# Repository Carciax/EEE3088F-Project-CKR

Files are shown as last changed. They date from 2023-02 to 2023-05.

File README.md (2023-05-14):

# EEE3088F-Project-CKR
#Group number 12
# Students: 
Cameron Clark, CLRCAM007; 
Kian Frassek, FRSKIA001; 
Robert Dugmore, DGMROB001; 

## Table of contents
* Description of HAT
* Getting started
  * Introduction
  * Ordering and assembling a HAT
  * Other hardware requirements
  * Hardware connection
  * Software requirements
  * Basic operation of HAT
  * Licensing

# Description of HAT

This sensor PCB HAT connects to an STM32F0 microcontroller and adds additional sensing functionality in the form of an ambient light sensor, a temperature and humidity sensor, an thermistor, and a potentiometer (which could be connected to some form of mechanical sensing system, e.g., a wind vane). The board can be powered directly from USB, or can be powered by an 18650 battery.

# Getting started

## Introduction

This sensor HAT aims to expand the functionality of an STM32F0 microcontroller by adding various sensors. This getting started guide will go over the minimum hardware and software requirements to connect the HAT and start taking measurements.

## Ordering and assembling a HAT

### Ordering from JLC PCB

The HAT has been designed to meet the specifications from JLC PCB (jlcpcb.com). To order a HAT:
* Go to JLC's website (jlcpcb.com)
* Request a quote
* Upload "Final Submission/GROUP12_gerber.zip" as your gerber files
* Select the board specifications (e.g., colour, finish, etc.) as you like. The default options are a reasonable choice.
* Select the option for single sided assembly
* Follow the website instructions until you are prompted to upload a position file and BOM.
* The position file is "Final Submission/GROUP12_position.cpl", and the BOM file is "FINAL_SUBMISSION/GROUP12_bom.csv".
* When asked about footprints that do not have a part number assigned, select "do not place"
* Follow any further instructions from the website for payment and delivery

### Ordering from another board house

If ordering from JLC PCB is not an option for you, you can use the same gerber, position and BOM files to order your HAT from another board house. However, please note the following:
* The HAT may not meet the specifications of another board house.
* The BOM file is unlikely to be in the correct format for another board house.
* The BOM file is unlikely to contain references to the correct components from another board houses's stock; manual selection of components will probably be necessary.

### Additional steps

All male and female headers will have to be obtained and soldered on separately.

It is also recommended to keep track of the issues page of the github to see if there are any outstanding hardware issues with the current iteration of the HAT, which may require manual intervention to solve. 

## Other hardware requirements

### List of required hardware

In addition to the HAT, the following hardware is required:
* an STM32FO microcontoller, with pins connected to 2 1x24-pin male headers spaced -1.524 mm (0.6 in) apart
* A microUSB-B cable
* A 5V USB power supply
* Optional: An 18650 battery
* A computer with an available USB port running Linux or Windows

## Hardware connection

### Microcontroller

The microcontroller should be directly connected to the double-row of females headers labelled "J3". 

### Battery

The 18650 battery (if being used) can be placed directly into the battery holder, taking care to connect it with the correct polarity. The HAT will automatically cut battery power if the voltage drops too low, to protect the battery.

### USB (power supply and data transfer)

The HAT is powered (and the battery is charged) immediately when 5V power is received from the singular USB port. Connecting the USB to a computer enables the start of data transfer to the computer.

### Battery charging

The 18650 battery is charged by the 5V USB power supply. 
The HAT includes red and green charging LEDs. The red LED is powered when the battery is charging, and the green LED is powered when the battery is fully charged.

## Software requirements

### STM32F0 Firmware

The firmware from this repository takes measurements from all sensors at a soft-configurable regular interval. This will need to be uploaded to STM32F0 board.

### Required PC software

The default firmware outputs value over USB serial and requires no additional software.

## Basic operation of HAT

### Reading data on the pc

Data is saved to the EEPROM by default. To send all EEPROM data over the USB connection:
* Connect the USB
* Press switch 1
* LED 1 will flash until all data has been sent
* To abort, press switch 1 again.

### Configuring data read rate

Under normal operation, the HAT takes 1 reading every 60 seconds. This can be soft-configured as follows:
* Press switch 2
* LED 2 will start to flash
* Turn the potentiometer to a desired reading level
* Press 2 again to confirm

## Licensing
MIT License

Copyright (c) 2023 Kian Frassek, Cameron Clark, Robert Dugmore

Permission is hereby granted, free of charge, to any person obtaining a copy
of this software and associated documentation files (the "Software"), to deal
in the Software without restriction, including without limitation the rights
to use, copy, modify, merge, publish, distribute, sublicense, and/or sell
copies of the Software, and to permit persons to whom the Software is
furnished to do so, subject to the following conditions:

The above copyright notice and this permission notice shall be included in all
copies or substantial portions of the Software.

THE SOFTWARE IS PROVIDED "AS IS", WITHOUT WARRANTY OF ANY KIND, EXPRESS OR
IMPLIED, INCLUDING BUT NOT LIMITED TO THE WARRANTIES OF MERCHANTABILITY,
FITNESS FOR A PARTICULAR PURPOSE AND NONINFRINGEMENT. IN NO EVENT SHALL THE
AUTHORS OR COPYRIGHT HOLDERS BE LIABLE FOR ANY CLAIM, DAMAGES OR OTHER
LIABILITY, WHETHER IN AN ACTION OF CONTRACT, TORT OR OTHERWISE, ARISING FROM,
OUT OF OR IN CONNECTION WITH THE SOFTWARE OR THE USE OR OTHER DEALINGS IN THE
SOFTWARE.

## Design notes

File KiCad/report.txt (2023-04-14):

Info: Reading netlist file 'C:\Users\Kian\OneDrive - University of Cape Town\Desktop\uct\3 year\frirst semester\EEE3088\EEE3088F-Project-CKR\KiCad\report.net'.

Info: Using reference designators to match symbols and footprints.

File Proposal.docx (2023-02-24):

1) The HAT will be used as a low power temperature sensor which can be used to log temperatures and give alerts when the temperature exceeds or goes below configurable threshold temperatures.

The attachments will be a digital temperature sensor, a potentiometer and basic I/O (LEDs and pushbuttons). The HAT will also include additional breakout pins which users can connect additional output devices to (for temperature alerts), and which will allow connection to a device that logs temperatures.

The device could be used in a variety of situations, including personal weather logging, home agriculture, machinery/manufacturing temperature monitoring, student research, and office monitoring.

The potentiometer will be used for configuration of the device, such as to set threshold temperatures and change sensor frequency.

User/Use case | User Description
Personal weather monitoring | Someone who wants to keep track of the temperature in their own home over time, or who want to be alerted when certain temperatures are reached
Requirements | More detail
Configurable "alert" temperature | Ability to change the temperature level/s at which the board will send an "alert" signal
Basic output for configuration | LEDs on the board that allow visual feedback for the u
Breakout pins for additional "alert" output | User might want to connect an aditional/different output for temperature alerts, e.g. a buzzer or a switch for an alarm

User/Use case | User Description
Agriculture | Monitoring of a home greenhouse or houseplants
Requirements | More detail
Ability to mount a case | Requires mounting holes so that user can add a protective case, e.g. to protect from moisture in a greenhouse
Temperature logging | Requires an output that users can connect to a storage device to log temperature over time

User/Use case | User Description
Machinery/Manufacturing | Monitoring of a workspace containing temperature sensitive machinery
Requirements | More detail
Breakout pins for additional "alert" output | Users may want to configure the board to automatically take some action upon temperature "alert", e.g., turn on additional room cooling
Temperature logging | Same as above
Highly configurable "alert" levels | Machinery may need to take actions at many different temperature levels, e.g., turn fans up or down

User/Use case | User Description
Research | E.g., a student doing a project tracking temperatures in a remote location
Requirements | More detail
Temperature logging | Same as above
Power efficient | Researchers may need to leave the device running for a long time without charging/manual intervention
Breakout pins for additional "alert" output | Same as above

User/Use case | User Description
Office monitoring | E.g., to track temperature alongside separate tracking of energy usage from fans/airconditioning
Requirements | More detail
Temperature logging | Same as above

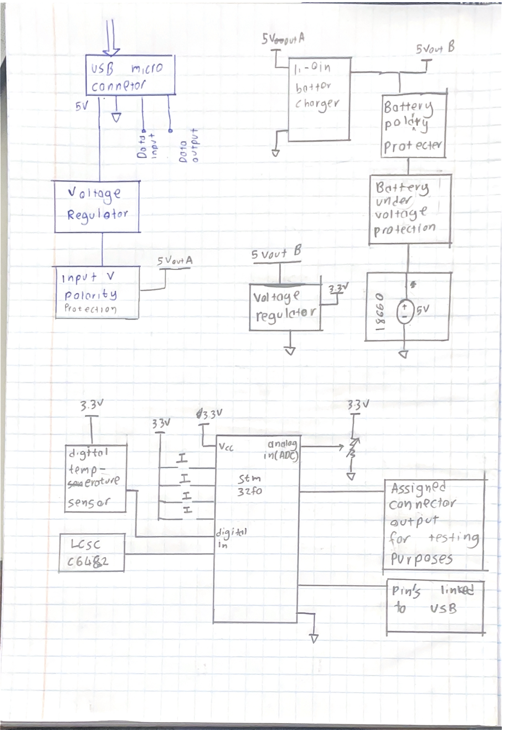
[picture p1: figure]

4) https://github.com/Carciax/EEE3088F-Project-CKR

EEE3088F Project Proposal 24 Feb 2023 CLRCAM007 FRSKIA001 DGMROB001

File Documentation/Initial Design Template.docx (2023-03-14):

Q1: GitHub

https://github.com/Carciax/EEE3088F-Project-CKR

Q2: Power Subsystem Failure Management

i) I am going to put 0 ohm resistors over each component so that we can use the available connections points to bypass any broken components. I have put pins to connect an external 3V3 power source.

ii) I will ensure to use the correct size to the appropriate current rating for each track to protect against track damage.

I will also make the ground track thick.

iii) I will provide other options to replace components or go and buy the components from other shops and solder them on. I will also ensure to use components with large quantities of stock decreasing the chance of the component running out.

iv) I will make the circuit as modular as possible allowing for changes to the circuit as well as providing lots of available connection points to make modifications post PCB development.

Q3: Sensing Subsystem Failure Management

Each I/O trace will be connected to two separate pins on the microcontroller. Each trace will have a 0Ω resistor between the sensor pin and the microcontroller pin, but one of these 0Ω resistors will be DNP. This will allow a different microcontroller pin to be used in the event that one fails. These connections are shown on the microcontroller schematic.

The l main power line will also be populated with a 0Ω, to allow the entire module to be disconnected from power in the instance that a design error and/or circuit damage within the sensor module leads to a short.

If the 0Ω resistors have to be de-soldered, their pads can be used to solder a wire directly to another pin on the microcontroller.

Finally, the design includes 2 analogue sensors (a potentiometer which can be connected to some small mechanical device, and a thermistor), and 2 digital sensors (an ambient light sensor and a temperature/humidity sensor). Best case scenario, this means that the HAT is multi-faceted and can serve a variety of different research purposes. However, in the event of of component/design failure or inadequate component stock, the HAT will hopefully still have other functioning sensors and thus will still be useful. It is specifically useful that there are 2 different temperature sensors, given that our original examination of use cases for the HAT placed on a strong emphasis on the HAT’s ability to sense temperature.

Q4: Microcontroller Subsystem Failure Management

For individual component failure, components will be connected into the circuit by some means that it can be disconnected. Components that are likely to fail will get jumpers which can be easily remove and another component can be connected from an external board.

Components that are less likely to fail will get two pads soldered together in line with the component. These can easily be soldered and de-soldered, and the signal can be measured in that line. Lastly, components that are likely never going to fail will get 0Ω resistors which can be taken out and/or rerouted to other lines.

Power and controls:

The power and ground of the microcontroller has solder pads in place to ensure that the microcontroller can function without the power and sensors. The debugger input is already a pin header and thus can be plugged – which also means that the NSRT reset pin has a pin header that can be easily accessed to reset the microcontroller. There are enough redundant push buttons that failure management is unnecessary. The BOOT0 or boot mode pin has a solder pad in case the board needs to be booted in a different mode.

Sensors and EEPROM:

The digital sensors inputs and the EEPROM communication lines have 0Ω resistor pairs in place such that they can change between I2C1 and I2C2 communication protocol, and so that there are a pair of lines available for isolated testing of components. The analogue sensors have 0Ω resistor pairs such that they can change between GPIOA and GPIOB reading the value.

Output:

The output USB has a 3 pin header on both Tx and Rx lines such that the USB can be changed between UART1 and UART2 as well as the board can communicate with an external USB setup in case the onboard USB port or differential pair lines to UART chip are damaged. The LED has also been wired with a jumper such that an output signal can be jumped to an external board.

This system of failure management allows for most components to be isolated for testing, redirected in case of line damage, or have signals inputted or outputted to an external board for testing.

Q5: Power Subsystem Schematic

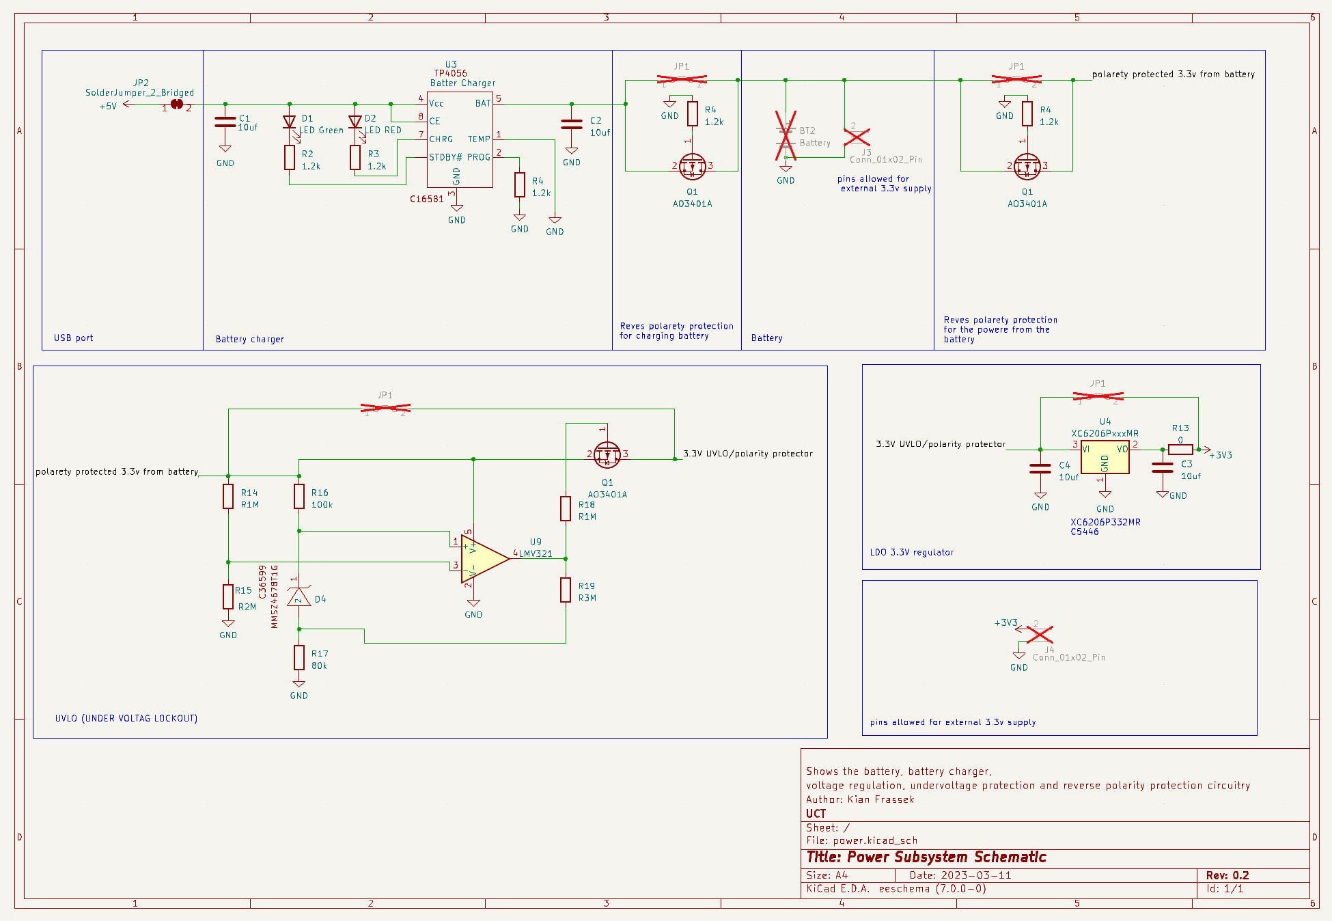
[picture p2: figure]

Q6: Sensing Subsystem Schematic

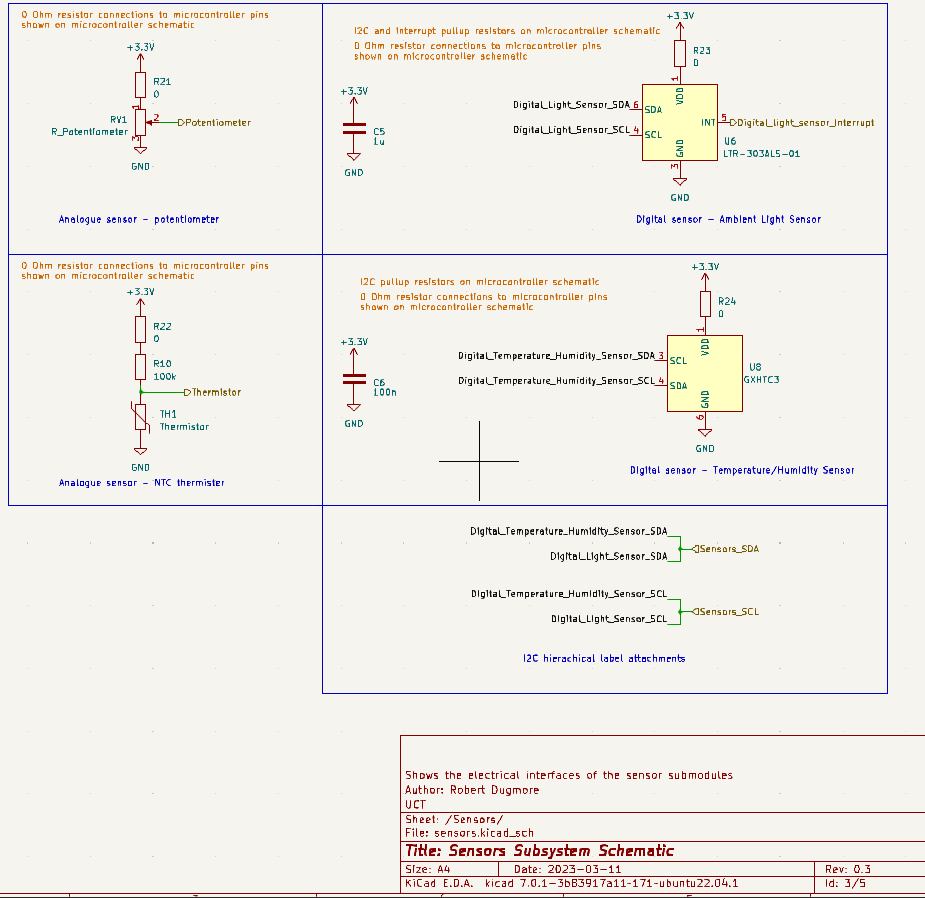
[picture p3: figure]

Q7: Microcontroller Subsystem Schematic

The microcontroller schematic

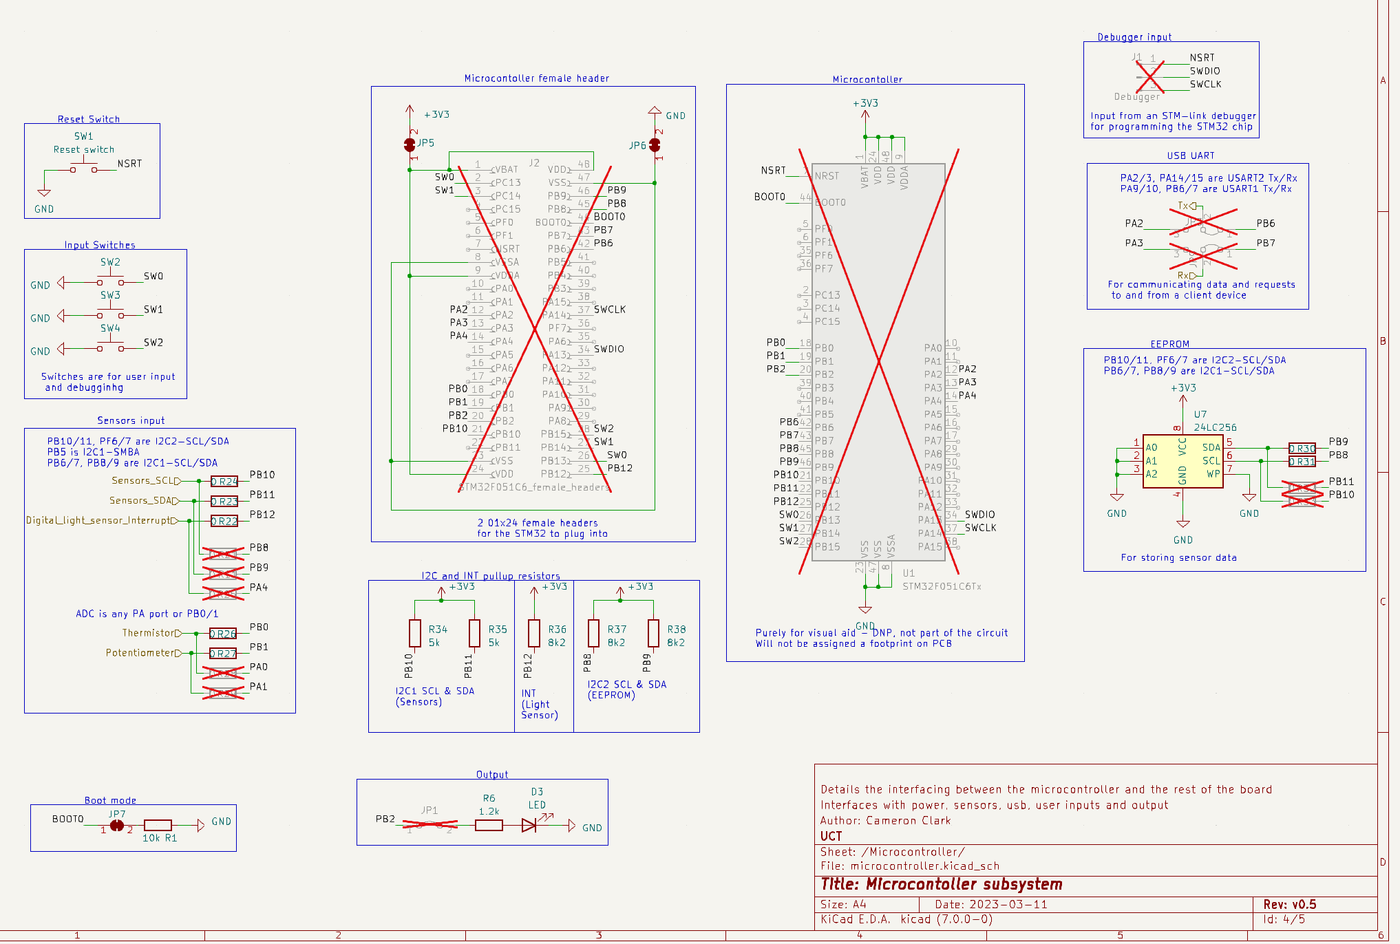
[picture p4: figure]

The USB input schematic

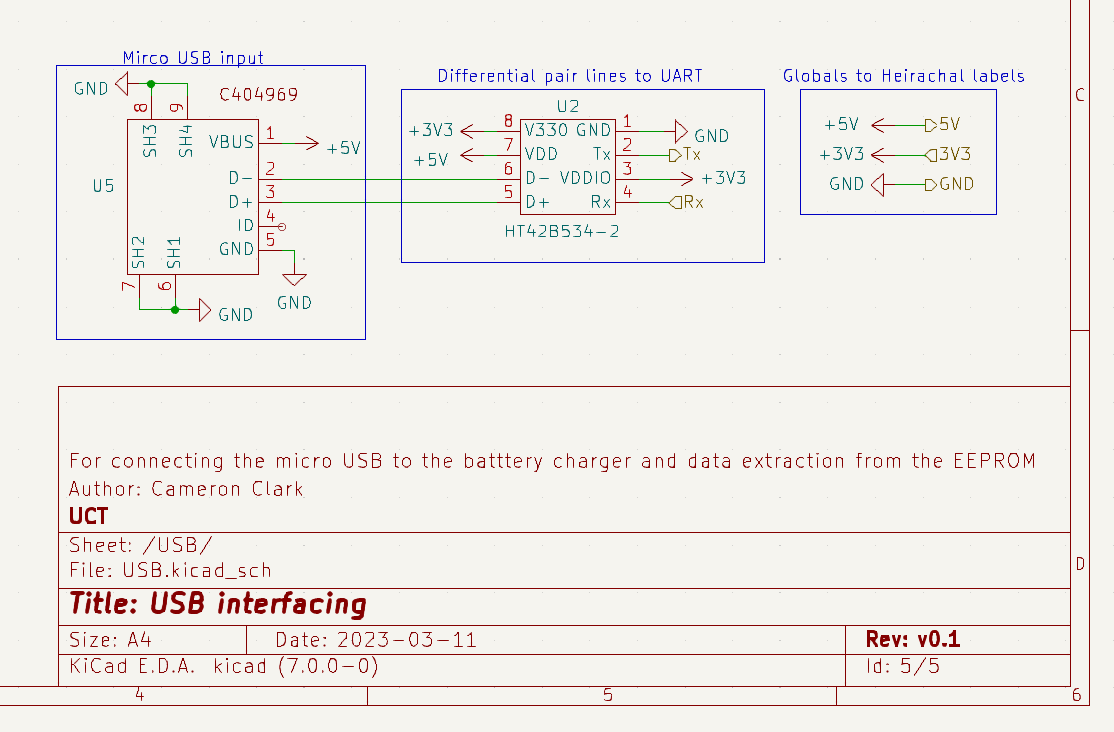
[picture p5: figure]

Q8: Planned ERCs

- Make sure the 5V and 3V3 and GND labels aren’t short circuit to each other.
- Make sure there are no floating pins.
- Make sure the power running through resistor doesn’t exceed their maximums.
- Make sure power lines do not go through traces that are too thin.
- Perform the ERC on KiCad.
- Follow all the rules on JCL components specification for board design.

Q9: Updated BOM

https://github.com/Carciax/EEE3088F-Project-CKR/blob/main/Budgeting/Budgeting.xlsx

CLRCAM007 FRSKIA001 DGMROB001

EEE3088F-Project 11 Mar. 23

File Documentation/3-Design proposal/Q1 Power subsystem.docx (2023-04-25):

I Kain frassek declare I did not plagiarize to get any of this information in section 1.

Week 3

Q 1.1

Specification

USB input | This must be a micro-USB input. It must be able to output between 4.5 and 5.5 volts which can then be used to charge the battery. It will need to be able to withstand high temperatures such as up to 80 degrees Celsius.
battery charger | The battery charger must be able to take the 5 Volt voltage source from the micro USB and charge the battery. It will indicate when the battery is fully charged using a green LED and when the battery is still charging using a red LED. It must also be able to withstand temperatures up to 80 degrees.
Undervoltage lockout | This must be connected to the lithium-ion battery. It must ensure that if the voltage provided by the battery goes below 3.3 volts no voltage is provided to the main circuit.
Battery | This must be a lithium ion battery that fits into the BH-18650-B1BA002 (https://jlcpcb.com/partdetail/Myoung-BH_18650B1BA002/C2988620) holder. It must be a 3.3 Volt battery. It must be able to withstand temperatures around 80 degrees Celsius.
Battery terminal pins | These need to be 2 pins that can be used to provide 3.3 volts to the main circuit in case the battery is not available or for testing purposes.
Reverse polarity protection circuits | This must be connected to the battery. It must be able to detect whether the batteries polarity has been swapped or if the polarity at which the battery is being charged is in the wrong direction. If the polarity in either case has been swapped it must prevent the main circuit and battery, from being powered or charged by this voltage.
3.3 Volt regulator | This circuit must be able to take the voltage from the battery which will be 3.3 volts or higher and regulate it so that a constant 3.3 volts is supplied. This can then be used to power our circuit reliably.

Q1.2

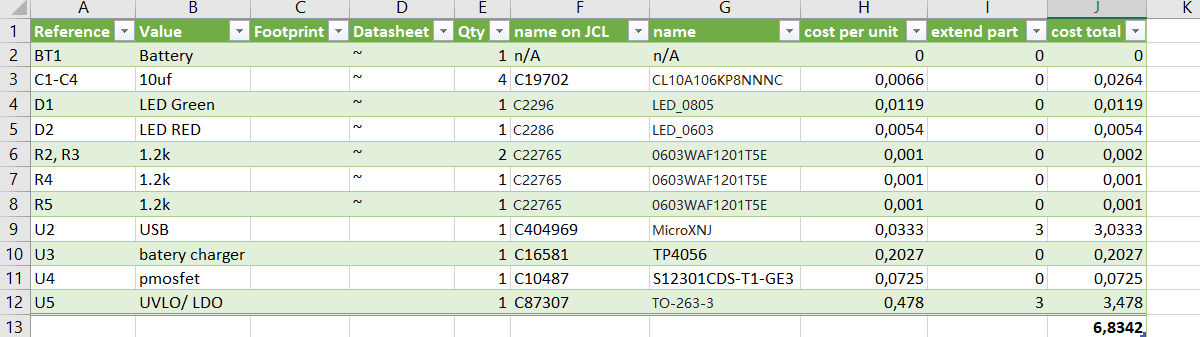
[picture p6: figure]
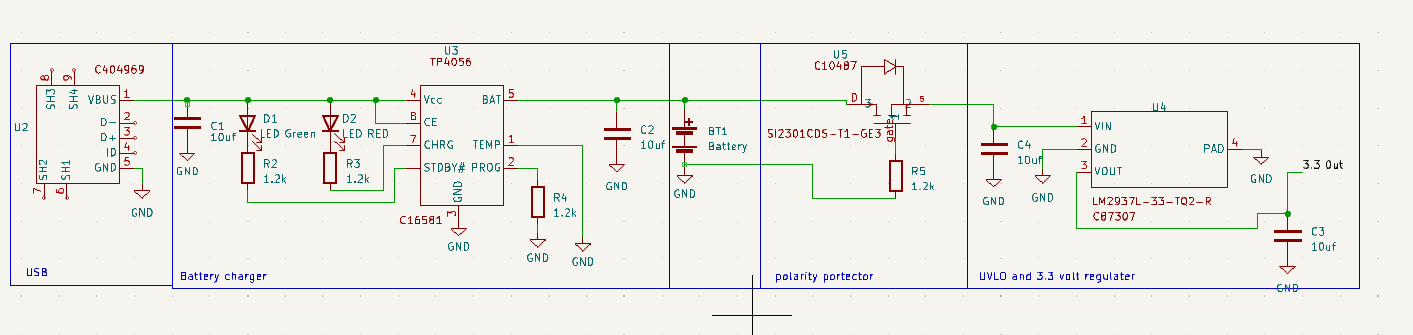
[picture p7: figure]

Q.1.3

Submodule interface

LED is used to indicate the charging of the battery. | one green LED and one red LED. Both in series with 1.2 KΩ resistors to reduce current.
STM32F051C6Tx | This is the main microprocessor board which will need to be supplied with 3.3 volts. current used to power itself is between 3 and 4.5 milliamps.
Potentiometer analog sensor | This will be supplied with 3.3 volts and will act as a voltage divider. It will draw 33 milli amps of power.
digital light sensor | This will be supplied 3.3 volts. And will draw a very low current.
Outputs via LED | There will be an LED powered by the 3.3 volts which can be used to flash at different rates and help give outputs about what has been sensed. These LED's will be put in series with large resistors to help reduce current.
Debug (SIL 1x10 Male) | This will need a 5 Volt power supply and therefore it will need to be supplied straight from the USB port.
Analogue sensor 2 thermister | This will need 3.3 V power supply and should draw les that 1 mw of power.
USB connector | Will supply 5V to the main power circuit. An external USB cable will be connected to provide this power and for data transmission

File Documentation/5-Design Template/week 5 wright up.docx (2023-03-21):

# Week 5: PCB design template

Q1: Github

https://github.com/Carciax/EEE3088F-Project-CKR

Q2: Power subsystem failure management

i) Going to put populate zero ohm resistance in series with each modular component and unpopulated zero ohm resistor over each modular component allowing me to bypass each modular component by desoldering the populated 0 ohm resistor and resoldering the unpopulated resistor. I'm also going to put lots of test points which are going to be through holes which give me the ability to connect wires later on. I will also put jumpers next to the battery and at the 3V3 out and ground allowing us to connect an external 3.3 volts either in place of the battery or just to the main circuit.

ii) I will ensure to use the correct size track to the appropriate current rating for each track to protect against track damage.

I will also make the ground track thick as well as making ground its own level on the board.

iii) I will provide other options to replace components or go and buy the components from other shops and solder them on. I will also ensure to use components with large quantities of stock decreasing the chance of the component running out.

iv) I will make the circuit as modular as possible allowing for changes to the circuit as well as providing lots of available connection points to make modifications post PCB development.

The plans for failure management for this subsystem were unchanged; the update schematic below implements these plans.

Q3: Sensing subsystem failure management

i)

Each I/O trace will be connected to two separate pins on the microcontroller. Each trace will have a 0Ω resistor between the sensor pin and the microcontroller pin, but one of these 0Ω resistors will be DNP. This will allow a different microcontroller pin to be used in the event that one fails. These connections are shown on the microcontroller schematic.

This was implemented as described.

ii)

The l main power line will also be populated with a 0Ω, to allow the entire module to be disconnected from power in the instance that a design error and/or circuit damage within the sensor module leads to a short.

Since the previous schematic revision, PMOSFET switches were added to allow each sensor’s power supply to be individually controlled. Populated 0 ohm resistors were placed at the power supply of each PMOSFET, and DNP 0 ohm resistors that bypass the PMOSFETS and power the sensors directly were added, to account for errors or failure in the switching circuits.

iii)

If the 0Ω resistors have to be de-soldered, their pads can be used to solder a wire directly to another pin on the microcontroller.

Through-hole test points were added to the schematic; these enable easy testing of the circuit and are easier to manually solder wires to than 0 ohm resistor pads.

iv)

Finally, the design includes 2 analogue sensors (a potentiometer which can be connected to some small mechanical device, and a thermistor), and 2 digital sensors (an ambient light sensor and a temperature/humidity sensor). Best case scenario, this means that the HAT is multi-faceted and can serve a variety of different research purposes. However, in the event of of component/design failure or inadequate component stock, the HAT will hopefully still have other functioning sensors and thus will still be useful. It is specifically useful that there are 2 different temperature sensors, given that our original examination of use cases for the HAT placed on a strong emphasis on the HAT’s ability to sense temperature.

This was able to be implemented within budget and thus was kept. The PMOSFET power switches described previously minimise the additional power draw brought about by having additional sensors.

Q3: Microcontroller interfacing failure management

For individual component failure, components will be connected into the circuit by some means that it can be disconnected. Components that are likely to fail will get jumpers which can be easily remove and another component can be connected from an external board.

Components that are less likely to fail will get two pads soldered together in line with the component. These can easily be soldered and de-soldered, and the signal can be measured in that line. Lastly, components that are likely never going to fail will get 0Ω resistors which can be taken out and/or rerouted to other lines.

It was decided to consistently use 0 ohm resistors instead of jumpers or solder pads. The 0 ohm resistors were chosen with a large physical size such to make manual soldering and de-soldering easier.

Power and controls:

The power and ground of the microcontroller has solder pads in place to ensure that the microcontroller can function without the power and sensors. The debugger input is already a pin header and thus can be plugged – which also means that the NSRT reset pin has a pin header that can be easily accessed to reset the microcontroller. There are enough redundant push buttons that failure management is unnecessary. The BOOT0 or boot mode pin has a solder pad in case the board needs to be booted in a different mode.

Besides the decision described above to use 0 ohm resistors instead of jumpers or solder pads, this was implemented as described.

Sensors and EEPROM:

The digital sensors inputs and the EEPROM communication lines have 0Ω resistor pairs in place such that they can change between I2C1 and I2C2 communication protocol, and so that there are a pair of lines available for isolated testing of components. The analogue sensors have 0Ω resistor pairs such that they can change between GPIOA and GPIOB reading the value.

This was implemented as described.

Output:

The output USB has a 3 pin header on both Tx and Rx lines such that the USB can be changed between UART1 and UART2 as well as the board can communicate with an external USB setup in case the onboard USB port or differential pair lines to UART chip are damaged. The LED has also been wired with a jumper such that an output signal can be jumped to an external board.

USB/UART connections were implemented as described. The LED connection was changed from a jumper to a 0 ohm resistor. A through-hole test point was added which will allow a wire to be manually soldered if the connection needs to be jumped to another board. A second LED was also added in case of LED failure.

This system of failure management allows for most components to be isolated for testing, redirected in case of line damage, or have signals inputted or outputted to an external board for testing.

Q5: Power subsystem schematic

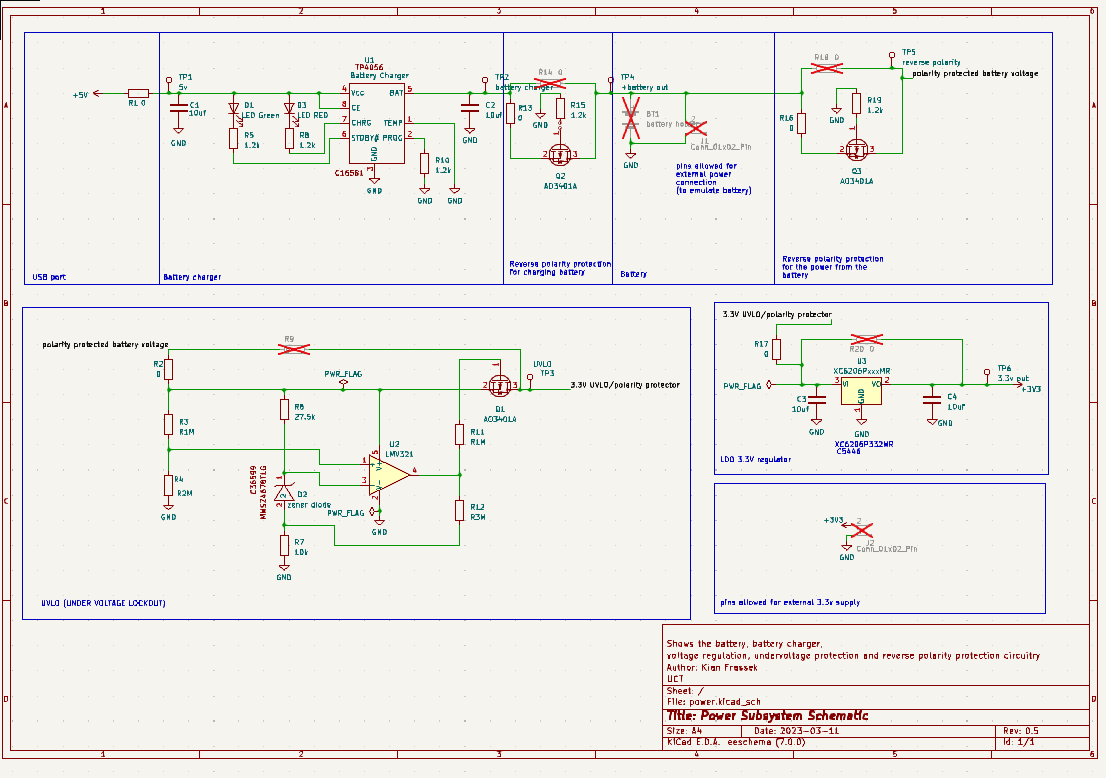
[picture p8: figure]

Some changes were made to resistance values as they were wrong. Test points were added throughout the circuit which will provide opportunities to test as well as solder on wires if needed. I have also added unpopulated and populated 0 ohm resistors over each modular component so that we can remove and add modular components as we want.

Q6: Sensing subsystem schematic

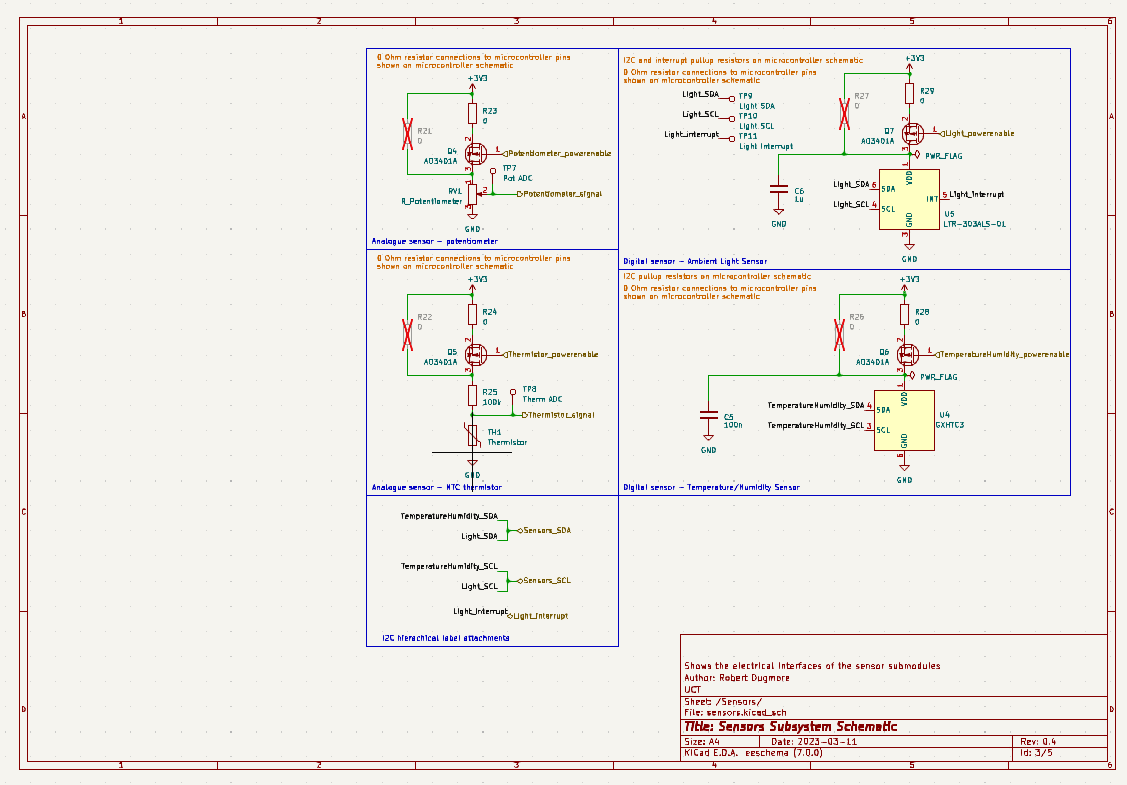
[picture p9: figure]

PMOSFET switching circuits were added to each sensor to allow the power to be enabled or disabled individually.

Test points were added to allow testing of the circuit or allow wires to be manually soldered between various components if necessary.

DNP 0 ohm resistors bypassing the PMOSFET switches were added to allow direct powering of sensors if necessary.

Net labels were renamed for clarity.

Q7: Microcontroller interfacing schematic

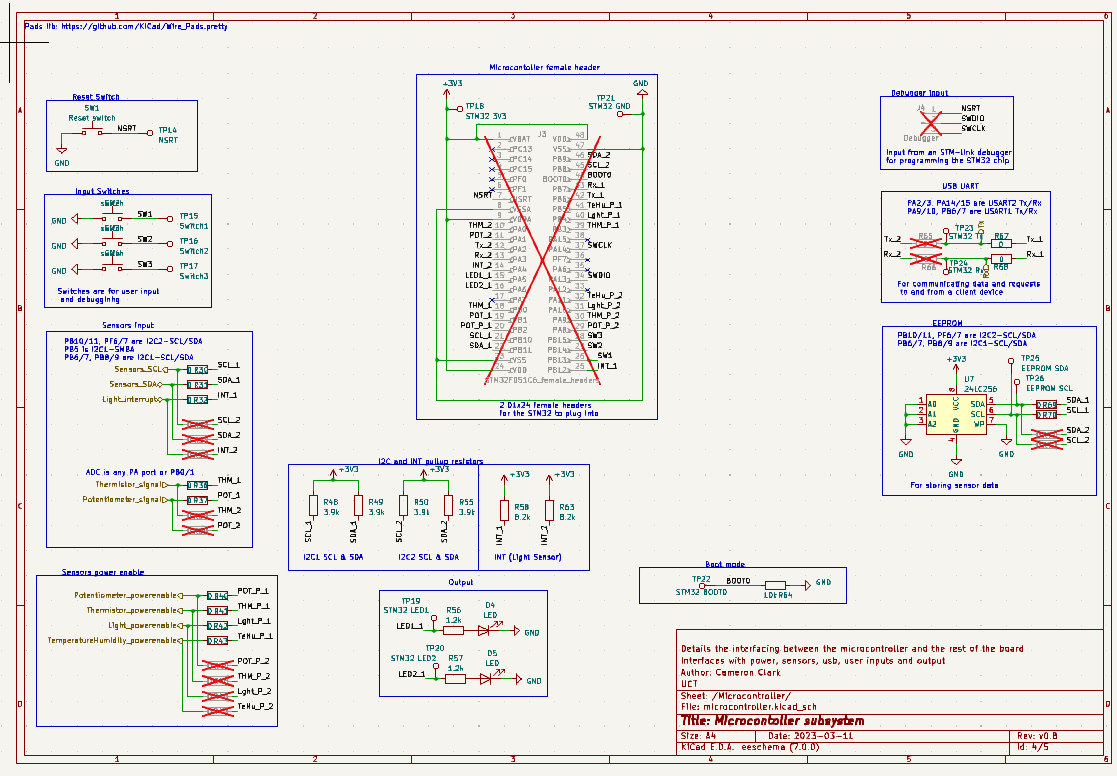
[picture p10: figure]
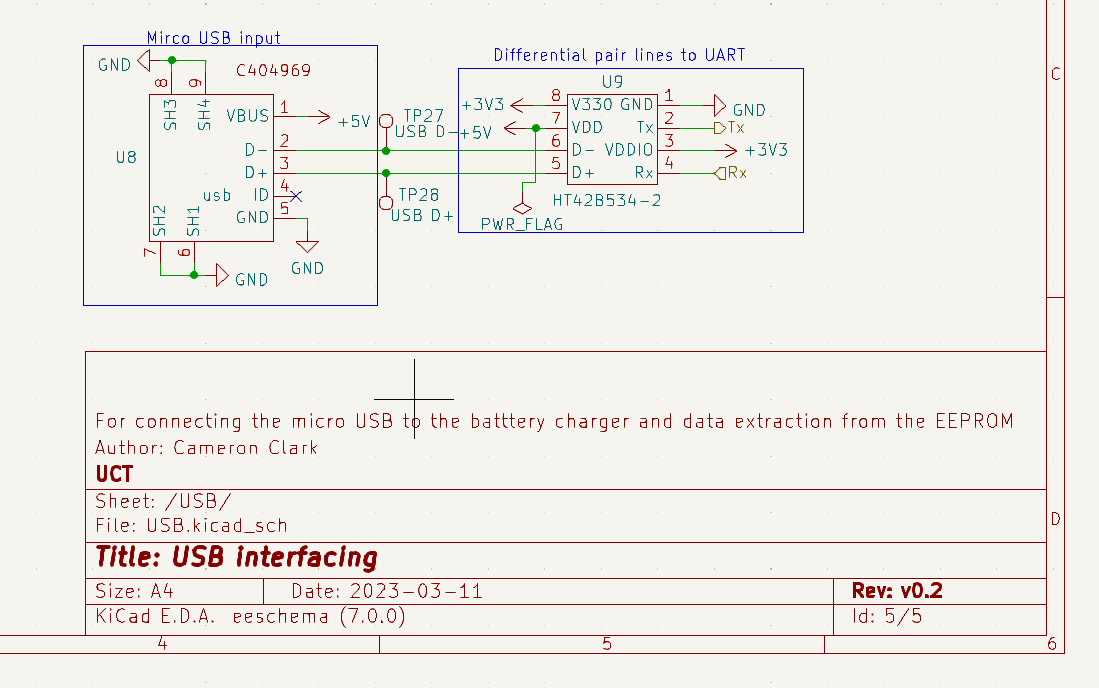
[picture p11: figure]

Connections to the PMOSFET switches on the sensors subsystem were added to allow the sensor power to be enabled/disabled via GPIO.

The failure management system was updated to use exclusively 0 ohm resistors instead of a mixture of these and jumpers/solder pads.

Test points were added to allow testing of the circuit or allow wires to be manually soldered between various components if necessary.

EEPROM was connected to I2C1 by default (instead of I2C2), and I2C pullup resistances were recalculated and changed.

Previously a component diagram of the actual micrcontroller board had been included for visual reference – this was removed entirely.

A second output LED was added.

Net labels were renamed for clarity.

Q8: Updated ERCs

ERCs used were:

- Make sure the 5V and 3V3 and GND labels aren’t short circuit to each other.
- Make sure there are no floating pins.
- Make sure the power running through resistor doesn’t exceed their maximums.
- Make sure power lines do not go through traces that are too thin.

Screenshot of ERC report with no errors:

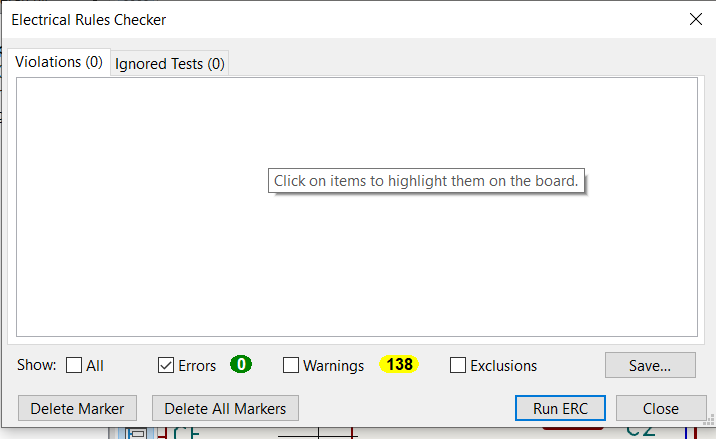
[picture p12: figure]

The 138 warnings are because a large number of wires in the schematic are off-grid.

Q9: DRCs

DRCs used were:

Minimum distance between tracks

Check that all pads are connected to the correct nets

Check for thermal violations (GND pins must be connected to the GND plane with at least 2 spokes)

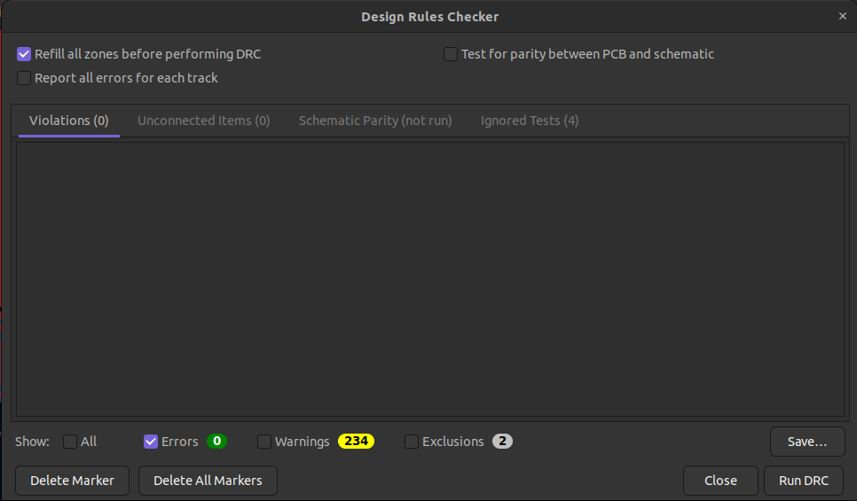
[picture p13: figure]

The 2 exclusions were:

- A GND pin on an IC that was unable to be connected to multiple GND spokes due to the physical layout of the IC pins
- A GND pin on the microcontroller header which was flagged for only connecting to 1 GND spoke on front copper even though it was connected to 2 spokes on the back copper.

The warnings were silkscreen overlaps and were not of concern.

Q10: BOM

https://github.com/Carciax/EEE3088F-Project-CKR/blob/main/Budgeting/EEE3088F_CKR.csv

The estimated budget (exlcluding manufacturing cost) is $56.50. We are account for an ~$12.00 manufacturing cost (board and assembly), and thus are still within our budget.

Q11: PCB design

Front copper layer:

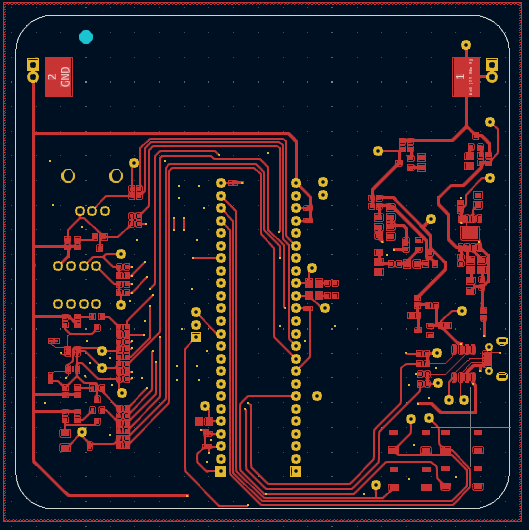
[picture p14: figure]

Front copper layer with GND plane shown:

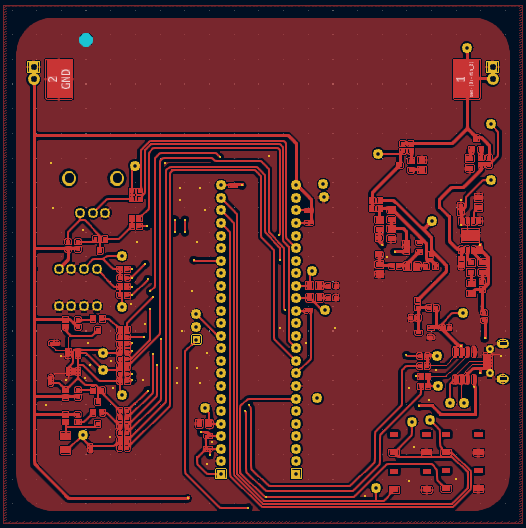
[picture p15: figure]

The lightly-shaded area is the GND plane.

0.6mm tracks were used for power lines, 0.4mm tracks were used elsewhere. For some ICs with small pads, 0.25mm tracks were used in small sections.

Back copper layer:

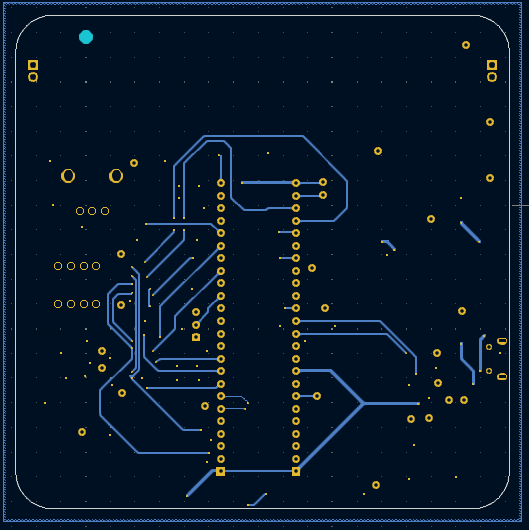
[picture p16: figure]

Back copper layer with GND plane shown:

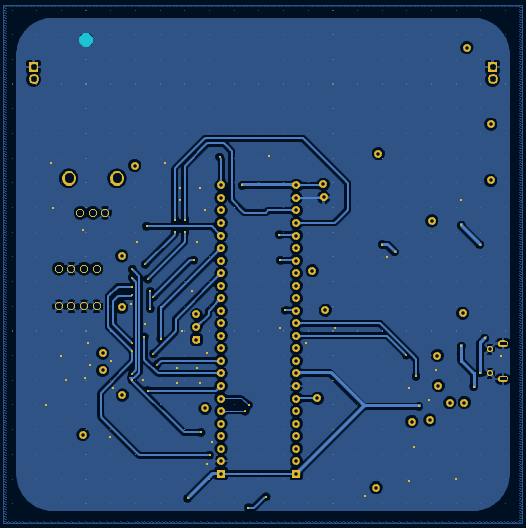
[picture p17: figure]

The lightly-shaded area is the GND plane.

0.6mm tracks were used for power lines, 0.4mm tracks were used elsewhere. For some ICs with small pads, 0.25mm tracks were used in small sections.

Front silkscreen:

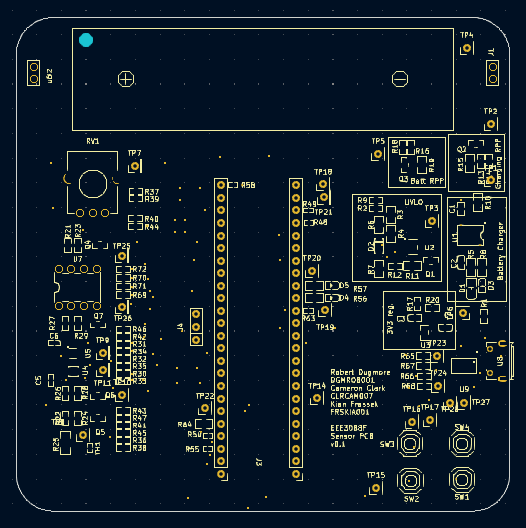
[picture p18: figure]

Note that the USB was intentionally allowed to stick slightly off the edge of the board to make it easy to plug in to.

Back silkscreen has not been shown as it was left empty.

All layers shown:

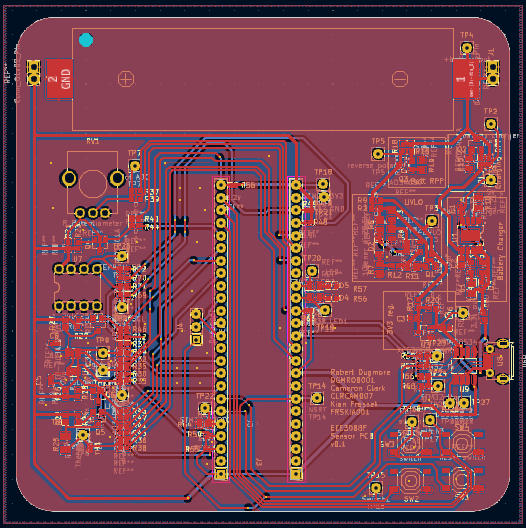
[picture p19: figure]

3D view:

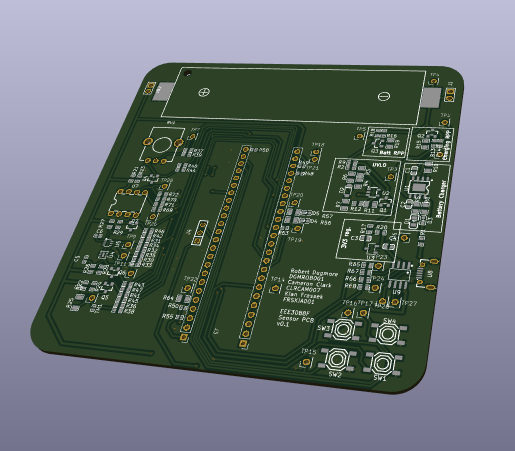
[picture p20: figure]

Link to gerber files:

https://github.com/Carciax/EEE3088F-Project-CKR/blob/main/Gerbers

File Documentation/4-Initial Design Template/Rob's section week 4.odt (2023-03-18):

Each I/O trace will be connected to two separate pins on the microcontroller. Each trace will have a 0Ω resistor between the sensor pin and the microcontroller pin, but one of these 0Ω resistors will be DNP. This will allow a different microcontroller pin to be used in the event that one fails. These connections are shown on the microcontroller schematic.

The l main power line will also be populated with a 0Ω, to allow the entire module to be disconnected from power in the instance that a design error and/or circuit damage within the sensor module leads to a short.

If the 0Ω resistors have to be de-soldered, their pads can be used to solder a wire directly to another pin on the microcontroller.

Finally, the design includes 2 analogue sensors (a potentiometer which can be connected to some small mechanical device, and a thermistor), and 2 digital sensors (an ambient light sensor and a temperature/humidity sensor). Best case scenario, this means that the HAT is multi-faceted and can serve a variety of different research purposes. However, in the event of of component/design failure or inadequate component stock, the HAT will hopefully still have other functioning sensors and thus will still be useful. It is specifically useful that there are 2 different temperature sensors, given that our original examination of use cases for the HAT placed on a strong emphasis on the HAT’s ability to sense temperature.

Temperature & humidity sensor: C2837688

What did you do in the past week?

- Added a temperature/humidity sensor to the sensor schematic

- Revamped net labelling system on schematics

- Error-checked and assisted other team members with the power and microcontroller submodules

What do you plan to do in the coming week?

- A bulk amount of the PCB design, given that I enjoy it and have had less work than the others so far

- A budget review to make sure we can actually afford all the sensors

- Any necessary final edits to the schematics

What might prevent you from doing things?

- Very busy next week (tests). Can mitigate with good time management

- Load shedding makes working difficult. Will plan around the load shedding schedule.

- Budget constraints might require some minor sensor submodule redesign. Will plan this in in case it is necessary.

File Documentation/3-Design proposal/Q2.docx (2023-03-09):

I, Cameron Clark, declare I did not plagiarize to get any of this information in section 2.

Q2.1

Microcontroller specifications. It must be able to:

- Receive 3v3 of voltage into pins 1, 9, 24, 28.
- Connect to ground on pins 8, 23, 47.
- Not exceed an input voltage of 4V
- Not exceed an input or output current of 25mA.
- Receive an input into pin 7 (NSRT) to reset and run the loaded program.
- Receive inputs into pins 7, 34, 37 (NSRT, PA13, PA14) for programming the chip using the debugger.
- Receive a grounded input into pin 44 (BOOT0) to configure the boot mode of the chip.
- Output 3V3 to a GPIO pin
- Receive a read using an ADC a variable voltage.
- Receive data through an IC1/2 enabled pin.

Q2.2

BOM

https://github.com/Carciax/EEE3088F-Project-CKR/tree/main/Budgeting/BOM.xlsx

Components for the microcontroller are indexed 6, 7, 8, 12 and 13 which are an LED, 01x03 male connector, 10k resistor, a button, and the 2 01x24 female headers.

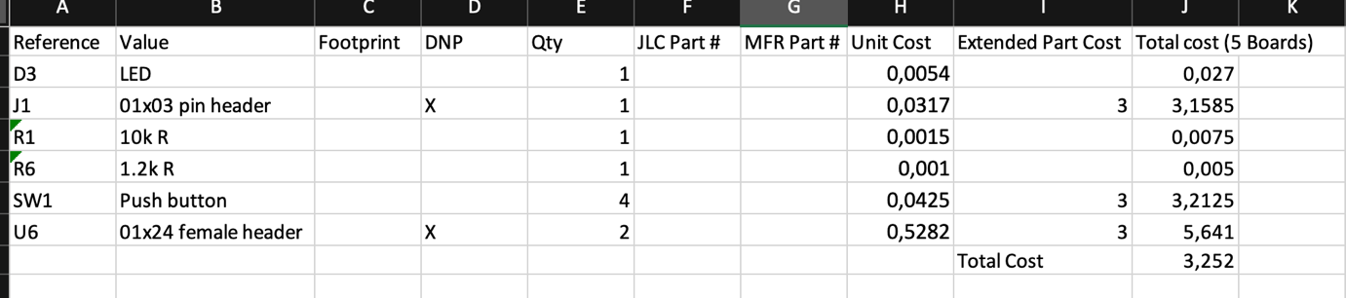
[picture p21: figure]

Total cost estimated as $3.25.

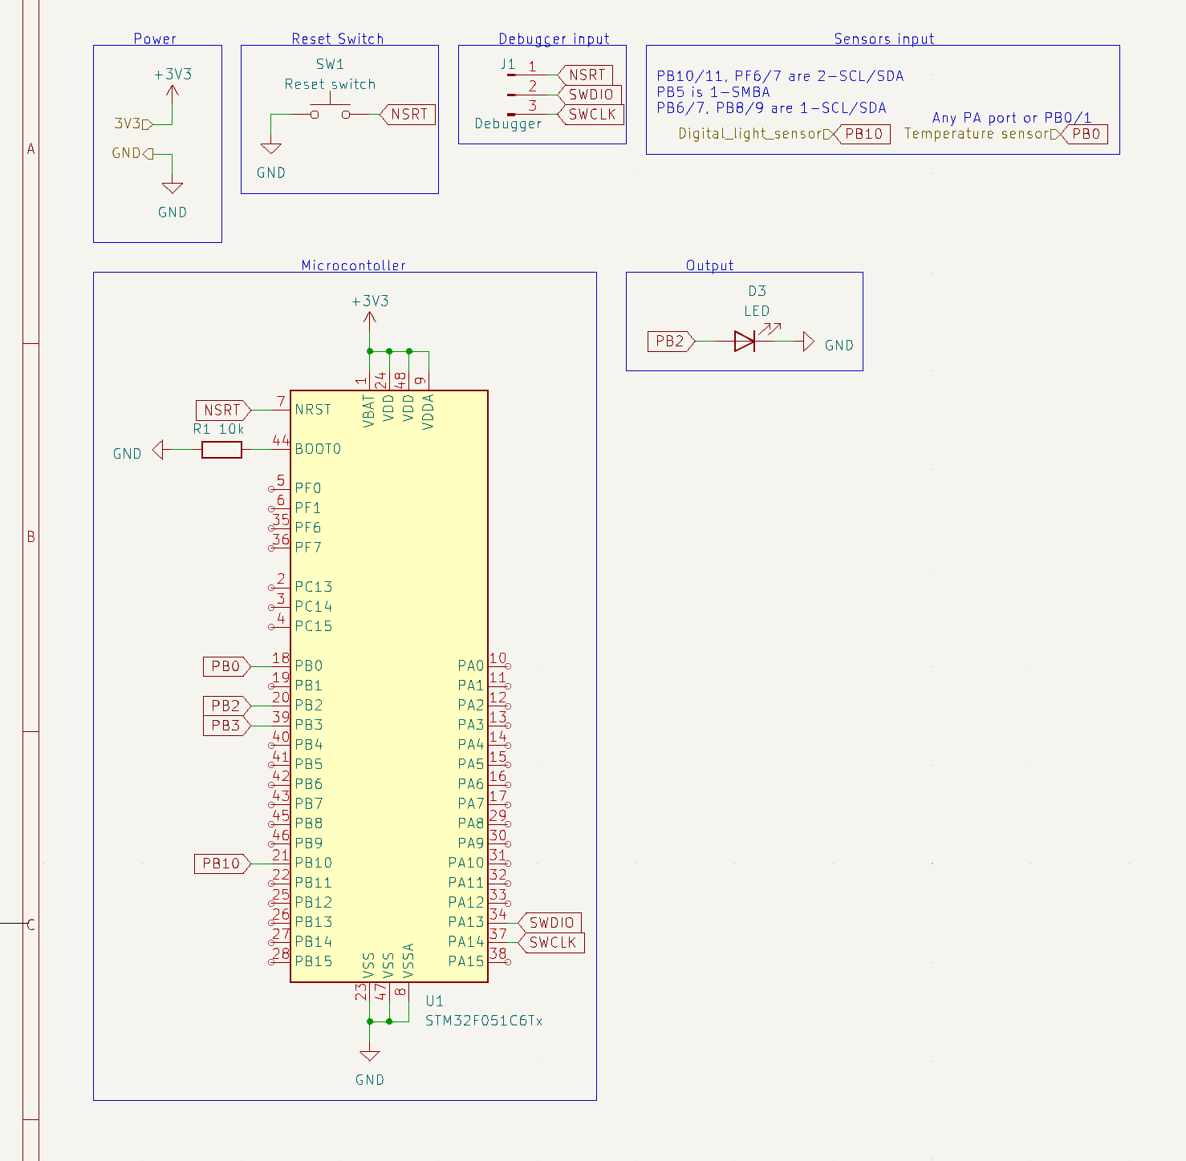
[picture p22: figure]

Q2.3

Inputs

A push button will be used as a reset switch receive by the NRST pin 7. This will have a pulldown resistor internally configured. It will be used to start the program in the machine.

It should receive a 3V3 volts from the power module and a max current of 4.5mA

Sensors

This module will receive a voltage from a thermistor in the range of 0 – 3V3. It will use an GPIOA pin or GPIOB pin 0/1 to input the voltage as these can be ADC enabled.

It will also receive data from a digital light detector sensor which will be receive by GPOIB5-11 or GPIOF6/7.

Outputs

This will output to a singular debug LED outputting 3V3 from any GPIOA/B pin. This will help the user debug the board and set it up.

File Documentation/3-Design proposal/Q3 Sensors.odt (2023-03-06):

I, Robert Dugmore, declare that I did not plagiarise anything in my authored section (Q3)

Digital sensor specifications:

I2C Ambient Light sensor

Specification | Detail
Input Voltage | 3V3
Operating Temperature | -10°C to 70°C
Power Consumption | ≤ 1mW
Output resolution | 16 bit
I2C Slave address bit depth | 7 bit
I2C mode | Fast mode (up to 400 kBits/s)
Light input range | 0.01 lux to 64000 lux
Minimum pull-up resistor value | 1 kΩ
Maximum pull-up resistor value | 10 kΩ
Recommended pull-up resistor value | 8.2 kΩ

The sensor module must take 3V3 power from the main 3V3 rail. It must take a clock input from the microcontroller and output serial data using I2C. It must connect to a level interrupt pin on the microcontroller. It must measure ambient light and output the light level in 16 bit resolution over the I2C connection. The I2C connection must use 7 bit slave addresses and operate in fast mode

Analogue sensor 1 specifications:

Potentiometer

Note: Justin Pead has told us that using a potentiometer as an analogue sensor is acceptable. Nevertheless we have also added a 2nd analogue sensor (see below), which we believe we can still do within the specified budget.

Specification | Detail
Input Voltage | 3V3
Operating Temperature | -10°C to 70°C
Power Consumption | ≤ 1mW
Resistance | ≥ 10 kΩ
Resistance tolerance | ≤ ± 20%
Operating life | ≥ 5000 cycles
Rotation Torque | ≤ 10 mN.m
Maximum rotation angle | ≥ 270°
Mounting type | Vertical

The sensor module must take in 3V3 power from the main 3V3 rail. It must output an analogue voltage based on the degree to which the potentiometer has been turned. It must draw less than 1 mW of power. It must be able to survive up to 5000 cycles.

Analogue sensor 2 specifications:

NTC thermister

Specification | Detail
Input Voltage | 3V3
Power consumption | ≤ 1 mW
Resistance at 25°C | ≥ 10 kΩ
Resistance tolerance | ≤ ± 1%
Measurement temperatures | ≤ -10°C to ≥ 70°C
Nominal B-constant | ≥ 4000
Voltage divider voltage at 25°C | 0.5 x 3V3

The sensor module must take 3V3 power from the main 3V3 rail. The sensor will be placed in series with a 100 kΩ resistor to form a voltage divider. The sensor must be able to read temperatures between -10°C and 70°C.

Draft schematic and BOM:

Schematic:

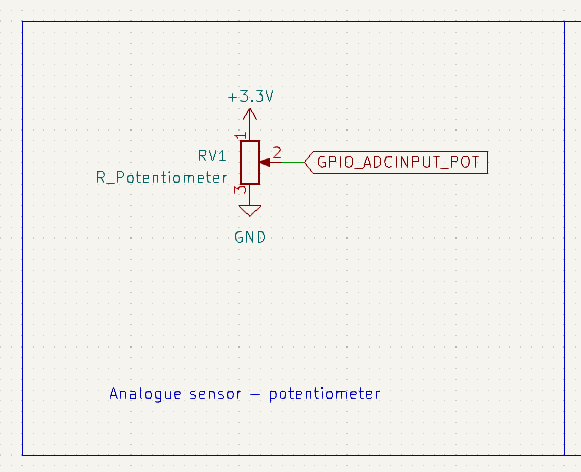
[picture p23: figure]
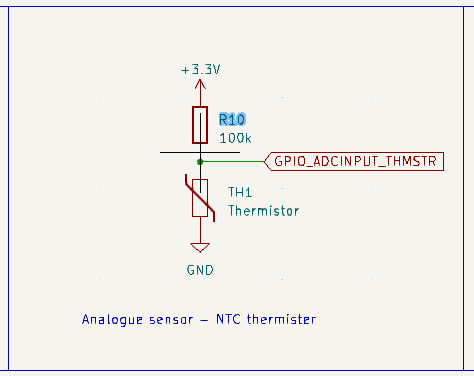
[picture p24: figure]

BOM:

<insert link here>

See sheet 3 (sensors)

The estimated total cost for this module is $14.0170.

Digital sensor interface:

Ambient light sensor

Electrical (pinout):

Pin | Description | Connections
1 | Supply voltage | 3V3 Capacitor +
2 | No connection | NC
3 | Ground | GND Capacitor -
4 | I2C serial clock (SCL) | SCL pin on microcontroller I2C bus Pull-up resistor to 3V3
5 | Level interrupt | INT pin on microcontroller Pull-up resistor to 3V3
6 | I2C serial data (SDA) | SDA pin on microcontroller I2C bus Pull-up resistor to 3V3

The module will send digital data to the microcontroller via an I2C bus on the microcontroller. All pins will have 0Ω resistors in series with the “main” pin connections so that the sensor can be disconnected in the event that it doesn’t work properly.

All pins will have 0Ω resistors in series with the “main” pin connections so that the sensor can be disconnected in the event that it doesn’t work properly.

Electromagnetic (light):

The module will receive ambient light, which the sensor will internally convert to a digital signal (to be sent out of the module as an electrical signal over I2C)

Sensor dimensions:

Width: 2 mm

Length: 2 mm

Height: 0.7 mm

Analogue sensor 1 interface:

Potentiometer

Electrical (pinout):

Pin | Description | Connection
1 | Supply voltage | 3V3
2 | Output | GPIO pin, configured for ADC input
3 | Ground | GND

The module will send an analogue voltage to a GPIO pin configured for ADC input on the microcontroller.

All pins will have 0Ω resistors in series with the “main” pin connections so that the sensor can be disconnected in the event that it doesn’t work properly.

Tactile input:

The twist-knob of the potentiometer can be turned by hand to change the output voltage. This can be used during the configuration stage to fine tune the settings of the device. Additionally it could be used to sense “human data”, where the readings in the device

Mechanical input:

The twist knob of the potentiometer could also be connected to a small mechanical system that turns the knob. For example, the mechanical input could come from a small wind vane, or from a window where the researcher wants to measure when the window is opened and how wide it is opened.

Sensor dimensions:

Width: 9.8 mm

Length: 12 mm

Height: 15 mm

Knob diameter: 6 mm

Analogue sensor 2 interface:

NTC thermister

Electrical (pinout):

Pin | Description | Connection
1 | Connection to 100 kΩ resistor of voltage divider and ADC input | GPIO pin, configured for ADC input 100 kΩ resister pulled up to 3V3
2 | Ground | GND

The sensor module will send an analogue voltage to a GPIO pin configured for ADC input on the microcontroller.

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

Temperature input:

The thermister reacts to changes in temperature. It is a negative temperature coefficient thermister, which means that its resistance decreases as the temperature increases. This resistance change will be read by placing the thermister in series with a static 100 kΩ resistor to form a voltage divider.

The thermister’s change in resistance with temperature is non-linear. This will be compensated for in software of the microcontroller so that accurate temperature readings can be obtained.

Sensor dimensions:

Width: 0,5 mm

Length: 1 mm

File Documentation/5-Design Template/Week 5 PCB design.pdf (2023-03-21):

# Week 5: PCB design template

## Q1: Github

https://github.com/Carciax/EEE3088F-Project-CKR

## Q2: Power subsystem failure management

i) Going to put populate zero ohm resistance in series with each modular component and unpopulated zero ohm resistor over each modular component allowing me to bypass each modular component by desoldering the populated 0 ohm resistor and resoldering the unpopulated resistor. I'm also going to put lots of test points which are going to be through holes which give me the ability to connect wires later on. I will also put jumpers next to the battery and at the 3V3 out and ground allowing us to connect an external 3.3 volts either in place of the battery or just to the main circuit.

ii) I will ensure to use the correct size track to the appropriate current rating for each track to protect against track damage.

I will also make the ground track thick as well as making ground its own level on the board.

iii) I will provide other options to replace components or go and buy the components from other shops and solder them on. I will also ensure to use components with large quantities of stock decreasing the chance of the component running out.

iv) I will make the circuit as modular as possible allowing for changes to the circuit as well as providing lots of available connection points to make modifications post PCB development.

The plans for failure management for this subsystem were unchanged; the update schematic below implements these plans.

## Q3: Sensing subsystem failure management

i)

Each I/O trace will be connected to two separate pins on the microcontroller. Each trace will have a 0Ω resistor between the sensor pin and the microcontroller pin, but one of these 0Ω resistors will be DNP. This will allow a different microcontroller pin to be used in the event that one fails. These connections are shown on the microcontroller schematic.

This was implemented as described.

ii)

The l main power line will also be populated with a 0Ω, to allow the entire module to be disconnected from power in the instance that a design error and/or circuit damage within the sensor module leads to a short.

Since the previous schematic revision, PMOSFET switches were added to allow each sensor’s power supply to be individually controlled. Populated 0 ohm resistors were placed at the power supply of each PMOSFET, and DNP 0 ohm resistors that bypass the PMOSFETS and power the sensors directly were added, to account for errors or failure in the switching circuits.

iii)

If the 0Ω resistors have to be de-soldered, their pads can be used to solder a wire directly to another pin on the microcontroller.

Through-hole test points were added to the schematic; these enable easy testing of the circuit and are easier to manually solder wires to than 0 ohm resistor pads.

iv)

Finally, the design includes 2 analogue sensors (a potentiometer which can be connected to some small mechanical device, and a thermistor), and 2 digital sensors (an ambient light sensor and a temperature/humidity sensor). Best case scenario, this means that the HAT is multi-faceted and can serve a variety of different research purposes. However, in the event of of component/design failure or inadequate component stock, the HAT will hopefully still have other functioning sensors and thus will still be useful. It is specifically useful that there are 2 different temperature sensors, given that our original examination of use cases for the HAT placed on a strong emphasis on the HAT’s ability to sense temperature.

This was able to be implemented within budget and thus was kept. The PMOSFET power switches described previously minimise the additional power draw brought about by having additional sensors.

## Q3: Microcontroller interfacing failure management

For individual component failure, components will be connected into the circuit by some means that it can be disconnected. Components that are likely to fail will get jumpers which can be easily remove and another component can be connected from an external board.

Components that are less likely to fail will get two pads soldered together in line with the component. These can easily be soldered and de-soldered, and the signal can be measured in that line. Lastly, components that are likely never going to fail will get 0Ω resistors which can be taken out and/or rerouted to other lines.

It was decided to consistently use 0 ohm resistors instead of jumpers or solder pads. The 0 ohm resistors were chosen with a large physical size such to make manual soldering and desoldering easier.

Power and controls:

The power and ground of the microcontroller has solder pads in place to ensure that the microcontroller can function without the power and sensors. The debugger input is already a pin header and thus can be plugged – which also means that the NSRT reset pin has a pin header that can be easily accessed to reset the microcontroller. There are enough redundant push buttons that failure management is unnecessary. The BOOT0 or boot mode pin has a solder pad in case the board needs to be booted in a different mode.

Besides the decision described above to use 0 ohm resistors instead of jumpers or solder pads, this was implemented as described.

Sensors and EEPROM:

The digital sensors inputs and the EEPROM communication lines have 0Ω resistor pairs in place such that they can change between I2C1 and I2C2 communication protocol, and so that there are a pair of lines available for isolated testing of components. The analogue sensors have 0Ω resistor pairs such that they can change between GPIOA and GPIOB reading the value.

This was implemented as described.

Output:

The output USB has a 3 pin header on both Tx and Rx lines such that the USB can be changed between UART1 and UART2 as well as the board can communicate with an external USB setup in case the onboard USB port or differential pair lines to UART chip are damaged. The LED has also been wired with a jumper such that an output signal can be jumped to an external board.

USB/UART connections were implemented as described. The LED connection was changed from a jumper to a 0 ohm resistor. A through-hole test point was added which will allow a wire to be manually soldered if the connection needs to be jumped to another board. A second LED was also added in case of LED failure.

This system of failure management allows for most components to be isolated for testing, redirected in case of line damage, or have signals inputted or outputted to an external board for testing.

## Q5: Power subsystem schematic


Some changes were made to resistance values as they were wrong. Test points were added throughout the circuit which will provide opportunities to test as well as solder on wires if needed. I have also added unpopulated and populated 0 ohm resistors over each modular component so that we can remove and add modular components as we want.

## Q6: Sensing subsystem schematic


PMOSFET switching circuits were added to each sensor to allow the power to be enabled or disabled individually.

Test points were added to allow testing of the circuit or allow wires to be manually soldered between various components if necessary.

DNP 0 ohm resistors bypassing the PMOSFET switches were added to allow direct powering of sensors if necessary.

Net labels were renamed for clarity.

## Q7: Microcontroller interfacing schematic


Connections to the PMOSFET switches on the sensors subsystem were added to allow the sensor power to be enabled/disabled via GPIO.

The failure management system was updated to use exclusively 0 ohm resistors instead of a mixture of these and jumpers/solder pads.

Test points were added to allow testing of the circuit or allow wires to be manually soldered between various components if necessary.

EEPROM was connected to I2C1 by default (instead of I2C2), and I2C pullup resistances were recalculated and changed.

Previously a component diagram of the actual micrcontroller board had been included for visual reference – this was removed entirely.

A second output LED was added.

Net labels were renamed for clarity.

## Q8: Updated ERCs

ERCs used were:

- Make sure the 5V and 3V3 and GND labels aren’t short circuit to each other.
- Make sure there are no floating pins.
- Make sure the power running through resistor doesn’t exceed their maximums.
- Make sure power lines do not go through traces that are too thin.

Screenshot of ERC report with no errors:


The 138 warnings are because a large number of wires in the schematic are off-grid.

## Q9: DRCs

DRCs used were:

Minimum distance between tracks

Check that all pads are connected to the correct nets

Check for thermal violations (GND pins must be connected to the GND plane with at least 2 spokes)


The 2 exclusions were:

- A GND pin on an IC that was unable to be connected to multiple GND spokes due to the physical layout of the IC pins
- A GND pin on the microcontroller header which was flagged for only connecting to 1 GND spoke on front copper even though it was connected to 2 spokes on the back copper.

The warnings were silkscreen overlaps and were not of concern.

## Q10: BOM

https://github.com/Carciax/EEE3088F-Project-CKR/blob/main/Budgeting/EEE3088F_CKR.csv

The estimated budget (exlcluding manufacturing cost) is $56.50. We are account for an ~$12.00 manufacturing cost (board and assembly), and thus are still within our budget.

## Q11: PCB design

Front copper layer:


Front copper layer with GND plane shown:


The lightly-shaded area is the GND plane.

0.6mm tracks were used for power lines, 0.4mm tracks were used elsewhere. For some ICs with small pads, 0.25mm tracks were used in small sections.

Back copper layer:


Back copper layer with GND plane shown:


The lightly-shaded area is the GND plane.

0.6mm tracks were used for power lines, 0.4mm tracks were used elsewhere. For some ICs with small pads, 0.25mm tracks were used in small sections.

Front silkscreen:


Note that the USB was intentionally allowed to stick slightly off the edge of the board to make it easy to plug in to.

Back silkscreen has not been shown as it was left empty.

All layers shown:


3D view:


Link to gerber files:

https://github.com/Carciax/EEE3088F-Project-CKR/blob/main/Gerbers

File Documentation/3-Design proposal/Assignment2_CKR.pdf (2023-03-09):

I Kain frassek declare I did not plagiarize to get any of this information in section 1.

Week 3

Q 1.1

Specification

USB input | This must be a micro-USB input. It must be able to output between 4.5 and 5.5 volts which can then be used to charge the battery. It will need to be able to withstand high temperatures such as up to 80 degrees Celsius.
battery charger | The battery charger must be able to take the 5 Volt voltage source from the micro USB and charge the battery. It will indicate when the battery is fully charged using a green LED and when the battery is still charging using a red LED. It must also be able to withstand temperatures up to 80 degrees.
Undervoltage lockout | This must be connected to the lithium-ion battery. It must ensure that if the voltage provided by the battery goes below 3.3 volts no voltage is provided to the main circuit.
Battery | This must be a lithium ion battery that fits into the BH-18650-B1BA002 (https://jlcpcb.com/partdetail/Myoung-BH_18650B1BA002/C2988620) holder. It must be a 3.3 Volt battery. It must be able to withstand temperatures around 80 degrees Celsius.
Battery terminal pins | These need to be 2 pins that can be used to provide 3.3 volts to the main circuit in case the battery is not available or for testing purposes.
Reverse polarity protection circuits | This must be connected to the battery. It must be able to detect whether the batteries polarity has been swapped or if the polarity at which the battery is being charged is in the wrong direction. If the polarity in either case has been swapped it must prevent the main circuit and battery, from being powered or charged by this voltage.
3.3 Volt regulator | This circuit must be able to take the voltage from the battery which will be 3.3 volts or higher and regulate it so that a constant 3.3 volts is supplied. This can then be used to power our circuit reliably.

Q1.2


https://github.com/Carciax/EEE3088F-Project-CKR/tree/main/Budgeting/BOM.xlsx


Q.1.3

Submodule interface

LED is used to indicate the charging of the battery. | one green LED and one red LED. Both in series with 1.2 KΩ resistors to reduce current.
STM32F051C6Tx | This is the main microprocessor board which will need to be supplied with 3.3 volts. current used to power itself is between 3 and 4.5 milliamps.
Potentiometer analog sensor | This will be supplied with 3.3 volts and will act as a voltage divider. It will draw 33 milli amps of power.
digital light sensor | this will be supplied 3.3 volts. And will draw a very low current.
Outputs via LED | There will be an LED powered by the 3.3 volts which can be used to flash at different rates and help give outputs about what has been sensed. These LED's will be put in series with large resistors to help reduce current.
Debug (SIL 1x10 Male) | This will need a 5 Volt power supply and therefore it will need to be supplied straight from the USB port.
Analogue sensor 2 thermistor | This will need 3.3 V power supply and should draw les that 1 mw of power.
USB connector | Will supply 5V to the main power circuit. An external USB cable will be connected to provide this power and for data transmission

I, Cameron Clark, declare I did not plagiarize to get any of this information in section 2.

Q2.1
Microcontroller specifications. It must be able to:
- Receive 3v3 of voltage into pins 1, 9, 24, 28.
- Connect to ground on pins 8, 23, 47.
- Not exceed an input voltage of 4V
- Not exceed an input or output current of 25mA.
- Receive an input into pin 7 (NSRT) to reset and run the loaded program.
- Receive inputs into pins 7, 34, 37 (NSRT, PA13, PA14) for programming the chip using the debugger.
- Receive a grounded input into pin 44 (BOOT0) to configure the boot mode of the chip.
- Output 3V3 to a GPIO pin
- Receive a read using an ADC a variable voltage.
- Receive data through an IC1/2 enabled pin.


Q2.2
BOM
https://github.com/Carciax/EEE3088F-Project-CKR/tree/main/Budgeting/BOM.xlsx Components for the microcontroller are indexed 6, 7, 8, 12 and 13 which are an LED, 01x03 male connector, 10k resistor, a button, and the 2 01x24 female headers.

Total cost estimated as $3.25.

Q2.3
Inputs
A push button will be used as a reset switch receive by the NRST pin 7. This will have a pulldown resistor internally configured. It will be used to start the program in the machine. It should receive a 3V3 volts from the power module and a max current of 4.5mA

Sensors
This module will receive a voltage from a thermistor in the range of 0 – 3V3. It will use an GPIOA pin or GPIOB pin 0/1 to input the voltage as these can be ADC enabled.
It will also receive data from a digital light detector sensor which will be receive by GPOIB5-11 or GPIOF6/7.

Outputs
This will output to a singular debug LED outputting 3V3 from any GPIOA/B pin. This will help the user debug the board and set it up.

I, Robert Dugmore, declare that I did not plagiarise anything in my authored section (Q3)

Digital sensor specifications:

I2C Ambient Light sensor

Specification | Detail
Input Voltage | 3V3
Operating Temperature | -10°C to 70°C
Power Consumption | ≤ 1mW
Output resolution | 16 bit
I2C Slave address bit depth | 7 bit
I2C mode | Fast mode (up to 400 kBits/s)
Light input range | 0.01 lux to 64000 lux
Minimum pull-up resistor value | 1 kΩ
Maximum pull-up resistor value | 10 kΩ
Recommended pull-up resistor value | 8.2 kΩ

The sensor module must take 3V3 power from the main 3V3 rail. It must take a clock input from the microcontroller and output serial data using I2C. It must connect to a level interrupt pin on the microcontroller. It must measure ambient light and output the light level in 16 bit resolution over the I2C connection. The I2C connection must use 7 bit slave addresses and operate in fast mode

Analogue sensor 1 specifications:

Potentiometer
Note: Justin Pead has told us that using a potentiometer as an analogue sensor is acceptable. Nevertheless we have also added a 2nd analogue sensor (see below), which we believe we can still do within the specified budget.
Specification | Detail
Input Voltage | 3V3
Operating Temperature | -10°C to 70°C
Power Consumption | ≤ 1mW
Resistance | ≥ 10 kΩ
Resistance tolerance | ≤ ± 20%
Operating life | ≥ 5000 cycles
Rotation Torque | ≤ 10 mN.m
Maximum rotation angle | ≥ 270°
Mounting type | Vertical

The sensor module must take in 3V3 power from the main 3V3 rail. It must output an analogue voltage based on the degree to which the potentiometer has been turned. It must draw less than 1 mW of power. It must be able to survive up to 5000 cycles.

Analogue sensor 2 specifications:

NTC thermister

Specification | Detail
Input Voltage | 3V3
Power consumption | ≤ 1 mW
Resistance at 25°C | ≥ 10 kΩ
Resistance tolerance | ≤ ± 1%
Measurement temperatures | ≤ -10°C to ≥ 70°C
Nominal B-constant | ≥ 4000
Voltage divider voltage at 25°C | 0.5 x 3V3

The sensor module must take 3V3 power from the main 3V3 rail. The sensor will be placed in series with a 100 kΩ resistor to form a voltage divider. The sensor must be able to read temperatures between -10°C and 70°C.

Draft schematic and BOM:

Schematic:


BOM:

https://github.com/Carciax/EEE3088F-Project-CKR/tree/main/Budgeting/BOM.xlsx See sheet 3 (sensors)

The estimated total cost for this module is $14.0170.

Digital sensor interface:

Ambient light sensor

Electrical (pinout):

Pin | Description | Connections
1 | Supply voltage | 3V3 Capacitor +
2 | No connection | NC

3 | Ground | GND Capacitor -
4 | I2C serial clock (SCL) | SCL pin on microcontroller I2C bus Pull-up resistor to 3V3
5 | Level interrupt | INT pin on microcontroller Pull-up resistor to 3V3
6 | I2C serial data (SDA) | SDA pin on microcontroller I2C bus Pull-up resistor to 3V3

The module will send digital data to the microcontroller via an I2C bus on the microcontroller. All pins will have 0Ω resistors in series with the “main” pin connections so that the sensor can be disconnected in the event that it doesn’t work properly.
All pins will have 0Ω resistors in series with the “main” pin connections so that the sensor can be disconnected in the event that it doesn’t work properly.

Electromagnetic (light):

The module will receive ambient light, which the sensor will internally convert to a digital signal (to be sent out of the module as an electrical signal over I2C)

Sensor dimensions:

Width: 2 mm
Length: 2 mm
Height: 0.7 mm

Analogue sensor 1 interface:

Potentiometer

Electrical (pinout):

Pin | Description | Connection
1 | Supply voltage | 3V3
2 | Output | GPIO pin, configured for ADC input
3 | Ground | GND

The module will send an analogue voltage to a GPIO pin configured for ADC input on the microcontroller.
All pins will have 0Ω resistors in series with the “main” pin connections so that the sensor can be disconnected in the event that it doesn’t work properly.

Tactile input:

The twist-knob of the potentiometer can be turned by hand to change the output voltage. This can be used during the configuration stage to fine tune the settings of the device. Additionally it could be used to sense “human data”, where the readings in the device

Mechanical input:

The twist knob of the potentiometer could also be connected to a small mechanical system that turns the knob. For example, the mechanical input could come from a small wind vane, or from a window where the researcher wants to measure when the window is opened and how wide it is opened.

Sensor dimensions:

Width: 9.8 mm
Length: 12 mm
Height: 15 mm
Knob diameter: 6 mm

Analogue sensor 2 interface:

NTC thermister

Electrical (pinout):

Pin | Description | Connection
1 | Connection to 100 kΩ resistor of voltage divider and ADC input | GPIO pin, configured for ADC input 100 kΩ resister pulled up to 3V3
2 | Ground | GND

The sensor module will send an analogue voltage to a GPIO pin configured for ADC input on the microcontroller.
All pins will have 0Ω resistors in series with the “main” pin connections so that the sensor can be disconnected in the event that it doesn’t work properly.

Temperature input:

The thermister reacts to changes in temperature. It is a negative temperature coefficient thermister, which means that its resistance decreases as the temperature increases. This resistance change will be read by placing the thermister in series with a static 100 kΩ resistor to form a voltage divider.
The thermister’s change in resistance with temperature is non-linear. This will be compensated for in software of the microcontroller so that accurate temperature readings can be obtained.

Sensor dimensions:

Width: 0,5 mm
Length: 1 mm

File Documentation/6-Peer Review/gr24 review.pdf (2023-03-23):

# Wk5 PCB Design - Group 24

## Q1 Github [1]

https://gitlab.com/Lloyd01/eee3088-group-24-hat-project/-/tree/main

## Q2 Power Subsystem Failure Management [5]

Fuses have been added to protect the power system and the other subsystem circuitry against any damage. The chosen power supply comes with surge and short circuit protection which also helps the safety of the board and components.

Test points have been added at important locations and will help with testing, monitoring and debugging for when we have problems or general use.

I have made sure that the parts on JLC I’ve chosen have a huge stock and have backup parts planned if any stock shortages occur.

Multiple boards are being ordered (5 to be specific) this allows us to have backups in case of any damage or malfunction occurs.

A Schottky Diode has been added to prevent voltage entering the 5V rail when operating on battery power. A P-channel MOSFET has been added for reverse polarity protection and as a switch for charging off 5V or using battery power.

## Q3 Sensing Subsystem Failure Management [2]

Within the sensing subcircuit I’ve added test points at various locations and ground. This will allow us to test the voltage at points in the circuit which will greatly increase our failure safety by testing, debugging, and monitoring the sensors and its components.

I’ve connected 0Ω resistors along the connections to the microcontroller. These help us in several ways. Such as, help reduce noise and signal distortion. If there are any errors found post manufacture it is much easier and safer to desolder the resistor to change the circuit configuration if necessary than dealing with the copper traces. As well as, providing some component safety by acting as a fuse and stopping the connection if over-currented.

A fuse has been connected to protect each circuit/sensor against any surges from the power supply.

Our digital humidity sensor can also be used as a temperature sensor if failure of the analogue temperature sensor occurs.

I’ve made sure that for each component there is a substitution plan on JLC in case of any stock shortages.

We will also be ordering 5 boards for use and prototyping so there are back-ups to any damage or malfunction.

## Q4 Microcontroller interfacing Failure Management [2]

For failure management I have added two test points on the EEPROM - one connected between the A pins (A0, A1 and A2) and VCC. While the other is connected between WP and GND. These test points will have their voltages monitored in order to detect any abnormal or unexpected voltages/ change in voltage due to component failure , trace damages and various other potential iss. This will allow failure to be quickly noticed.

The EEPROM and STM32F051C6 will be on dip sockets - in case of a failure the component can be removed, replaced with a new component easily. Rather than trying to desolder the component and solder a replacement.

No fuse was used in this module as the component is very expensive and better utilised by the other modules.

I have ensured that for each component - there is an alternative in case of stock shortage. The components I chose all have very high stock counts on JLC to reduce the chance of facing stock issues.

The use of multiple boards - 5 in this case is to reduce the risk of failure by having alternative boards and components in case of failure.

0 Ohm resistors were added to the circuit aswell as more test points. The 0 ohm resistors help us in several ways. Such as, help reduce noise and signal distortion. If there are any errors found post manufacture it is much easier and safer to desolder the resistor to change the circuit configuration if necessary than dealing with the copper traces. As well as, providing some component safety by acting as a fuse and stopping the connection if over-currented.

## Q5 Power Subsystem Schematic [2]


Changes to schematic:
- Added Schottky diode for reverse polarity protection and to prevent feedback to the charging circuit.
- Added P-channel MOSFET to switch between charging and discharging states
- when charging, circuit is powered by 5V USB.
Added detail explaining major components function to schematic.

## Q6 Sensing Subsystem Schematics [2]

## Q7 Microcontroller interfacing Schematic [2]


0 Ohm resistors were added to the circuit aswell as more test points. Some corrections were made such as the missing GND in the EEPROM and the signal lines from the EEPROM were moved as they were clashing with the signals from the digital sensor. The point on the FTDI was changed to 5V from 3.3V and the supply voltage on the EEPROM was changed to 3.3V as this would be much easier than attempting to run 5V when on "battery power"

## Q8 Updated ERCs [2]

KiCAD’s ERC was used

(Issue with deleted/hidden label – has been updated)

## Q9 DRCs [2]


## Q10 Updated BOM [4]

https://gitlab.com/Lloyd01/eee3088-group-24-hat-project/-/blob/main/Documents/All_BOM.xlsx (https://gitlab.com/Lloyd01/eee3088-group-24-hat-project/-/blob/main/Documents/All_BOM.xlsx)

## Q11 PCB [15]

Top copper routing | Bottom copper routing


Top copper fill | Bottom copper fill
PCB silkscreen | 3D Model View

The gerber files are on the git repository: https://gitlab.com/Lloyd01/eee3088-group-24-hat-project/-/tree/main/PCB/Gerbers

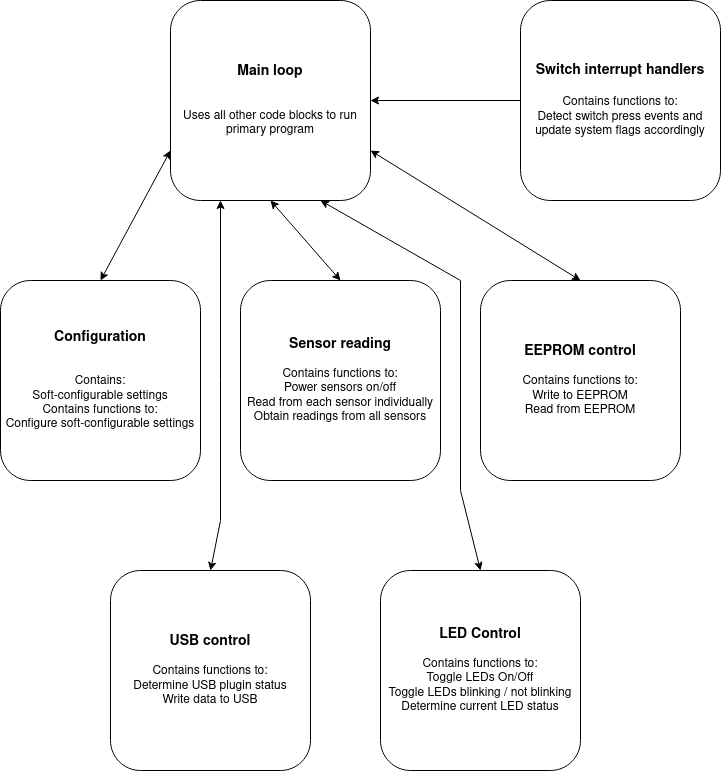
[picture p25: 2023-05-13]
Documentation/12-Code and Technical Documentation/code structure diagram.png

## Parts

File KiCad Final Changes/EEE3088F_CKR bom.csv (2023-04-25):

Reference | Value | Footprint | Datasheet | DNF | Extended Part Cost | JLC code | JLCPCB Part # | Part name | cost per unit | Qty
B1 | battery holder | JLCPartFootprints:BATTERY-SMD_18650-1S-L77.1-W20.7-1 | ~ | X | 0 | C2988620 | C2988620 | BH-18650-B1BA002 | 0 | 1
C1-C4 | 10u | JLCPartFootprints:C0603 | ~ |  | 0 | C19702 | C19702 | CL10A106KP8NNNC | 0,0066 | 4
C5 | 100n | JLCPartFootprints:C0402 | ~ |  | 0 | C1525 | C1525 | CL05B104KO5NNNC | 0.0011 | 1
C6 | 1u | JLCPartFootprints:C0402 | ~ |  | 0 | C52923 | C52923 | CL05A105KA5NQNC | 0,0039 | 1
C7, C8 | 33pF | JLCPartFootprints:C0402 | ~ |  | 0 | C1570 | C1570 | 0402CG300J500NT | 0.0010 | 2
D2 | LED_green | JLCPartFootprints:LED0603-RD | ~ |  | 0 | C72043 | C72043 | 19-217/GHC-YR1S2/3T | 0.0264 | 1
D3 | LED_red | JLCPartFootprints:LED0603-RD | ~ |  | 0 | C2286 | C2286 | KT-0603R | 0.0054 | 1
D4, D5 | LED_white | JLCPartFootprints:LED0805-R-RD | ~ |  | 0 | C34499 | C34499 | C34499 | 0.0157 | 2
J1, J2 | 01x02_male_header | Connector_PinHeader_2.54mm:PinHeader_1x02_P2.54mm_Vertical | ~ | X | 0 |  |  |  | 0 | 2
J3 | STM32F051C6_female_header | CustomFootprints:STM32F051C6_female_header |  | X | 0 |  |  |  | 0 | 1
J4 | STM32F051C6_testpoints | CustomFootprints:STM32F051C6_testpoints |  | X | 0 |  |  |  | 0 | 1
J5 | STM-link_debugger | Connector_PinHeader_2.54mm:PinHeader_1x03_P2.54mm_Vertical | ~ | X | 0 |  |  |  | 0 | 1
J6 | 01x10_male_header | Connector_PinHeader_2.54mm:PinHeader_1x10_P2.54mm_Vertical | ~ | X | 0 |  |  |  | 0 | 1
JP1-JP4 | 01x02_male_header_jumper | Connector_PinHeader_2.54mm:PinHeader_1x02_P2.54mm_Vertical | ~ | X | 0 |  |  |  | 0 | 4
JP5, JP6 | 01x03_male_header_jumper | Connector_PinHeader_2.54mm:PinHeader_1x03_P2.54mm_Vertical | ~ | X | 0 |  |  |  | 0 | 2
Q1, Q3-Q8, Q90 | AO3401A | JLCPartFootprints:SOT-23_L2.9-W1.3-P1.90-LS2.4-BR | http://www.aosmd.com/pdfs/datasheet/AO3401A.pdf |  | 0 | C15127 | C15127 | AO3401A | 0,07965 | 8
Q2 | AO3400A | JLCPartFootprints:SOT-23_L2.9-W1.3-P1.90-LS2.4-BR | https://ngspice.sourceforge.io/docs/ngspice-manual.pdf |  | 0 | C20917 | C20917 | AO3400A |  | 1
R1, R2, R5, R6, R15, R16, R18-R21, R23-R27, R29-R37, R40-R48, R53-R58, R61, R120, R400, R700 | 0 | JLCPartFootprints:R0603 | ~ |  | 0 | C21189 | C21189 | 0603WAF0000T5E | 0,0010 | 43
R3, R9, R11, R14, R17, R22, R38, R39 | 1.2k | JLCPartFootprints:R0805 | ~ |  | 0 | C17630 | C17630 | 0805W8F3300T5E | 0,0016 | 8
R28 | 100k | JLCPartFootprints:R1206 | ~ |  | 0 | C17900 | C17900 | 1206W4F1003T5E | 0,0031 | 1
R49, R59 | 10k | JLCPartFootprints:R0805 | ~ |  | 0 | C17414 | C17414 | 0805W8F1002T5E | 0,0010 | 2
R50, R51 | 3.9k | JLCPartFootprints:R0402 | ~ |  | 0 | C51721 | C51721 | 0402WGF3901TCE | 0,0006 | 2
R52 | 8.2k | JLCPartFootprints:R0402 | ~ |  | 0 | C25924 | C25924 | 0402WGF8201TCE | 0,0005 | 1
R60, R800 | 20k | JLCPartFootprints:R0603 | ~ |  | 0 | C4184 | C4184 | 0603WAF2002T5E | -- mixed values -- | 2
R100, R620 | 100k | JLCPartFootprints:R0805 | ~ |  | 0 | C149504 | C149504 | 0805W8F1003T5E |  | 2
R130 | 470k | JLCPartFootprints:R0805 | ~ |  | 0 | C17709 | C17709 | 0805W8F4703T5E |  | 1
RV1 | R_Potentiometer | JLCPartFootprints:RES-ADJ-TH_RK09K1130AJ3 | ~ |  | 3 | C388854 | C388854 | RK09K1130AJ3 | 0,5956 | 1
SW1 | Reset switch | JLCPartFootprints:SW-SMD_4P-L5.1-W5.1-P3.70-LS6.5-TL-2 | ~ |  | 0 | C318884 | C318884 | TS-1187A-B-A-B | 0,0152 | 1
SW2-SW4 | Switch | JLCPartFootprints:SW-SMD_4P-L5.1-W5.1-P3.70-LS6.5-TL-2 | ~ |  | 0 | C318884 | C318884 | TS-1187A-B-A-B | 0,0152 | 3
TH1 | Thermistor | JLCPartFootprints:R0402 | ~ |  | 3 | C77130 | C77130 | NCP15WF104F03RC | 0.0126 | 1
TP1 | 5v | CustomFootprints:Testpoint | ~ | X | 0 |  |  |  | 0 | 1
TP2 | UVLO | CustomFootprints:Testpoint | ~ |  | 0 |  |  |  | 0 | 1
TP3 | battery charger | CustomFootprints:Testpoint | ~ | X | 0 |  |  |  | 0 | 1
TP4 | 3.3v out | CustomFootprints:Testpoint | ~ | X | 0 |  |  |  | 0 | 1
TP5 | reverse polarity | CustomFootprints:Testpoint | ~ | X | 0 |  |  |  | 0 | 1
TP6 | Pot ADC | CustomFootprints:Testpoint | ~ | X | 0 |  |  |  | 0 | 1
TP7 | Sensors SDA | CustomFootprints:Testpoint | ~ | X | 0 |  |  |  | 0 | 1
TP8 | Sensors SCL | CustomFootprints:Testpoint | ~ | X | 0 |  |  |  | 0 | 1
TP9 | Therm ADC | CustomFootprints:Testpoint | ~ | X | 0 |  |  |  | 0 | 1
TP10 | Light Interrupt | CustomFootprints:Testpoint | ~ | X | 0 |  |  |  | 0 | 1
TP11 | LED 1 | CustomFootprints:Testpoint | ~ | X | 0 |  |  |  | 0 | 1
TP12 | LED 2 | CustomFootprints:Testpoint | ~ | X | 0 |  |  |  | 0 | 1
TP13 | Switch 1 | CustomFootprints:Testpoint | ~ | X | 0 |  |  |  | 0 | 1
TP14 | Switch 2 | CustomFootprints:Testpoint | ~ | X | 0 |  |  |  | 0 | 1
TP15 | Switch 3 | CustomFootprints:Testpoint | ~ | X | 0 |  |  |  | 0 | 1
TP16 | uc Tx | CustomFootprints:Testpoint | ~ | X | 0 |  |  |  | 0 | 1
TP17 | uc Rx | CustomFootprints:Testpoint | ~ | X | 0 |  |  |  | 0 | 1
TP18 | Plug Detect | CustomFootprints:Testpoint | ~ | X | 0 |  |  |  | 0 | 1
TP19 | EEPROM SDA | CustomFootprints:Testpoint | ~ | X | 0 |  |  |  | 0 | 1
TP20 | EEPROM SCL | CustomFootprints:Testpoint | ~ | X | 0 |  |  |  | 0 | 1
TP21 | USB D- | CustomFootprints:Testpoint | ~ | X | 0 |  |  |  | 0 | 1
TP22 | USB D+ | CustomFootprints:Testpoint | ~ | X | 0 |  |  |  | 0 | 1
U1 | LMS33460MG_NOPB | JLCPartFootprints:SC-70-5_L2.1-W1.3-P0.65-LS2.1-BR | https://atta.szlcsc.com/upload/public/pdf/source/20180404/C202268_2B9476A784C7F34EA71CCBA8021E516C.pdf |  | 3 | C95686 | C95686 | LMS33460MG_NOPB |  | 1
U2 | Battery Charger | JLCPartFootprints:ESOP-8_L4.9-W3.9-P1.27-LS6.0-BL-EP |  |  | 0 | C16581 | C16581 | TP4056 | 0.2148 | 1
U4 | XC6206PxxxMR | JLCPartFootprints:SOT-23-3_L2.9-W1.6-P1.90-LS2.8-BR | https://www.torexsemi.com/file/xc6206/XC6206.pdf |  | 0 | C5446 | C5446 | XC6206P332MR | 0,0964 | 1
U5 | GXHTC3 | JLCPartFootprints:DFN-6_L2.0-W2.0-P0.50-BL-EP |  |  | 3 | C2837688 | C2837688 | GXHTC3 | 0,8714 | 1
U6 | LTR-303ALS-01 | JLCPartFootprints:SOT-363_L2.0-W1.3-P0.65-LS2.1-BL | http://optoelectronics.liteon.com/upload/download/DS86-2013-0004/LTR-303ALS-01_DS_V1.pdf |  | 3 | C364577 | C364577 | LTR-303ALS-01 | 0,3762 | 1
U7 | 24LC256 | JLCPartFootprints:PDIP-8_L9.3-W6.4-P2.54-LS7.6-BL | http://ww1.microchip.com/downloads/en/devicedoc/21203m.pdf |  | 3 | C411624 | C411624 | 24LC256 | 1.6033 | 1
U8 | usb | JLCPartFootprints:MICRO-USB-SMD_MICROXNJ |  |  | 3 | C404969 | C404969 | MicroXNJ | 0.0333 | 1
U9 | HT42B534-2 | JLCPartFootprints:SOP-8_L4.9-W3.9-P1.27-LS6.0-BL |  |  | 3 | C493294 | C493294 | HT42B534-2 | 0.7554 | 1
Y1 | Crystal | JLCPartFootprints:CRYSTAL-SMD_L11.5-W4.8-LS12.7 | ~ |  | 0 | C12674 | C12674 | X49SM8MSD2SC | 0.0864 | 1

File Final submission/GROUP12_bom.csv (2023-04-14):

Designator | Footprint | Quantity | Value | LCSC Part #
B1 | BATTERY-SMD_18650-1S-L77.1-W20.7-1 | 1 | battery holder | DNP
C1, C2, C3, C4 | C0603 | 4 | 10u | C19702
C5 | C0402 | 1 | 100n | C1525
C6 | C0402 | 1 | 1u | C52923
C7, C8 | C0402 | 2 | 33pF | C1570
D2 | LED0603-RD | 1 | LED_green | C72043
D3 | LED0603-RD | 1 | LED_red | C2286
D4, D5 | LED0805-R-RD | 2 | LED_white | C34499
J1, J2 | PinHeader_1x02_P2.54mm_Vertical | 2 | 01x02_male_header | DNP
J3 | STM32F051C6_female_header | 1 | STM32F051C6_female_header | DNP
J4 | STM32F051C6_testpoints | 1 | STM32F051C6_testpoints | DNP
J5 | PinHeader_1x03_P2.54mm_Vertical | 1 | STM-link_debugger | DNP
J6 | PinHeader_1x10_P2.54mm_Vertical | 1 | 01x10_male_header | DNP
JP1, JP2, JP3, JP4 | PinHeader_1x02_P2.54mm_Vertical | 4 | 01x02_male_header_jumper | DNP
JP5, JP6 | PinHeader_1x03_P2.54mm_Vertical | 2 | 01x03_male_header_jumper | DNP
Q1, Q3, Q4, Q5, Q6, Q7, Q8, Q90 | SOT-23_L2.9-W1.3-P1.90-LS2.4-BR | 8 | AO3401A | C15127
Q2 | SOT-23_L2.9-W1.3-P1.90-LS2.4-BR | 1 | AO3400A | C20917
R1, R120, R15, R18, R20, R23, R26, R27, R31, R32, R33, R34, R35, R36, R37, R40, R400, R41, R42, R43, R44, R45, R46, R47, R48, R53, R54, R55, R56, R57, R58, R61, R700 | R0603 | 33 | 0 | C21189
R100, R620 | R0805 | 2 | 100k | C149504
R11, R14, R17, R22, R3, R38, R39, R9 | R0805 | 8 | 1.2k | C17630
R130 | R0805 | 1 | 470k | C17709
R16, R19, R2, R21, R24, R25, R29, R30 | R0603 | 8 | 0 | DNP
R28 | R1206 | 1 | 100k | C17900
R49, R59 | R0805 | 2 | 10k | C17414
R50, R51 | R0402 | 2 | 3.9k | C51721
R52 | R0402 | 1 | 8.2k | C25924
R60, R800 | R0603 | 2 | 20k | C4184
RV1 | RES-ADJ-TH_RK09K1130AJ3 | 1 | R_Potentiometer | C388854
SW1 | SW-SMD_4P-L5.1-W5.1-P3.70-LS6.5-TL-2 | 1 | Reset switch | C318884
SW2, SW3, SW4 | SW-SMD_4P-L5.1-W5.1-P3.70-LS6.5-TL-2 | 3 | Switch | C318884
TH1 | R0402 | 1 | Thermistor | C77130
TP1 | Testpoint | 1 | 5v | DNP
TP10 | Testpoint | 1 | Light Interrupt | DNP
TP11 | Testpoint | 1 | LED 1 | DNP
TP12 | Testpoint | 1 | LED 2 | DNP
TP13 | Testpoint | 1 | Switch 1 | DNP
TP14 | Testpoint | 1 | Switch 2 | DNP
TP15 | Testpoint | 1 | Switch 3 | DNP
TP16 | Testpoint | 1 | uc Tx | DNP
TP17 | Testpoint | 1 | uc Rx | DNP
TP18 | Testpoint | 1 | Plug Detect | DNP
TP19 | Testpoint | 1 | EEPROM SDA | DNP
TP2 | Testpoint | 1 | UVLO | DNP
TP20 | Testpoint | 1 | EEPROM SCL | DNP
TP21 | Testpoint | 1 | USB D- | DNP
TP22 | Testpoint | 1 | USB D+ | DNP
TP3 | Testpoint | 1 | battery charger | DNP
TP4 | Testpoint | 1 | 3.3v out | DNP
TP5 | Testpoint | 1 | reverse polarity | DNP
TP6 | Testpoint | 1 | Pot ADC | DNP
TP7 | Testpoint | 1 | Sensors SDA | DNP
TP8 | Testpoint | 1 | Sensors SCL | DNP
TP9 | Testpoint | 1 | Therm ADC | DNP
U1 | SC-70-5_L2.1-W1.3-P0.65-LS2.1-BR | 1 | LMS33460MG_NOPB | C95686
U2 | ESOP-8_L4.9-W3.9-P1.27-LS6.0-BL-EP | 1 | Battery Charger | C16581
U4 | SOT-23-3_L2.9-W1.6-P1.90-LS2.8-BR | 1 | XC6206PxxxMR | C5446
U5 | DFN-6_L2.0-W2.0-P0.50-BL-EP | 1 | GXHTC3 | C2837688
U6 | SOT-363_L2.0-W1.3-P0.65-LS2.1-BL | 1 | LTR-303ALS-01 | C364577
U7 | PDIP-8_L9.3-W6.4-P2.54-LS7.6-BL | 1 | 24LC256 | C411624
U8 | MICRO-USB-SMD_MICROXNJ | 1 | usb | C404969
U9 | SOP-8_L4.9-W3.9-P1.27-LS6.0-BL | 1 | HT42B534-2 | C493294
Y1 | CRYSTAL-SMD_L11.5-W4.8-LS12.7 | 1 | Crystal | C12674

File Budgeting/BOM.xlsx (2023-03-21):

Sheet: Power
Reference | Value | Footprint | Datasheet | DNF | Extended Part Cost | JLC code | Part name | cost per unit | Qty | cost
BT2 | Battery | n/a | ~ | x |  |  |  | 0 | 1 | 0
C1-C4 | 10uf | CL10A106KP8NNNC | ~ |  | 0 | C19702 | CL10A106KP8NNNC | 0.0066 | 4 | 0.132
D1 | LED Green | LED_0805 | ~ |  | 0 | C2296 | LED_0805 | 0.0119 | 1 | 0.0595
D2 | LED RED |  | ~ |  | 0 | C2286 | LED_0603 | 0.0054 | 1 | 0.027
D4 | zener diode |  |  |  | 3 | C36599 | MMSZ4678T18 | 0.0956 | 1 | 3.478
J3, J4 | Conn_01x02_Pin |  | ~ | X | 0 |  |  |  | 2 | 0
JP1 | Jumper_2_Bridged |  | ~ | X | 0 |  |  |  | 1 | 0
JP2 | SolderJumper_2_Bridged |  | ~ |  | 0 |  |  |  | 1 | 0
Q1 | AO3401A | Package_TO_SOT_SMD:SOT-23 | http://www.aosmd.com/pdfs/datasheet/AO3401A.pdf |  | 0 | C15127 | AO3401A | 0.0797 | 1 | 0.3985
R2-R4 | 1.2k |  | ~ |  | 0 | C19702 | 0603WAF1201T5E | 0.0066 | 3 | 0.099
R13 | 0 |  |  |  | 0 | C17477 |  |  | 1 | 0
R14, R18 | R1M |  | ~ |  | 0 | C17514 | 0805W8F1004T5E | 0.0016 | 2 | 0.016
R15 | R2M |  | ~ |  | 0 | C26112 | 0805W8F2004T5E | 0.0024 | 1 | 0.012
R16 | 100k |  | ~ |  | 0 | C17900 | 1206W4F1003T5E | 0.0032 | 1 | 0.016
R17 | 80k |  | ~ |  | 0 | C17840 | 0805W8F8202T5E | 0.0017 | 1 | 0.0085
R19 | R3M |  | ~ |  | 0 | C23156 | 0603WAF3004T5E | 0.0013 | 1 | 0.0065
U3 | Batter Charger | TP4056 |  |  | 0 | C16581 | TP4056 | 0.2064 | 1 | 1.032
U4 | XC6206PxxxMR | Package_TO_SOT_SMD:SOT-23-3 | https://www.torexsemi.com/file/xc6206/XC6206.pdf |  | 0 | C5446 | XC6206P332MR | 0.0964 | 1 | 0.482
U9 | LMV321 |  | http://www.ti.com/lit/ds/symlink/lmv324.pdf |  | 0 | C7972 | LMV321 | 0.1439 | 1 | 0.7195
 |  |  |  |  |  |  |  |  |  | $6.49

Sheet: Microcontroller
# | Reference | Qty | Value | JLC Part | Footprint | DNP | Unit Cost | Extended Part Cost | Total Cost
6 | D3 | 1 | LED | C2286 |  |  | 0.0054 |  | 0.027
8 | J1 | 1 | Debugger | - |  | DNP |  |  | 0
9 | J2 | 1 | STM_female_headers | - |  | DNP |  |  | 0
10 | JP1 | 1 | Jumper_2_Bridged | - |  | DNP |  |  | 0
11 | JP2, JP5, JP6, JP7 | 4 | SolderJumper_2_Bridged | - |  |  | 0 |  | 0
12 | JP3, JP9 | 2 | Jumper_3_Bridged12 | - |  | DNP |  |  | 0
15 | R1 | 1 | 10k | C17902 |  |  | 0.0015 |  | 0.0075
17 | R22, R23, R24, R26, R27, R30, R31 | 11 | 0 | C17477 |  |  | 0.0261 |  | 1.4355
18 | R6 | 1 | 1.2k | C19702 |  |  | 0.001 |  | 0.005
27 | SW1, SW2, SW3, SW4 | 4 | Switches | C13828 |  |  | 0.0425 | 3 | 3.85
30 | U2 | 1 | HT42B534-2 | C493294 |  |  | 0.76 | 3 | 6.8
35 | U5 | 1 | C404969 | C404969 |  |  | 0.0333 | 3 | 3.1665
34 | U7 | 1 | 24LC256 | C411624 |  |  | 0.52 | 3 | 5.6
 |  |  |  |  |  |  |  | Total Cost: | 20.89

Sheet: BOM
Reference | Value | Footprint | Datasheet | DNF | Extended Part Cost | JLC code | Part name | Sim.Enable | cost per unit | Qty | cost
C1-C4 | 10uf | footprint:C0603 | ~ |  | 0 | -- mixed values -- | CL10A106KP8NNNC |  | 0,0066 | 4 | 0.132
C5 | 100n | footprint:C0402_NEW | ~ |  | 0 | C1525 | CL05B104KO5NNNC |  | 0.0011 | 1 | 0.0055
C6 | 1u | footprint:C0402 | ~ |  | 0 | C52923 | CL05A105KA5NQNC |  | 0,0039 | 1 | 0.0195
D1 | LED Green | footprint:LED0805-R-RD | ~ |  | 0 | C2296 | 17-21SUYC/TR8 |  | 0,0119 | 1 | 0.0595
D2 | zener diode | footprint:SOD-123_L2.8-W1.8-LS3.7-RD |  |  | 3 | C36599 | MMSZ4678T18 |  | 0,0956 | 1 | 3.478
D3 | LED RED | footprint:LED0603-RD | ~ |  | 0 | C2286 | LED_0603 |  | 0,0054 | 1 | 0.027
D4, D5 | LED | footprint:LED0603-RD | ~ |  | 0 | C2286 | LED_0603 |  | 0,0054 | 2 | 0.054
J1, J2 | Conn_01x02_Pin | footprint:HDR-TH_2P-P2.54-V-M | ~ | X | 0 | C5116481 | 2.54-1*2 |  | 0 | 2 | 0
J3 |  | footprint:STM32F051C6_female_header |  |  | 0 | C2883741 | X6511FV-24-C85D32 |  | 0 | 1 | 0
J4 | Debugger | footprint:HDR-TH_3P-P2.54_CS-1165SDIG | ~ |  | 0 | C2886705 | CS-1165SDIG-1*3 |  | 0 | 1 | 0
Q1-Q7 | AO3401A | footprint:SOT-23_L2.9-W1.3-P1.90-LS2.4-BR | http://www.aosmd.com/pdfs/datasheet/AO3401A.pdf |  | 0 | C15127 | AO3401A |  | 0,0797 | 7 | 2.7895
R1, R2, R9, R13, R14, R16-R18, R20-R24, R26-R47, R65-R72 | 0 | footprint:R0603 | ~ |  | 0 | C21189 | 0603WAF0000T5E | -- mixed values -- | 0,0010 | 43 | 0.1075
R3, R11 | R1M | footprint:R0805 | ~ |  | 0 | C17514 | 0805W8F1004T5E |  | 0,0016 | 2 | 0.016
R4 | R2M | footprint:R0805 | ~ |  | 0 | C26112 | 0805W8F2004T5E |  | 0,0024 | 1 | 0.012
R5, R8, R10, R15, R19, R56, R57 | 1.2k | footprint:R0805 | ~ |  | 0 | C17630 | 0805W8F3300T5E |  | 0,0016 | 7 | 0.056
R6 | 27.5k | footprint:R0805 | ~ |  | 0 | C17593 | 0805W8F2702T5E |  | 0,0018 | 1 | 0.009
R7, R64 | 10k | footprint:R0805 | ~ |  | 0 | C17414 | 0805W8F1002T5E |  | 0,0010 | 2 | 0.01
R12 | R3M | footprint:R0603 | ~ |  | 0 | C23156 | 0603WAF3004T5E |  | 0,0013 | 1 | 0.0065
R25 | 100k | footprint:R1206 | ~ |  | 0 | C17900 | 1206W4F1003T5E |  | 0,0031 | 1 | 0.0155
R48-R50, R55 | 3.9k | footprint:R0402 | ~ |  | 0 | C51721 | 0402WGF3901TCE |  | 0,0006 | 4 | 0.012
R58, R63 | 8.2k | footprint:R0402 | ~ |  | 0 | C25924 | 0402WGF8201TCE |  | 0,0005 | 2 | 0.005
RV1 | R_Potentiometer | footprint:RES-ADJ-TH_RK09K1130AJ3 | ~ |  | 3 | C388854 | RK09K1130AJ3 |  | 0,5956 | 1 | 5.978
SW1 | Reset switch | footprint:SW-SMD_4P-L5.1-W5.1-P3.70-LS6.5-TL-2 | ~ |  | 0 | C318884 | TS-1187A-B-A-B |  | 0,0152 | 1 | 0.076
SW2-SW4 | switch | footprint:SW-SMD_4P-L5.1-W5.1-P3.70-LS6.5-TL-2 | ~ |  | 0 | C318884 | TS-1187A-B-A-B |  | 0,0152 | 3 | 0.228
TH1 | Thermistor | footprint:R0402 | ~ |  | 3 | C77130 | NCP15WF104F03RC |  | 0.013 | 1 | 3.065
TP1 | 5v | footprint:Testpoint_2.54mm | ~ |  | 0 |  |  |  | 0 | 1 | 0
TP2 | battery charger | footprint:Testpoint_2.54mm | ~ |  | 0 |  |  |  | 0 | 1 | 0
TP3 | UVLO | footprint:Testpoint_2.54mm | ~ |  | 0 |  |  |  | 0 | 1 | 0
TP4 | +battery out | footprint:Testpoint_2.54mm | ~ |  | 0 |  |  |  | 0 | 1 | 0
TP5 | reverse polarity | footprint:Testpoint_2.54mm | ~ |  | 0 |  |  |  | 0 | 1 | 0
TP6 | 3.3v out | footprint:Testpoint_2.54mm | ~ |  | 0 |  |  |  | 0 | 1 | 0
TP7 | Pot ADC | footprint:Testpoint_2.54mm | ~ |  | 0 |  |  |  | 0 | 1 | 0
TP8 | Therm ADC | footprint:Testpoint_2.54mm | ~ |  | 0 |  |  |  | 0 | 1 | 0
TP9 | Light SDA | footprint:Testpoint_2.54mm | ~ |  | 0 |  |  |  | 0 | 1 | 0
TP10 | Light SCL | footprint:Testpoint_2.54mm | ~ |  | 0 |  |  |  | 0 | 1 | 0
TP11 | Light Interrupt | footprint:Testpoint_2.54mm | ~ |  | 0 |  |  |  | 0 | 1 | 0
TP14 | NSRT | footprint:Testpoint_2.54mm | ~ |  | 0 |  |  |  | 0 | 1 | 0
TP15 | Switch1 | footprint:Testpoint_2.54mm | ~ |  | 0 |  |  |  | 0 | 1 | 0
TP16 | Switch2 | footprint:Testpoint_2.54mm | ~ |  | 0 |  |  |  | 0 | 1 | 0
TP17 | Switch3 | footprint:Testpoint_2.54mm | ~ |  | 0 |  |  |  | 0 | 1 | 0
TP18 | STM32 3V3 | footprint:Testpoint_2.54mm | ~ |  | 0 |  |  |  | 0 | 1 | 0
TP19 | STM32 LED1 | footprint:Testpoint_2.54mm | ~ |  | 0 |  |  |  | 0 | 1 | 0
TP20 | STM32 LED2 | footprint:Testpoint_2.54mm | ~ |  | 0 |  |  |  | 0 | 1 | 0
TP21 | STM32 GND | footprint:Testpoint_2.54mm | ~ |  | 0 |  |  |  | 0 | 1 | 0
TP22 | STM32 BOOT0 | footprint:Testpoint_2.54mm | ~ |  | 0 |  |  |  | 0 | 1 | 0
TP23 | STM32 Tx | footprint:Testpoint_2.54mm | ~ |  | 0 |  |  |  | 0 | 1 | 0
TP24 | STM32 Rx | footprint:Testpoint_2.54mm | ~ |  | 0 |  |  |  | 0 | 1 | 0
TP25 | EEPROM SDA | footprint:Testpoint_2.54mm | ~ |  | 0 |  |  |  | 0 | 1 | 0
TP26 | EEPROM SCL | footprint:Testpoint_2.54mm | ~ |  | 0 |  |  |  | 0 | 1 | 0
TP27 | USB D- | footprint:Testpoint_2.54mm | ~ |  | 0 |  |  |  | 0 | 1 | 0
TP28 | USB D+ | footprint:Testpoint_2.54mm | ~ |  | 0 |  |  |  | 0 | 1 | 0
U1 | Battery Charger | footprint:ESOP-8_L4.9-W3.9-P1.27-LS6.0-BL-EP |  |  | 0 | C16581 | TP4056 |  | 0,2064 | 1 | 1.032
U2 | LMV321 | footprint:SOT-23-5_L3.0-W1.7-P0.95-LS2.8-BR | http://www.ti.com/lit/ds/symlink/lmv324.pdf |  | 0 | C7972 | LMV321 |  | 0,1439 | 1 | 0.7195
U3 | XC6206PxxxMR | footprint:SOT-23-3_L2.9-W1.6-P1.90-LS2.8-BR | https://www.torexsemi.com/file/xc6206/XC6206.pdf |  | 0 | C5446 | XC6206P332MR |  | 0,0964 | 1 | 0.482
U4 | GXHTC3 | footprint:DFN-6_L2.0-W2.0-P0.50-BL-EP |  |  | 3 | C2837688 | GXHTC3 |  | 0,8714 | 1 | 7.357
U5 | LTR-303ALS-01 | footprint:SOT-363_L2.0-W1.3-P0.65-LS2.1-BL | http://optoelectronics.liteon.com/upload/download/DS86-2013-0004/LTR-303ALS-01_DS_V1.pdf |  | 3 | C364577 | LTR-303ALS-01 |  | 0,3762 | 1 | 4.881
u6 | battery holder | footprint:BATTERY-SMD_18650-1S-L77.1-W20.7-1 | ~ | x | 0 | C2988620 | BH-18650-B1BA002 |  | 0 | 1 | 0
U7 | 24LC256 | footprint:PDIP-8_L9.3-W6.4-P2.54-LS7.6-BL | http://ww1.microchip.com/downloads/en/devicedoc/21203m.pdf |  | 3 | C411624 | 24LC256 |  | 1.6033 | 1 | 11.0165
U8 | usb | footprint:MICRO-USB-SMD_MICROXNJ |  |  | 3 | C404969 | MicroXNJ |  | 0.0333 | 1 | 3.1665
U9 | HT42B534-2 | footprint:SOIC-8_L4.9-W3.9-P1.27-LS6.0-BL |  |  | 3 | C493294 | HT42B534-2 |  | 0.7554 | 1 | 6.777
 |  |  |  |  |  |  |  |  |  |  | 51.593

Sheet: Sensors
# | Reference | Qty | Value | JLC Part Number | Footprint | DNP | Unit Cost | Extended Part Cost | Total Cost
6 | C5 | 1 | 1u | C52923 |  |  | 0.0038 |  | 0.019
8 | C6 | 1 | 100n | C1525 |  |  | 0.0011 |  | 0.0055
9 | 10 | 1 | 100k | C25086 |  |  | 0.0007 |  | 0.0035
10 | RV1 | 1 | Potentiometer | C388854 |  |  | 0.5956 | 3 | 5.978
11 | TH1 | 1 | 100k thermostat | C77130 |  |  | 0.0131 | 3 | 3.0655
12 | U6 | 1 | Ambient light | C364577 |  |  | 0.03887 | 3 | 3.19435
15 | U8 | 1 | Temperature/Humidity sensor | C2837688 |  |  | 0.8714 | 3 | 7.357
17 | R21, R22 | 1 | 0 | C17477 |  |  | 0.0261 |  | 0.1305
 |  |  |  |  |  |  |  | Total Cost: | 19.75

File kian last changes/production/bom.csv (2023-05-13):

Designator | Footprint | Quantity | Value | LCSC Part #
B1 | BATTERY-SMD_18650-1S-L77.1-W20.7-1 | 1 | battery holder | DNP
C1, C2, C3, C4 | C0603 | 4 | 10u
C5 | C0402 | 1 | 100n
C6 | C0402 | 1 | 1u
C7, C8 | C0402 | 2 | 33pF
D2 | LED0603-RD | 1 | LED_green
D3 | LED0603-RD | 1 | LED_red
D4, D5 | LED0805-R-RD | 2 | LED_white
J1, J2 | PinHeader_1x02_P2.54mm_Vertical | 2 | 01x02_male_header | DNP
J3 | STM32F051C6_female_header | 1 | STM32F051C6_female_header | DNP
J4 | STM32F051C6_testpoints | 1 | STM32F051C6_testpoints | DNP
J5 | PinHeader_1x03_P2.54mm_Vertical | 1 | STM-link_debugger | DNP
J6 | PinHeader_1x10_P2.54mm_Vertical | 1 | 01x10_male_header | DNP
JP1, JP2, JP3, JP4 | PinHeader_1x02_P2.54mm_Vertical | 4 | 01x02_male_header_jumper | DNP
JP5, JP6 | PinHeader_1x03_P2.54mm_Vertical | 2 | 01x03_male_header_jumper | DNP
Q1, Q3, Q4, Q5, Q6, Q7, Q8, Q90 | SOT-23_L2.9-W1.3-P1.90-LS2.4-BR | 8 | AO3401A
Q2 | SOT-23_L2.9-W1.3-P1.90-LS2.4-BR | 1 | AO3400A
R1, R120, R15, R18, R20, R23, R26, R27, R31, R32, R33, R34, R35, R36, R37, R40, R400, R41, R42, R43, R44, R45, R46, R47, R48, R53, R54, R55, R56, R57, R58, R61, R700 | R0603 | 33 | 0
R100, R620 | R0805 | 2 | 100k
R11, R14, R17, R22, R3, R38, R39, R9 | R0805 | 8 | 1.2k
R130 | R0805 | 1 | 470k
R16, R19, R2, R21, R24, R25, R29, R30 | R0603 | 8 | 0 | DNP
R28 | R1206 | 1 | 100k
R49, R59 | R0805 | 2 | 10k
R50, R51 | R0402 | 2 | 3.9k
R52 | R0402 | 1 | 8.2k
R60, R800 | R0603 | 2 | 20k
RV1 | RES-ADJ-TH_RK09K1130AJ3 | 1 | R_Potentiometer
SW1 | SW-SMD_4P-L5.1-W5.1-P3.70-LS6.5-TL-2 | 1 | Reset switch
SW2, SW3, SW4 | SW-SMD_4P-L5.1-W5.1-P3.70-LS6.5-TL-2 | 3 | Switch
TH1 | R0402 | 1 | Thermistor
TP1 | Testpoint | 1 | 5v
TP10 | Testpoint | 1 | Light Interrupt
TP11 | Testpoint | 1 | LED 1
TP12 | Testpoint | 1 | LED 2
TP13 | Testpoint | 1 | Switch 1
TP14 | Testpoint | 1 | Switch 2
TP15 | Testpoint | 1 | Switch 3
TP16 | Testpoint | 1 | uc Tx
TP17 | Testpoint | 1 | uc Rx
TP18 | Testpoint | 1 | Plug Detect
TP19 | Testpoint | 1 | EEPROM SDA
TP2 | Testpoint | 1 | UVLO
TP20 | Testpoint | 1 | EEPROM SCL
TP21 | Testpoint | 1 | USB D-
TP22 | Testpoint | 1 | USB D+
TP3 | Testpoint | 1 | battery charger
TP4 | Testpoint | 1 | 3.3v out
TP5 | Testpoint | 1 | reverse polarity
TP6 | Testpoint | 1 | Pot ADC
TP7 | Testpoint | 1 | Sensors SDA
TP8 | Testpoint | 1 | Sensors SCL
TP9 | Testpoint | 1 | Therm ADC
U1 | SC-70-5_L2.1-W1.3-P0.65-LS2.1-BR | 1 | LMS33460MG_NOPB
U2 | ESOP-8_L4.9-W3.9-P1.27-LS6.0-BL-EP | 1 | Battery Charger
U4 | SOT-23-3_L2.9-W1.6-P1.90-LS2.8-BR | 1 | XC6206PxxxMR
U5 | DFN-6_L2.0-W2.0-P0.50-BL-EP | 1 | GXHTC3
U6 | SOT-363_L2.0-W1.3-P0.65-LS2.1-BL | 1 | LTR-303ALS-01
U7 | PDIP-8_L9.3-W6.4-P2.54-LS7.6-BL | 1 | 24LC256
U8 | MICRO-USB-SMD_MICROXNJ | 1 | usb
U9 | SOP-8_L4.9-W3.9-P1.27-LS6.0-BL | 1 | HT42B534-2
Y1 | CRYSTAL-SMD_L11.5-W4.8-LS12.7 | 1 | Crystal

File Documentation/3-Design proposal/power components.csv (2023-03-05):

Reference | Value | Footprint | Datasheet | Qty
BT1 | Battery |  | ~ | 1
C1-C4 | 10uf |  | ~ | 4
D1 | LED Green |  | ~ | 1
D2 | LED RED |  | ~ | 1
R2, R3 | 1k |  | ~ | 2
R4 | 1.2k |  | ~ | 1
R5 | R |  | ~ | 1
U2-U5 |  |  |  | 4

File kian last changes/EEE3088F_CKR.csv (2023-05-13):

Reference | Value | JLC code | JLCPCB Part # | Qty
B1 | battery holder | C2988620 | C2988620 | 1
C1-C4 | 10u | C19702 | C19702 | 4
C5 | 100n | C1525 | C1525 | 1
C6 | 1u | C52923 | C52923 | 1
C7, C8 | 33pF | C1570 | C1570 | 2
D2 | LED_green | C72043 | C72043 | 1
D3 | LED_red | C2286 | C2286 | 1
D4, D5 | LED_white | C34499 | C34499 | 2
J1, J2 | 01x02_male_header |  |  | 2
J3 | STM32F051C6_female_header |  |  | 1
J4 | STM32F051C6_testpoints |  |  | 1
J5 | STM-link_debugger |  |  | 1
J6 | 01x10_male_header |  |  | 1
JP1-JP4 | 01x02_male_header_jumper |  |  | 4
JP5, JP6 | 01x03_male_header_jumper |  |  | 2
Q1, Q3-Q8, Q90 | AO3401A | C15127 | C15127 | 8
Q2 | AO3400A | C20917 | C20917 | 1
R1, R2, R5, R6, R15, R16, R18-R21, R23-R27, R29-R37, R40-R48, R53-R58, R61, R120, R400, R700 | 0 | C21189 | C21189 | 43
R3, R9, R11, R14, R17, R22, R38, R39 | 1.2k | C17630 | C17630 | 8
R28, R100, R620 | 100k | -- mixed values -- | -- mixed values -- | 3
R49, R59 | 10k | C17414 | C17414 | 2
R50, R51 | 3.9k | C51721 | C51721 | 2
R52 | 8.2k | C25924 | C25924 | 1
R60, R800 | 20k | C4184 | C4184 | 2
R130 | 470k | C17709 | C17709 | 1
RV1 | R_Potentiometer | C388854 | C388854 | 1
SW1 | Reset switch | C318884 | C318884 | 1
SW2-SW4 | Switch | C318884 | C318884 | 3
TH1 | Thermistor | C77130 | C77130 | 1
TP1 | 5v |  |  | 1
TP2 | UVLO |  |  | 1
TP3 | battery charger |  |  | 1
TP4 | 3.3v out |  |  | 1
TP5 | reverse polarity |  |  | 1
TP6 | Pot ADC |  |  | 1
TP7 | Sensors SDA |  |  | 1
TP8 | Sensors SCL |  |  | 1
TP9 | Therm ADC |  |  | 1
TP10 | Light Interrupt |  |  | 1
TP11 | LED 1 |  |  | 1
TP12 | LED 2 |  |  | 1
TP13 | Switch 1 |  |  | 1
TP14 | Switch 2 |  |  | 1
TP15 | Switch 3 |  |  | 1
TP16 | uc Tx |  |  | 1
TP17 | uc Rx |  |  | 1
TP18 | Plug Detect |  |  | 1
TP19 | EEPROM SDA |  |  | 1
TP20 | EEPROM SCL |  |  | 1
TP21 | USB D- |  |  | 1
TP22 | USB D+ |  |  | 1
U1 | LMS33460MG_NOPB | C95686 | C95686 | 1
U2 | Battery Charger | C16581 | C16581 | 1
U4 | XC6206PxxxMR | C5446 | C5446 | 1
U5 | GXHTC3 | C2837688 | C2837688 | 1
U6 | LTR-303ALS-01 | C364577 | C364577 | 1
U7 | 24LC256 | C411624 | C411624 | 1
U8 | usb | C404969 | C404969 | 1
U9 | HT42B534-2 | C493294 | C493294 | 1
Y1 | Crystal | C12674 | C12674 | 1

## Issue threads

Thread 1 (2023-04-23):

Potentiometer draws a lot of power

rothdu, 2023-04-23:
The potentiometer typically draws 330 uA of power; this power is wasted when the sensor is not actively reading data. It is recommended to switch the sensor off when not using power using the power-enable PMOSFER

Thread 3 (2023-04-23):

UVLO draws a lot of power

rothdu, 2023-04-23:
The voltage divider input to the UVLO sensor chip draws a lot of power that will continue to be drawn even after the UVLO has cut the main circuit off from the battery. This could drain the battery even after the UVLO has activated.

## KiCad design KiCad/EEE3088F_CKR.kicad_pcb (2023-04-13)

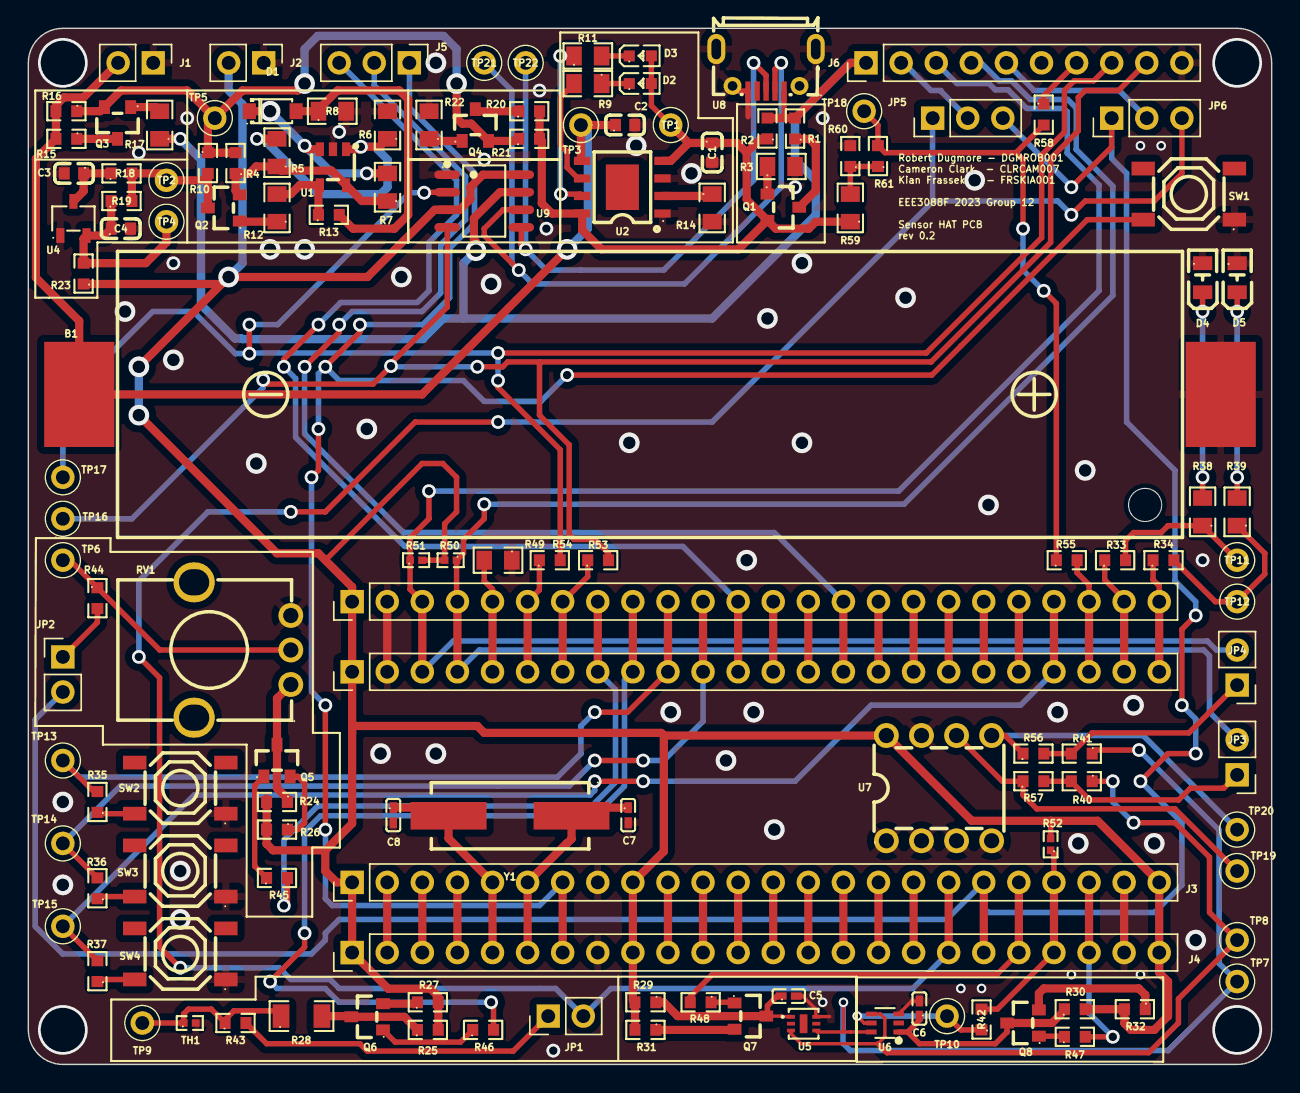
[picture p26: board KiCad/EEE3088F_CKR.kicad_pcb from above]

Board: 2 copper layers, 90.0 x 75.0 mm, 132 parts (0 on the bottom side), 107 nets.

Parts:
B1: battery holder; BATTERY-SMD_18650-1S-L77.1-W20.7-1
C1, C2, C3, C4: 10u; C0603
C5: 100n; C0402
C6: 1u; C0402
C7, C8: 33pF; C0402
D1: zener diode; SOD-123_L2.8-W1.8-LS3.7-RD
D2: LED_green; LED0603-RD
D3: LED_red; LED0603-RD
D4, D5: LED_white; LED0805-R-RD
J1, J2: 01x02_male_header; PinHeader_1x02_P2.54mm_Vertical
J3: STM32F051C6_female_header
J4: STM32F051C6_testpoints
J5: STM-link_debugger; PinHeader_1x03_P2.54mm_Vertical
J6: 01x10_male_header; PinHeader_1x10_P2.54mm_Vertical
JP1, JP2, JP3, JP4: 01x02_male_header_jumper; PinHeader_1x02_P2.54mm_Vertical
JP5, JP6: 01x03_male_header_jumper; PinHeader_1x03_P2.54mm_Vertical
Q1, Q2, Q3, Q4, Q5, Q6, Q7, Q8: AO3401A; SOT-23_L2.9-W1.3-P1.90-LS2.4-BR
R1, R2, R4, R10, R15, R16, R18, R19, R20, R21, R23, R24, R25, R26, R27, R29, R30, R31, R32, R33, R34, R35, R36, R37, R40, R41, R42, R43, R44, R45, R46, R47, R48, R53, R54, R55, R56, R57, R58, R61: 0; R0603
R3, R9, R11, R14, R17, R22, R38, R39: 1.2k; R0805
R5, R12: 1M; R0805
R6: 2M; R0805
R7: 27.5k; R0805
R8, R49, R59: 10k; R0805
R13: 3M; R0603
R28: 100k; R1206
R50, R51: 3.9k; R0402
R52: 8.2k; R0402
R60: 20k; R0603
RV1: R_Potentiometer; RES-ADJ-TH_RK09K1130AJ3
SW1: Reset switch; SW-SMD_4P-L5.1-W5.1-P3.70-LS6.5-TL-2
SW2, SW3, SW4: Switch; SW-SMD_4P-L5.1-W5.1-P3.70-LS6.5-TL-2
TH1: Thermistor; R0402
TP1: 5v; Testpoint
TP2: UVLO; Testpoint
TP3: battery charger; Testpoint
TP4: 3.3v out; Testpoint
TP5: reverse polarity; Testpoint
TP6: Pot ADC; Testpoint
TP7: Sensors SDA; Testpoint
TP8: Sensors SCL; Testpoint
TP9: Therm ADC; Testpoint
TP10: Light Interrupt; Testpoint
TP11: LED 1; Testpoint
TP12: LED 2; Testpoint
TP13: Switch 1; Testpoint
TP14: Switch 2; Testpoint
TP15: Switch 3; Testpoint
TP16: uc Tx; Testpoint
TP17: uc Rx; Testpoint
TP18: Plug Detect; Testpoint
TP19: EEPROM SDA; Testpoint
TP20: EEPROM SCL; Testpoint
TP21: USB D-; Testpoint
TP22: USB D+; Testpoint
U1: LMV321IDBVR; SOT-23-5_L3.0-W1.7-P0.95-LS2.8-BR
U2: Battery Charger; ESOP-8_L4.9-W3.9-P1.27-LS6.0-BL-EP
U4: XC6206PxxxMR; SOT-23-3_L2.9-W1.6-P1.90-LS2.8-BR
U5: GXHTC3; DFN-6_L2.0-W2.0-P0.50-BL-EP
U6: LTR-303ALS-01; SOT-363_L2.0-W1.3-P0.65-LS2.1-BL
U7: 24LC256; PDIP-8_L9.3-W6.4-P2.54-LS7.6-BL
U8: usb; MICRO-USB-SMD_MICROXNJ
U9: HT42B534-2; SOP-8_L4.9-W3.9-P1.27-LS6.0-BL
Y1: Crystal; CRYSTAL-SMD_L11.5-W4.8-LS12.7

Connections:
+3V3: J2.2, J3.1 (_VBAT), J3.9 (_VDDA), J3.24 (_VDD), J3.48 (VDD_), J4.1 (_VBAT), J4.9 (_VDDA), J4.24 (_VDD), J4.48 (VDD_), R23.1, R24.2, R25.2, R26.2, R27.2, R29.2, R30.2, R31.2, R32.2, R50.2, R51.2, R52.2, U7.8 (VCC), U9.3 (VDDIO), U9.8 (V330)
+5V: J6.1, R1.2, R2.2, R17.1, U8.1 (VBUS), U9.7 (VDD)
/Microcontroller/BOOT0: J3.44 (BOOT0_), J4.44 (BOOT0_), R49.2
/Microcontroller/INT: J3.21 (_PB10), J4.21 (_PB10), R42.2, R52.1
/Microcontroller/LED1: J3.26 (PB13_), J4.26 (PB13_), R33.1
/Microcontroller/LED2: J3.25 (PB12_), J4.25 (PB12_), R34.1
/Microcontroller/Lght_P: J3.22 (_PB11), J4.22 (_PB11), R47.2
/Microcontroller/Light_powerenable: Q8.1 (G), R47.1
/Microcontroller/NSRT: J3.7 (_NSRT), J4.7 (_NSRT), J5.1, SW1.2
/Microcontroller/OSC_IN: C8.1, J3.5 (_PF0), J4.5 (_PF0), Y1.2
/Microcontroller/OSC_OUT: C7.1, J3.6 (_PF1), J4.6 (_PF1), Y1.1
/Microcontroller/POT: JP2.1 (A), R44.2
/Microcontroller/POT_P: J3.41 (PB5_), J4.41 (PB5_), R45.2
/Microcontroller/POT_uc: J3.19 (_PB1), J4.19 (_PB1), JP2.2 (B), JP5.3 (B), JP6.1 (A)
/Microcontroller/Plg_Dtct: J3.27 (PB14_), J4.27 (PB14_), R55.2
/Microcontroller/Plug_Detect: R55.1, R58.2, R61.2, TP18.1
/Microcontroller/Potentiometer_powerenable: Q5.1 (G), R45.1
/Microcontroller/Potentiometer_signal: R44.1, RV1.2, TP6.1
/Microcontroller/Rx: J6.8, R54.2, TP17.1, U9.2 (Tx)
/Microcontroller/Rx_uc: J3.43 (PB7_), J4.43 (PB7_), R54.1
/Microcontroller/SCL: JP3.1 (A), R40.2, R57.2
/Microcontroller/SCL_uc: J3.45 (PB8_), J4.45 (PB8_), J6.4, JP3.2 (B), R50.1
/Microcontroller/SDA: JP4.1 (A), R41.2, R56.2
/Microcontroller/SDA_uc: J3.46 (PB9_), J4.46 (PB9_), J6.3, JP4.2 (B), R51.1
/Microcontroller/SW1: J3.39 (PB3_), J4.39 (PB3_), R35.2, TP13.1
/Microcontroller/SW2: J3.38 (PA15_), J4.38 (PA15_), R36.2, TP14.1
/Microcontroller/SW3: J3.28 (PB15_), J4.28 (PB15_), R37.2, TP15.1
/Microcontroller/SWCLK: J3.37 (PA14_), J4.37 (PA14_), J5.3
/Microcontroller/SWDIO: J3.34 (PA13_), J4.34 (PA13_), J5.2
/Microcontroller/THM: JP1.1 (A), R43.2
/Microcontroller/THM_P: J3.40 (PB4_), J4.40 (PB4_), R46.2
/Microcontroller/THM_uc: J3.18 (_PB0), J4.18 (_PB0), JP1.2 (B), JP5.1 (A), JP6.3 (B)
/Microcontroller/TeHu_P: J3.20 (_PB2), J4.20 (_PB2), R48.2
/Microcontroller/TemperatureHumidity_powerenable: Q7.1 (G), R48.1
/Microcontroller/Thermistor_powerenable: Q6.1 (G), R46.1
/Microcontroller/Thermistor_signal: R28.1, R43.1, TH1.1, TP9.1
/Microcontroller/Tx: J6.9, R53.2, TP16.1, U9.4 (Rx)
/Microcontroller/Tx_uc: J3.42 (PB6_), J4.42 (PB6_), R53.1
/Microcontroller/uc2: J3.2 (_PC13), J4.2 (_PC13)
/Microcontroller/uc3: J3.3 (_PC14), J4.3 (_PC14)
/Microcontroller/uc4: J3.4 (_PC15), J4.4 (_PC15)
/Microcontroller/uc10: J3.10 (_PA0), J4.10 (_PA0)
/Microcontroller/uc11: J3.11 (_PA1), J4.11 (_PA1)
/Microcontroller/uc12: J3.12 (_PA2), J4.12 (_PA2)
/Microcontroller/uc13: J3.13 (_PA3), J4.13 (_PA3)
/Microcontroller/uc14: J3.14 (_PA4), J4.14 (_PA4)
/Microcontroller/uc15: J3.15 (_PA5), J4.15 (_PA5)
/Microcontroller/uc16: J3.16 (_PA6), J4.16 (_PA6)
/Microcontroller/uc17: J3.17 (_PA7), J4.17 (_PA7)
/Microcontroller/uc29: J3.29 (PA8_), J4.29 (PA8_)
/Microcontroller/uc30: J3.30 (PA9_), J4.30 (PA9_)
/Microcontroller/uc31: J3.31 (PA10_), J4.31 (PA10_)
/Microcontroller/uc32: J3.32 (PA11_), J4.32 (PA11_)
/Microcontroller/uc33: J3.33 (PA12_), J4.33 (PA12_)
/Microcontroller/uc35: J3.35 (PA6_), J4.35 (PA6_)
/Microcontroller/uc36: J3.36 (PF7_), J4.36 (PF7_)
/Power/3.3V UVLO/polarity protector: Q2.3 (D), R10.2, R18.2, R19.2, TP2.1
/Power/Plug_Detect_5V: C1.1, D2.2 (A), D3.2 (A), Q1.2 (S), R2.1, R20.2, R21.2, R59.1, TP1.1, U2.4 (Vcc), U2.8 (CE)
/Power/polarity protected battery voltage: Q3.2 (S), Q4.2 (S), R4.2, R10.1, R16.1, R21.1, TP5.1
/Sensors/Light_SCL: R40.1, TP8.1, U5.3 (SCL), U6.4 (SCL)
/Sensors/Light_SDA: R41.1, TP7.1, U5.4 (SDA), U6.6 (SDA)
/Sensors/Light_interrupt: R42.1, TP10.1, U6.5 (INT)
/USB/Main_Analogue_Data_Read: J6.2, JP5.2 (C)
/USB/Secondary_Analogue_Data_Read: J6.5, JP6.2 (C)
GND: B1.2 (-), C1.2, C2.2, C3.2, C4.2, C5.2, C6.2, C7.2, C8.2, D4.1 (K), D5.1 (K), J1.1, J2.1, J3.8 (_VSSA), J3.23 (_VSS), J3.47 (VSS_), J4.8 (_VSSA), J4.23 (_VSS), J4.47 (VSS_), J6.10, R3.2, R6.2, R8.2, R14.2, R22.2, R49.1, R60.2, RV1.3, SW1.1, SW2.1, SW3.1, SW4.1, TH1.2, U1.2 (V-), U2.1 (TEMP), U2.3 (GND), U4.1 (GND), U5.6 (GND), U6.3 (GND), U7.1 (A0), U7.2 (A1), U7.3 (A2), U7.4 (GND), U7.7 (WP), U8.5 (GND), U8.6 (SH1), U8.7 (SH2), U8.8 (SH3), U8.9 (SH4), U9.1 (GND)
unnamed: Q2.2 (S), R4.1, R5.1, R7.1, U1.5 (V+)
unnamed: C3.1, R18.1, U4.3 (VI)
unnamed: C5.1, Q7.3 (D), U5.1 (VDD)
unnamed: C6.1, Q8.3 (D), U6.1 (VDD)
unnamed: C2.1, R15.2, U2.5 (BAT)
unnamed: D1.2, R8.1, R13.2
unnamed: D2.1 (K), R9.1
unnamed: D3.1 (K), R11.2
unnamed: D4.2 (A), R38.2
unnamed: D5.2 (A), R39.2
unnamed: B1.1 (+), J1.2, R16.2, TP3.1
unnamed: J6.7, R58.1
unnamed: Q1.3 (D), R1.1
unnamed: Q1.1 (G), R3.1
unnamed: Q2.1 (G), R12.1
unnamed: Q3.3 (D), R15.1
unnamed: Q3.1 (G), R17.2
unnamed: Q4.3 (D), R20.1
unnamed: Q4.1 (G), R22.1
unnamed: Q5.3 (D), R24.1, RV1.1
unnamed: Q5.2 (S), R26.1
unnamed: Q6.3 (D), R25.1, R28.2
unnamed: Q6.2 (S), R27.1
unnamed: Q7.2 (S), R31.1
unnamed: Q8.2 (S), R32.1
unnamed: R12.2, R13.1, U1.4
unnamed: R33.2, R38.1, TP11.1
unnamed: R34.2, R39.1, TP12.1
unnamed: R35.1, SW2.2
unnamed: R36.1, SW3.2
unnamed: R37.1, SW4.2
unnamed: R59.2, R60.1, R61.1
unnamed: R5.2, R6.1, U1.1 (+)
unnamed: D1.1, R7.2, U1.3 (-)
unnamed: R11.1, U2.7 (CHRG)
unnamed: R14.1, U2.2 (PROG)
unnamed: R9.2, U2.6 (STDBY#)
unnamed: C4.1, R19.1, R23.2, TP4.1, U4.2 (VO)
unnamed: R57.1, TP19.1, U7.6 (SCL)
unnamed: R56.1, TP20.1, U7.5 (SDA)
unnamed: TP22.1, U8.3 (D+), U9.5 (D+)
unnamed: TP21.1, U8.2 (D-), U9.6 (D-)

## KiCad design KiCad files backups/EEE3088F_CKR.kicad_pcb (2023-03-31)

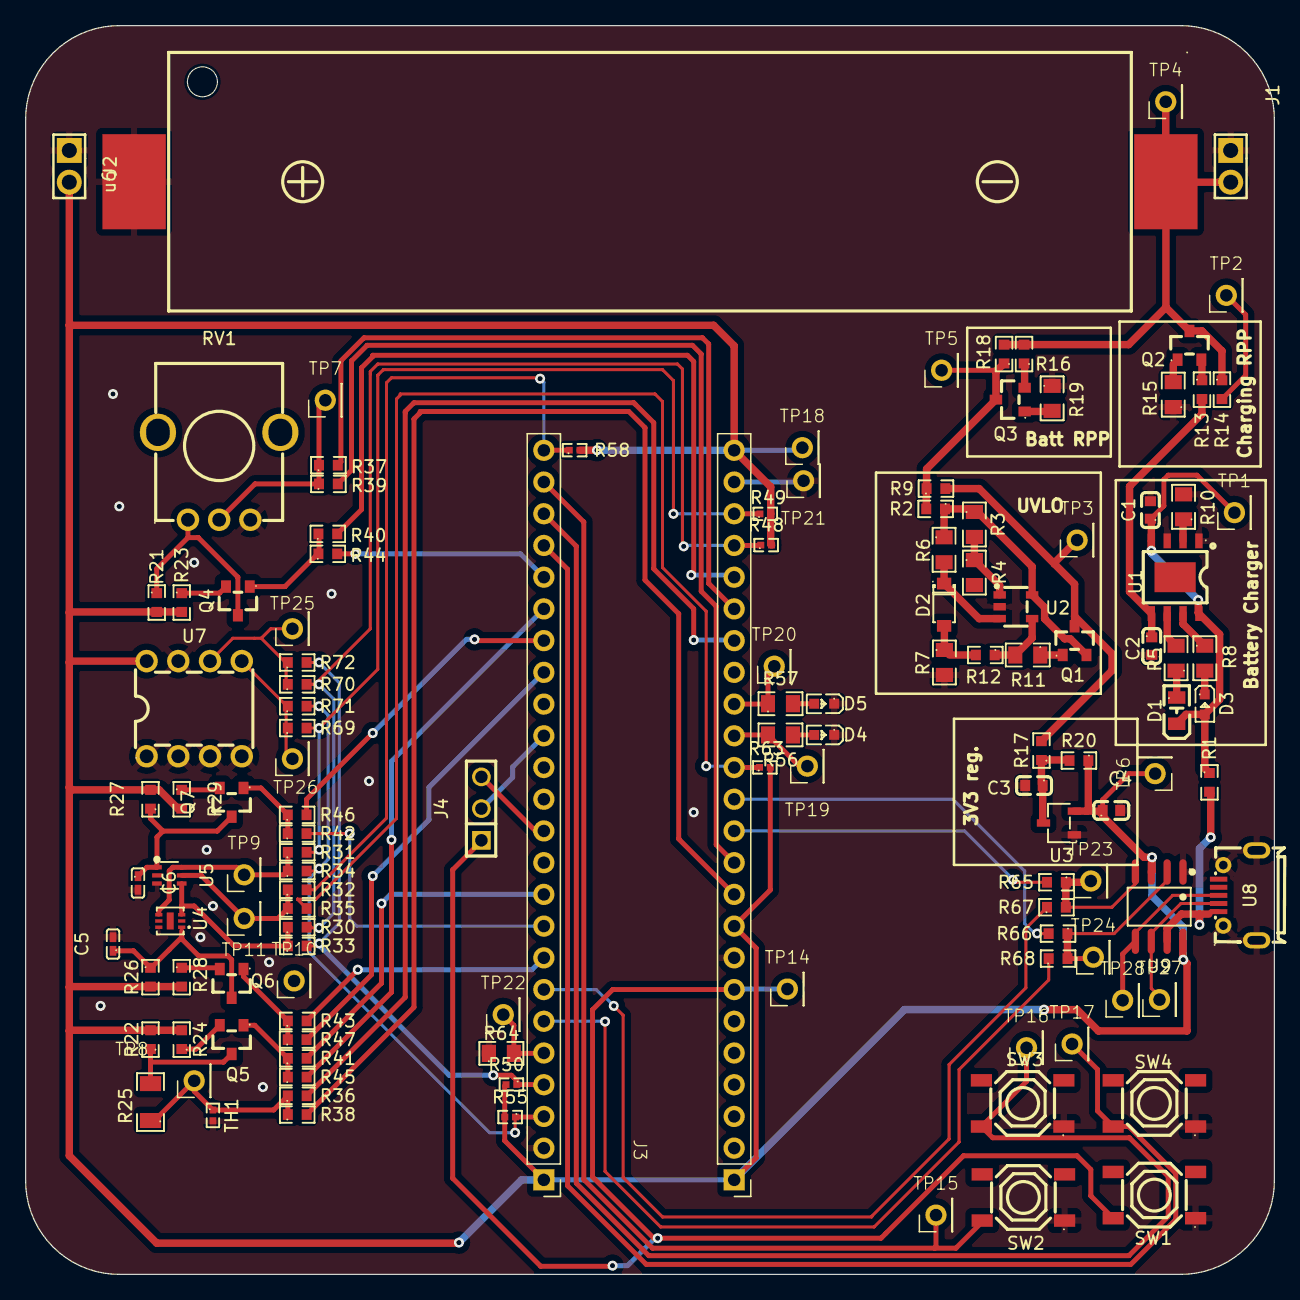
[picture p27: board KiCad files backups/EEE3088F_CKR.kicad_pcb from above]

Board: 2 copper layers, 100.0 x 100.0 mm, 127 parts (0 on the bottom side), 80 nets.

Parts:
C1, C2, C3, C4: 10uf; C0603
C5: 100n; C0402_NEW
C6: 1u; C0402
D1: LED Green; LED0805-R-RD
D2: zener diode; SOD-123_L2.8-W1.8-LS3.7-RD
D3: LED RED; LED0603-RD
D4, D5: LED; LED0603-RD
J1, J2: Conn_01x02_Pin; HDR-TH_2P-P2.54-V-M
J3: STM32F051C6_female_header
J4: Debugger; HDR-TH_3P-P2.54_CS-1165SDIG
Q1, Q2, Q3, Q4, Q5, Q6, Q7: AO3401A; SOT-23_L2.9-W1.3-P1.90-LS2.4-BR
R1, R2, R9, R13, R14, R16, R17, R18, R20, R21, R22, R23, R24, R26, R27, R28, R29, R30, R31, R32, R33, R34, R35, R36, R37, R38, R39, R40, R41, R42, R43, R44, R45, R46, R47, R65, R66, R67, R68, R69, R70, R71, R72: 0; R0603
R3, R11: R1M; R0805
R4: R2M; R0805
R5, R8, R10, R15, R19, R56, R57: 1.2k; R0805
R6: 27.5k; R0805
R7, R64: 10k; R0805
R12: R3M; R0603
R25: 100k; R1206
R48, R49, R50, R55: 3.9k; R0402
R58, R63: 8.2k; R0402
RV1: R_Potentiometer; RES-ADJ-TH_RK09K1130AJ3
SW1: Reset switch; SW-SMD_4P-L5.1-W5.1-P3.70-LS6.5-TL-2
SW2, SW3, SW4: switch; SW-SMD_4P-L5.1-W5.1-P3.70-LS6.5-TL-2
TH1: Thermistor; R0402
TP1: 5v; Testpoint_2.54mm
TP2: battery charger; Testpoint_2.54mm
TP3: UVLO; Testpoint_2.54mm
TP4: +battery out; Testpoint_2.54mm
TP5: reverse polarity; Testpoint_2.54mm
TP6: 3.3v out; Testpoint_2.54mm
TP7: Pot ADC; Testpoint_2.54mm
TP8: Therm ADC; Testpoint_2.54mm
TP9: Light SDA; Testpoint_2.54mm
TP10: Light SCL; Testpoint_2.54mm
TP11: Light Interrupt; Testpoint_2.54mm
TP14: NSRT; Testpoint_2.54mm
TP15: Switch1; Testpoint_2.54mm
TP16: Switch2; Testpoint_2.54mm
TP17: Switch3; Testpoint_2.54mm
TP18: STM32 3V3; Testpoint_2.54mm
TP19: STM32 LED1; Testpoint_2.54mm
TP20: STM32 LED2; Testpoint_2.54mm
TP21: STM32 GND; Testpoint_2.54mm
TP22: STM32 BOOT0; Testpoint_2.54mm
TP23: STM32 Tx; Testpoint_2.54mm
TP24: STM32 Rx; Testpoint_2.54mm
TP25: EEPROM SDA; Testpoint_2.54mm
TP26: EEPROM SCL; Testpoint_2.54mm
TP27: USB D-; Testpoint_2.54mm
TP28: USB D+; Testpoint_2.54mm
U1: Battery Charger; ESOP-8_L4.9-W3.9-P1.27-LS6.0-BL-EP
U2: LMV321; SOT-23-5_L3.0-W1.7-P0.95-LS2.8-BR
U3: XC6206PxxxMR; SOT-23-3_L2.9-W1.6-P1.90-LS2.8-BR
U4: GXHTC3; DFN-6_L2.0-W2.0-P0.50-BL-EP
U5: LTR-303ALS-01; SOT-363_L2.0-W1.3-P0.65-LS2.1-BL
U7: 24LC256; PDIP-8_L9.3-W6.4-P2.54-LS7.6-BL
U8: usb; MICRO-USB-SMD_MICROXNJ
U9: HT42B534-2; SOIC-8_L4.9-W3.9-P1.27-LS6.0-BL
u6: battery holder; BATTERY-SMD_18650-1S-L77.1-W20.7-1

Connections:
+3V3: C4.1, J2.2, J3.1 (_VBAT), J3.9 (_VDDA), J3.24 (_VDD), J3.48 (VDD_), R20.1, R21.2, R22.2, R23.2, R24.2, R26.2, R27.2, R28.2, R29.2, R48.2, R49.2, R50.2, R55.2, R58.2, R63.2, TP6.1, TP18.1, U3.2 (VO), U7.8 (VCC), U9.3 (VDDIO), U9.8 (V330)
+5V: R1.2, U8.1 (VBUS), U9.7 (VDD)
/Microcontroller/BOOT0: J3.44 (BOOT0_), R64.2, TP22.1
/Microcontroller/INT_1: J3.25 (PB12_), R32.2, R58.1
/Microcontroller/INT_2: J3.14 (_PA4), R35.2, R63.1
/Microcontroller/LED1_1: J3.15 (_PA5), R56.1, TP19.1
/Microcontroller/LED2_1: J3.16 (_PA6), R57.1, TP20.1
/Microcontroller/Lght_P_1: J3.40 (PB4_), R42.2
/Microcontroller/Lght_P_2: J3.31 (PA10_), R46.2
/Microcontroller/Light_powerenable: Q7.1 (G), R42.1, R46.1
/Microcontroller/NSRT: J3.7 (_NSRT), J4.1, SW1.2, TP14.1
/Microcontroller/POT_1: J3.19 (_PB1), R37.2
/Microcontroller/POT_2: J3.11 (_PA1), R39.2
/Microcontroller/POT_P_1: J3.20 (_PB2), R40.2
/Microcontroller/POT_P_2: J3.29 (PA8_), R44.2
/Microcontroller/Potentiometer_powerenable: Q4.1 (G), R40.1, R44.1
/Microcontroller/Potentiometer_signal: R37.1, R39.1, RV1.2, TP7.1
/Microcontroller/Rx: R66.1, R68.2, TP24.1, U9.2 (Tx)
/Microcontroller/Rx_1: J3.43 (PB7_), R68.1
/Microcontroller/Rx_2: J3.13 (_PA3), R66.2
/Microcontroller/SCL_1: J3.21 (_PB10), R30.2, R48.1, R70.2
/Microcontroller/SCL_2: J3.45 (PB8_), R33.2, R50.1, R72.2
/Microcontroller/SDA_1: J3.22 (_PB11), R31.2, R49.1, R69.2
/Microcontroller/SDA_2: J3.46 (PB9_), R34.2, R55.1, R71.2
/Microcontroller/SW1: J3.26 (PB13_), SW2.2, TP15.1
/Microcontroller/SW2: J3.27 (PB14_), SW3.2, TP16.1
/Microcontroller/SW3: J3.28 (PB15_), SW4.2, TP17.1
/Microcontroller/SWCLK: J3.37 (PA14_), J4.3
/Microcontroller/SWDIO: J3.34 (PA13_), J4.2
/Microcontroller/THM_1: J3.18 (_PB0), R36.2
/Microcontroller/THM_2: J3.10 (_PA0), R38.2
/Microcontroller/THM_P_1: J3.39 (PB3_), R41.2
/Microcontroller/THM_P_2: J3.30 (PA9_), R45.2
/Microcontroller/TeHu_P_1: J3.41 (PB5_), R43.2
/Microcontroller/TeHu_P_2: J3.32 (PA11_), R47.2
/Microcontroller/TemperatureHumidity_powerenable: Q6.1 (G), R43.1, R47.1
/Microcontroller/Thermistor_powerenable: Q5.1 (G), R41.1, R45.1
/Microcontroller/Thermistor_signal: R25.1, R36.1, R38.1, TH1.1, TP8.1
/Microcontroller/Tx: R65.1, R67.2, TP23.1, U9.4 (Rx)
/Microcontroller/Tx_1: J3.42 (PB6_), R67.1
/Microcontroller/Tx_2: J3.12 (_PA2), R65.2
/Power/3.3V UVLO/polarity protector: Q1.3 (D), R9.2, R17.2, TP3.1
/Power/polarity protected battery voltage: Q3.3 (D), R2.2, R9.1, R18.1, TP5.1
/Sensors/Light_SCL: R30.1, R33.1, TP10.1, U4.3 (SCL), U5.4 (SCL)
/Sensors/Light_SDA: R31.1, R34.1, TP9.1, U4.4 (SDA), U5.6 (SDA)
/Sensors/Light_interrupt: R32.1, R35.1, TP11.1, U5.5 (INT)
GND: C1.2, C2.2, C3.2, C4.2, C5.2, C6.2, D4.1 (K), D5.1 (K), J1.1, J2.1, J3.8 (_VSSA), J3.23 (_VSS), J3.47 (VSS_), R4.2, R7.2, R10.2, R15.1, R19.1, R64.1, RV1.3, SW1.1, SW2.1, SW3.1, SW4.1, TH1.2, TP21.1, U1.1 (TEMP), U1.3 (GND), U2.2 (V-), U3.1 (GND), U4.6 (GND), U5.3 (GND), U7.1 (A0), U7.2 (A1), U7.3 (A2), U7.4 (GND), U7.7 (WP), U8.5 (GND), U8.6 (SH1), U8.7 (SH2), U8.8 (SH3), U8.9 (SH4), U9.1 (GND), u6.2 (-)
unnamed: C3.1, R17.1, R20.2, U3.3 (VI)
unnamed: Q1.2 (S), R2.1, R3.1, R6.1, U2.5 (V+)
unnamed: C5.1, Q6.3 (D), R26.1, U4.1 (VDD)
unnamed: C6.1, Q7.3 (D), R27.1, U5.1 (VDD)
unnamed: C1.1, D1.2 (A), D3.2 (A), R1.1, TP1.1, U1.4 (Vcc), U1.8 (CE)
unnamed: D1.1 (K), R5.1
unnamed: D2.2, R7.1, R12.2
unnamed: D3.1 (K), R8.2
unnamed: D4.2 (A), R56.2
unnamed: D5.2 (A), R57.2
unnamed: J1.2, Q2.3 (D), R14.1, R16.2, R18.2, TP4.1, u6.1 (+)
unnamed: Q1.1 (G), R11.1
unnamed: Q2.1 (G), R15.2
unnamed: Q2.2 (S), R13.1
unnamed: Q3.1 (G), R19.2
unnamed: Q3.2 (S), R16.1
unnamed: Q4.3 (D), R21.1, RV1.1
unnamed: Q4.2 (S), R23.1
unnamed: Q5.3 (D), R22.1, R25.2
unnamed: Q5.2 (S), R24.1
unnamed: Q6.2 (S), R28.1
unnamed: Q7.2 (S), R29.1
unnamed: R11.2, R12.1, U2.4
unnamed: C2.1, R13.2, R14.2, TP2.1, U1.5 (BAT)
unnamed: R8.1, U1.7 (CHRG)
unnamed: R10.1, U1.2 (PROG)
unnamed: R5.2, U1.6 (STDBY#)
unnamed: R3.2, R4.1, U2.1 (+)
unnamed: D2.1, R6.2, U2.3 (-)
unnamed: R70.1, R72.1, TP25.1, U7.6 (SCL)
unnamed: R69.1, R71.1, TP26.1, U7.5 (SDA)
unnamed: TP28.1, U8.3 (D+), U9.5 (D+)
unnamed: TP27.1, U8.2 (D-), U9.6 (D-)

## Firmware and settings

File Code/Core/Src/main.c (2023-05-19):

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
/* Includes ------------------------------------------------------------------*/
#include "main.h"

/* USER CODE BEGIN PD */
#define DATA_THERMISTOR (0)
#define DATA_POTENTIOMETER (1)
#define DATA_LIGHT_ALL (2)
#define DATA_LIGHT_IR (3)
#define DATA_TEMPERATURE (4)
#define DATA_HUMIDITY (5)

#define MODE_STANDBY (0)
#define MODE_RECORD_DATA (1)
#define MODE_READ_DATA (2)
#define MODE_LIVE_DATA (3)
#define MODE_SET_SAMPLE_TIME (4)

#define UTF_N (0x4E)
#define UTF_Y (0x59)
#define UTF_SPACE (0x20)
#define UTF_RETURN (0xD)

//*LIGHT SENSOR */
//Slave addresses
#define LIGHT_ADDR (0x29 << 1)

//Control
#define LIGHT_CONTR (0x80)
#define LIGHT_CONTR_ACTIVE (0x1)

#define LIGHT_MEAS_RATE (0x85)
#define LIGHT_MEAS_RATE_100ms_50ms (0x00)

#define LIGHT_INTERRUPT (0x8F)
#define LIGHT_INTERRUPT_INTERRUPT_ON_MEASURE (0b0001010)

#define LIGHT_STATUS (0x8C)
#define LIGHT_STATUS_NEW_DATA (0x04)

//Data
#define LIGHT_DATA_1_L (0x88)
#define LIGHT_DATA_1_H (0x89)
#define LIGHT_DATA_0_L (0x8A)
#define LIGHT_DATA_0_H (0x8B)
//*LIGHT SENSOR END */

//*TEMPERATURE HUMIDITY SENSOR*/
//Slave address
#define TH_ADDR (0x70 << 1)

//Control
#define TH_SLEEP (0xB098)
#define TH_WAKE (0x3517)
#define TH_READ_DATA (0x7866)

//Data
#define TH_DATA_TEMP_H (0)
#define TH_DATA_TEMP_L (1)
#define TH_DATA_HUM_H (3)
#define TH_DATA_HUM_L (4)

//*TEMPERATURE HUMIDITY SENSOR END*/

//*EEPROM*/
#define EEPROM_ADDR (0b1010000 << 1)
#define EEPROM_ENTRY_SIZE (18) //bytes

#define PAGE_YEAR (0)
#define PAGE_MONTH (1)
#define PAGE_DATE (2)
#define PAGE_HOUR (3)
#define PAGE_MINUTE (4)
#define PAGE_SECOND (5)
#define PAGE_THERMISTOR_H  (6)
#define PAGE_THERMISTOR_L  (7)
#define PAGE_POTENTIOMETER_H (8)
#define PAGE_POTENTIOMETER_L (9)
#define PAGE_LIGHT_ALL_H (10)
#define PAGE_LIGHT_ALL_L (11)
#define PAGE_LIGHT_IR_H (12)
#define PAGE_LIGHT_IR_L (13)
#define PAGE_TEMPERATURE_H (14)
#define PAGE_TEMPERATURE_L (15)
#define PAGE_HUMIDITY_H (16)
#define PAGE_HUMIDITY_L (17)
//#define PAGE_ ()
//*EEPROM END*/

/* USER CODE END PD */

ADC_HandleTypeDef hadc;

I2C_HandleTypeDef hi2c1;

RTC_HandleTypeDef hrtc;

TIM_HandleTypeDef htim6;

UART_HandleTypeDef huart1;

/* USER CODE BEGIN PV */
uint16_t data[6];
uint16_t eeprom_page_addr = 0x00;
uint8_t plg_dtcted = 0, mode = 0, second_elapsed = 0, sample_time = 0;

#define SAMPLE_TIMES_DIVISIONS (455)
const uint8_t SAMPLE_TIMES[] = {1, 2, 5, 10, 15, 30, 45, 60, 120};
const uint8_t UART_SAMPLE_TIME_SET[] = "Sample time set to ";
const uint8_t UART_SAMPLE_TIMES[][3] = {"  1", "  2", "  5", " 10", " 15", " 30", " 45", " 60", "120"};
const uint8_t UART_SECONDS[] = " s\r\n";

const uint8_t UART_MODE_START[][25] = {"Standby mode...\r\n", "Recording data mode...\r\r\n", "Reading data mode...\r\n", "Live data mode...\r\n", "Setting sample time...\r\n"};

const uint8_t UART_START_PACKET[] = "<Packet Start>\r\n";
const uint8_t UART_END_PACKET[] = "<Packet End>\r\r\n";
const uint8_t UART_SENSOR_PREFIX[][20] = {"Thermistor:\t", "Potentiometer:\t", "Light (Visible):\t", "Light (Infrared):\t", "Temperature:\t", "Humidity:\t\t"};

const uint8_t UART_NO_DATA[] = "There is no data stored to transmit\r\r\n";
const uint8_t UART_LOGON[] = "Device Logged On\r\r\n";
const uint8_t UART_TRANSMISSION_START[] = "Data transmission from EEPROM:\r\n";
const uint8_t UART_TABLE_HEADER[] = "CSV format: DD.MM.YY,HH.MM.SS,Thermistor,Potentiometer,Light(Visible),Light(Infrared),Temperature,Humidity\r\n";
const uint8_t UART_TABLE_LINE[] = "---------------------------------------------------\r\n";
const uint8_t UART_TRANSMISSION_END[] = "Data transmission complete\r\r\n";
const uint8_t UART_DATA_DELETE[] = "Would you like to erase the EEPROM? (Y/N)\r\n";

const uint8_t UART_DATA_ERASED[] = "\r\nData has been erased\r\r\n";
const uint8_t UART_DATA_NOT_ERASED[] = "\r\nData has not been erased\r\r\n";
const uint8_t UART_NO_REPLY_DETECTED[] = "\r\nNo reply detected, please reply with 'Y' or 'N'\r\n";
const uint8_t UART_INVALID_REPLY_DETECTED[] = "\r\nInvalid reply detected, please reply with 'Y' or 'N'\r\n";

const uint8_t UART_NEWLINE[] = "\r\n";
/* USER CODE END PV */

void SystemClock_Config(void);
static void MX_GPIO_Init(void);
static void MX_ADC_Init(void);
static void MX_I2C1_Init(void);
static void MX_RTC_Init(void);
static void MX_USART1_UART_Init(void);
static void MX_TIM6_Init(void);
/* USER CODE BEGIN PFP */
void changeMode(int MODE_CODE);
void setSampleTime(void);
void readData(void);
void storeData(void);
void retrieveData(void);
void liveData(void);
void transmitFromIndex(int index, int newline);
/* USER CODE END PFP */

/**
  * @brief  The application entry point.
  * @retval int
  */
int main(void)
{
  /* MCU Configuration--------------------------------------------------------*/

  /* Reset of all peripherals, Initializes the Flash interface and the Systick. */
  HAL_Init();

  /* Configure the system clock */
  SystemClock_Config();

  /* Initialize all configured peripherals */
  MX_GPIO_Init();
  MX_ADC_Init();
  MX_I2C1_Init();
  MX_RTC_Init();
  MX_USART1_UART_Init();
  MX_TIM6_Init();
  /* USER CODE BEGIN 2 */
//  HAL_Delay(10000);

  //setup light sensor
  uint8_t buf[1];
  HAL_Delay(200);
  HAL_I2C_IsDeviceReady(&hi2c1, LIGHT_ADDR, 2, 1000);
  buf[0] = LIGHT_MEAS_RATE_100ms_50ms;
  HAL_I2C_Mem_Write(&hi2c1, LIGHT_ADDR, LIGHT_MEAS_RATE, 1, buf, 1, 1000);
  HAL_Delay(10);

  //get EEPROM address to write to
  HAL_I2C_IsDeviceReady(&hi2c1, EEPROM_ADDR, 2, 1000);
  HAL_Delay(10);
  HAL_I2C_Mem_Read(&hi2c1, EEPROM_ADDR, 0x0000, 2, buf, 1, 1000);
  eeprom_page_addr = buf[0];
  HAL_Delay(10);

  HAL_TIM_Base_Start_IT(&htim6);
  /* USER CODE END 2 */

  /* Infinite loop */
  /* USER CODE BEGIN WHILE */
  uint8_t SW2_down = 0x00, SW3_down = 0x00, SW4_down = 0x00;
  while (1)
  {
	  //handle plug detect
	  if ((GPIOB->IDR & GPIO_IDR_14) == GPIO_IDR_14) {
		  if (!plg_dtcted) {
			  HAL_Delay(5000);
			  HAL_UART_Transmit(&huart1, UART_LOGON, sizeof(UART_LOGON), 10);
			  plg_dtcted = 1;
		  }
	  } else if (plg_dtcted) plg_dtcted = 0;

	  //select mode
	  if ((GPIOB->IDR & GPIO_IDR_3) == 0b0) {
		  //SW2 pressed
		  if (!SW2_down) {
			  SW2_down = 0b1;
			  if (mode == MODE_SET_SAMPLE_TIME) {
				  changeMode(MODE_RECORD_DATA);
			  } else {
				  sample_time = 0;
				  changeMode(MODE_SET_SAMPLE_TIME);
			  }
		  }
	  }	else SW2_down = 0b0;

	  if ((GPIOA->IDR & GPIO_IDR_15) == 0b0){
		  //SW3 pressed
		  if (!SW3_down) {
			  SW3_down = 0b1;
			  changeMode(MODE_READ_DATA);
		  }
	  }	else SW3_down = 0b0;

	  if ((GPIOB->IDR & GPIO_IDR_15) == 0b0){
		  //SW4 pressed
		  if (!SW4_down) {
			  SW4_down = 0b1;
		  changeMode(MODE_LIVE_DATA);
		  }
	  } else SW4_down = 0b0;


    /* USER CODE END WHILE */

    /* USER CODE BEGIN 3 */
  }
  /* USER CODE END 3 */
}

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
/* USER CODE BEGIN 4 */
void changeMode(int MODE_CODE) {
	mode = MODE_CODE;
	HAL_UART_Transmit(&huart1, UART_MODE_START[MODE_CODE], sizeof(UART_MODE_START[MODE_CODE]), 10);

	if (MODE_CODE == MODE_SET_SAMPLE_TIME) MODE_CODE = MODE_LIVE_DATA;
	GPIOB->ODR &= ~(0b11 << 12); //turn off LEDs
	GPIOB->ODR |= (mode << 12);
}

void HAL_TIM_PeriodElapsedCallback(TIM_HandleTypeDef *htim)
{
  // Check which version of the timer triggered this callback and toggle LED
  if (htim == &htim6)
  {
	  second_elapsed++;

	  switch (mode) {
	  case MODE_RECORD_DATA:
		  if (second_elapsed < sample_time) break;
		  readData();
		  storeData();
		  second_elapsed = 0;
		  break;
	  case MODE_STANDBY:
		  if (second_elapsed < 1) break;
		  HAL_GPIO_TogglePin(GPIOB, GPIO_PIN_12);
		  HAL_GPIO_TogglePin(GPIOB, GPIO_PIN_13);
		  second_elapsed = 0;
		  break;
	  case MODE_SET_SAMPLE_TIME:
		  readData();
		  setSampleTime();
		  break;
	  case MODE_READ_DATA:
		  retrieveData();
		  changeMode(MODE_STANDBY);
		  break;
	  case MODE_LIVE_DATA:
		  if (second_elapsed < 2) break;
		  readData();
		  liveData();
		  second_elapsed = 0;
		  break;
	  }
  }
}


void readData(void) {
	//check calibration, if not calibrate
	ADC1->CR |= ADC_CR_ADCAL;
	while ((ADC1->CR & ADC_CR_ADCAL) == ADC_CR_ADCAL);

	//check if ADC is RDY
	if ((ADC1->ISR & ADC_ISR_ADRDY) == 0b0) {
		ADC1->CR |= ADC_CR_ADEN;
		while ((ADC1->ISR & ADC_ISR_ADRDY) == 0b0);
	}

	//read thermistor data 12-bit res
	ADC1->CR |= ADC_CR_ADSTART;
	while ((ADC1->ISR & ADC_ISR_EOC) == 0b0);
	data[DATA_THERMISTOR] = ADC1->DR;

	//read potentiometer data 12-bit res
	ADC1->CR |= ADC_CR_ADSTART;
	while ((ADC1->ISR & ADC_ISR_EOC) == 0b0);
	data[DATA_POTENTIOMETER] = ADC1->DR;
	ADC1->ISR &= ~(ADC_ISR_EOS);

	//stop ADC
	ADC1->CR |= ADC_CR_ADSTP;
	while ((ADC1->CR & ADC_CR_ADSTP) == ADC_CR_ADSTP);
	//disable ADC
	ADC1->CR |= ADC_CR_ADDIS;
	while ((ADC1->CR & ADC_CR_ADDIS) == ADC_CR_ADDIS);

	//I2C data retrieval
	//LIGHT SENSOR
	uint8_t buf[6];
	HAL_StatusTypeDef ref;

	ref = HAL_I2C_IsDeviceReady(&hi2c1, LIGHT_ADDR, 2, 1000);

	buf[0] = LIGHT_CONTR_ACTIVE;
	ref = HAL_I2C_Mem_Write(&hi2c1, LIGHT_ADDR, LIGHT_CONTR, 1, buf, 1, 1000);

	//wait until new_data is high
	ref = HAL_I2C_Mem_Read(&hi2c1, LIGHT_ADDR, LIGHT_STATUS, 1, buf, 1, 1000);
	while ((buf[0] & LIGHT_STATUS_NEW_DATA) == 0b0) {
		ref = HAL_I2C_Mem_Read(&hi2c1, LIGHT_ADDR, LIGHT_STATUS, 1, buf, 1, 1000);
	}

	//read data
	ref = HAL_I2C_Mem_Read(&hi2c1, LIGHT_ADDR, LIGHT_DATA_1_L, 1, buf, 1, 1000);
	data[DATA_LIGHT_IR] = buf[0];
	ref = HAL_I2C_Mem_Read(&hi2c1, LIGHT_ADDR, LIGHT_DATA_1_H, 1, buf, 1, 1000);
	data[DATA_LIGHT_IR] |= (buf[0] << 8);
	ref = HAL_I2C_Mem_Read(&hi2c1, LIGHT_ADDR, LIGHT_DATA_0_L, 1, buf, 1, 1000);
	data[DATA_LIGHT_ALL] = buf[0];
	ref = HAL_I2C_Mem_Read(&hi2c1, LIGHT_ADDR, LIGHT_DATA_0_H, 1, buf, 1, 1000);
	data[DATA_LIGHT_ALL] |= (buf[0] << 8);

	buf[0] = 0x00;
	ref = HAL_I2C_Mem_Write(&hi2c1, LIGHT_ADDR, LIGHT_CONTR, 1, buf, 1, 1000);

	//TEMPERATURE HUMIDITY
	ref = HAL_I2C_IsDeviceReady(&hi2c1, TH_ADDR, 2, 1000);

	buf[0] = (TH_WAKE >> 8);
	buf[1] = (TH_WAKE);
	ref = HAL_I2C_Master_Transmit(&hi2c1, TH_ADDR, buf, 2, 1000);

	buf[0] = (TH_READ_DATA >> 8);
	buf[1] = (TH_READ_DATA);
	ref = HAL_I2C_Master_Transmit(&hi2c1, TH_ADDR, buf, 2, 1000);

	//read data
	buf[0] = 0x00; buf[1] = 0x00; buf[2] = 0x00; buf[3] = 0x00; buf[4] = 0x00; buf[5] = 0x00;
	while (HAL_I2C_Master_Receive(&hi2c1, TH_ADDR, buf, 6, 1000) != HAL_OK);
	data[DATA_TEMPERATURE] = ((buf[TH_DATA_TEMP_H] << 8) | buf[TH_DATA_TEMP_L]);
	data[DATA_HUMIDITY] = ((buf[TH_DATA_HUM_H] << 8) | buf[TH_DATA_HUM_L]);


	buf[0] = (TH_SLEEP >> 8);
	buf[1] = (TH_SLEEP);
	ref = HAL_I2C_Master_Transmit(&hi2c1, TH_ADDR, buf, 2, 1000);

}

void setSampleTime(void) {
	uint8_t sample_time_index = data[DATA_POTENTIOMETER] / SAMPLE_TIMES_DIVISIONS;
	if (sample_time != SAMPLE_TIMES[sample_time_index]) {
		sample_time = SAMPLE_TIMES[sample_time_index];

		HAL_UART_Transmit(&huart1, UART_SAMPLE_TIME_SET, sizeof(UART_SAMPLE_TIME_SET), 10);
		HAL_UART_Transmit(&huart1, UART_SAMPLE_TIMES[sample_time_index], sizeof(UART_SAMPLE_TIMES[sample_time_index]), 10);
		HAL_UART_Transmit(&huart1, UART_SECONDS, sizeof(UART_SECONDS), 10);
	}
}

void storeData(void) {
	uint8_t page[EEPROM_ENTRY_SIZE];

	RTC_TimeTypeDef sTime;
	RTC_DateTypeDef sDate;
	HAL_RTC_GetTime(&hrtc, &sTime, RTC_FORMAT_BIN);
	HAL_RTC_GetDate(&hrtc, &sDate, RTC_FORMAT_BIN);

	//prepare year.month.date hour.minute.second
	page[PAGE_YEAR] = sDate.Year; page[PAGE_MONTH] = sDate.Month; page[PAGE_DATE] = sDate.Date;
	page[PAGE_HOUR] = sTime.Hours; page[PAGE_MINUTE] = sTime.Minutes; page[PAGE_SECOND] = sTime.Seconds;

	page[PAGE_THERMISTOR_H] = (data[DATA_THERMISTOR] >> 8);
	page[PAGE_THERMISTOR_L] = (data[DATA_THERMISTOR]);

	page[PAGE_POTENTIOMETER_H] = (data[DATA_POTENTIOMETER] >> 8);
	page[PAGE_POTENTIOMETER_L] = (data[DATA_POTENTIOMETER]);

	page[PAGE_LIGHT_ALL_H] = (data[DATA_LIGHT_ALL] >> 8);
	page[PAGE_LIGHT_ALL_L] = (data[DATA_LIGHT_ALL]);

	page[PAGE_LIGHT_IR_H] = (data[DATA_LIGHT_IR] >> 8);
	page[PAGE_LIGHT_IR_L] = (data[DATA_LIGHT_IR]);

	page[PAGE_TEMPERATURE_H] = (data[DATA_TEMPERATURE] >> 8);
	page[PAGE_TEMPERATURE_L] = (data[DATA_TEMPERATURE]);

	page[PAGE_HUMIDITY_H] = (data[DATA_HUMIDITY] >> 8);
	page[PAGE_HUMIDITY_L] = (data[DATA_HUMIDITY]);

	//write data
	HAL_I2C_Mem_Write(&hi2c1, EEPROM_ADDR, (eeprom_page_addr << 6), 2, page, EEPROM_ENTRY_SIZE, 1000);
	eeprom_page_addr++;
	//write page address until acknowledged
	page[0] = eeprom_page_addr;
	while (HAL_I2C_Mem_Write(&hi2c1, EEPROM_ADDR, 0x0000, 2, page, 1, 1000) != HAL_OK);
}

void retrieveData(void) {
	if (eeprom_page_addr == 0x01) {
		HAL_UART_Transmit(&huart1, UART_NO_DATA, sizeof(UART_NO_DATA), 10);
		return;
	}

	HAL_UART_Transmit(&huart1, UART_TRANSMISSION_START, sizeof(UART_TRANSMISSION_START), 10);
	HAL_UART_Transmit(&huart1, UART_TABLE_HEADER, sizeof(UART_TABLE_HEADER), 10);
	HAL_UART_Transmit(&huart1, UART_TABLE_LINE, sizeof(UART_TABLE_LINE), 10);

	uint8_t page[EEPROM_ENTRY_SIZE];
	uint8_t date[9]; uint8_t time[9];

	for (uint16_t addr = 0x01; addr < eeprom_page_addr; addr++) {
		HAL_I2C_Mem_Read(&hi2c1, EEPROM_ADDR, (addr << 6), 2, page, EEPROM_ENTRY_SIZE, 1000);

		sprintf(date,"%02d.%02d.%02d", page[PAGE_DATE], page[PAGE_MONTH], page[PAGE_YEAR]);
		sprintf(time,",%02d.%02d.%02d", page[PAGE_HOUR], page[PAGE_MINUTE], page[PAGE_SECOND]);

		HAL_UART_Transmit(&huart1, (uint8_t *)date, sizeof(date), 1000);
		HAL_UART_Transmit(&huart1, (uint8_t *)time, sizeof(time), 1000);

		data[DATA_THERMISTOR] = ((page[PAGE_THERMISTOR_H] << 8) | page[PAGE_THERMISTOR_L]);
		data[DATA_POTENTIOMETER] = ((page[PAGE_POTENTIOMETER_H] << 8) | page[PAGE_POTENTIOMETER_L]);
		data[DATA_LIGHT_ALL] = ((page[PAGE_LIGHT_ALL_H] << 8) | page[PAGE_LIGHT_ALL_L]);
		data[DATA_LIGHT_IR] = ((page[PAGE_LIGHT_IR_H] << 8) | page[PAGE_LIGHT_IR_L]);
		data[DATA_TEMPERATURE] = ((page[PAGE_TEMPERATURE_H] << 8) | page[PAGE_TEMPERATURE_L]);
		data[DATA_HUMIDITY] = ((page[PAGE_HUMIDITY_H] << 8) | page[PAGE_HUMIDITY_L]);

		transmitFromIndex(DATA_THERMISTOR, 0);
		transmitFromIndex(DATA_POTENTIOMETER, 0);
		transmitFromIndex(DATA_LIGHT_ALL, 0);
		transmitFromIndex(DATA_LIGHT_IR, 0);
		transmitFromIndex(DATA_TEMPERATURE, 0);
		transmitFromIndex(DATA_HUMIDITY, 0);

		HAL_UART_Transmit(&huart1, UART_NEWLINE, sizeof(UART_NEWLINE), 1000);
	}

	HAL_UART_Transmit(&huart1, UART_TABLE_LINE, sizeof(UART_TABLE_LINE), 10);
	HAL_UART_Transmit(&huart1, UART_TRANSMISSION_END, sizeof(UART_TRANSMISSION_END), 10);
	HAL_UART_Transmit(&huart1, UART_DATA_DELETE, sizeof(UART_DATA_DELETE), 10);

	uint8_t buf[1];
	while (1) {
		buf[0] = UTF_SPACE;
		HAL_UART_Receive(&huart1, buf, 1, 20000);
		if (buf[0] == UTF_Y) {
			//'erase' memory (start at 0x00 again)
			buf[0] = 0x01; eeprom_page_addr = 0x01;
			HAL_I2C_Mem_Write(&hi2c1, EEPROM_ADDR, 0x0000, 2, buf, 1, 1000);
			HAL_UART_Transmit(&huart1, UART_DATA_ERASED, sizeof(UART_DATA_ERASED), 10);
			return;
		}
		else if (buf[0] == UTF_N) {
			HAL_UART_Transmit(&huart1, UART_DATA_NOT_ERASED, sizeof(UART_DATA_NOT_ERASED), 10);
			return;
		}
		else if (buf[0] == UTF_SPACE) {
			HAL_UART_Transmit(&huart1, UART_NO_REPLY_DETECTED, sizeof(UART_NO_REPLY_DETECTED), 10);
		}
		else HAL_UART_Transmit(&huart1, UART_INVALID_REPLY_DETECTED, sizeof(UART_INVALID_REPLY_DETECTED), 10);
	}
}

void liveData(void) {
	HAL_UART_Transmit(&huart1, UART_START_PACKET, sizeof(UART_START_PACKET), 10);

	RTC_TimeTypeDef sTime;
	RTC_DateTypeDef sDate;
	HAL_RTC_GetTime(&hrtc, &sTime, RTC_FORMAT_BIN);
	HAL_RTC_GetDate(&hrtc, &sDate, RTC_FORMAT_BIN);

	uint8_t date[16]; uint8_t time[16];

	sprintf(date," Date: %02d.%02d.%02d\t",sDate.Date,sDate.Month,sDate.Year);
	sprintf(time,"Time: %02d.%02d.%02d\r\n",sTime.Hours,sTime.Minutes,sTime.Seconds);

	HAL_UART_Transmit(&huart1, (uint8_t *)date, sizeof(date), 10);
	HAL_UART_Transmit(&huart1, (uint8_t *)time, sizeof(time), 10);

	transmitFromIndex(DATA_THERMISTOR, 1);
	transmitFromIndex(DATA_POTENTIOMETER, 1);
	transmitFromIndex(DATA_LIGHT_ALL, 1);
	transmitFromIndex(DATA_LIGHT_IR, 1);
	transmitFromIndex(DATA_TEMPERATURE, 1);
	transmitFromIndex(DATA_HUMIDITY, 1);

	HAL_UART_Transmit(&huart1, UART_END_PACKET, sizeof(UART_END_PACKET), 10);
}

void transmitFromIndex(int index, int newline) {
	uint16_t data_cpy = data[index];
	uint8_t UART_data[6] = "      ", data_len;
	if (newline)  {
		HAL_UART_Transmit(&huart1, UART_SENSOR_PREFIX[index], sizeof(UART_SENSOR_PREFIX[index]), 10);
		sprintf(UART_data, "%01d\r\n", data_cpy);
	}
	else sprintf(UART_data, ",%01d", data_cpy);

	//get exact length of data then transmit
	for (data_len = 0; data_len < 6; data_len++) if (UART_data[data_len] == '\0') break;
	HAL_UART_Transmit(&huart1, (uint8_t *)UART_data, data_len + 1, 10);
}

/* USER CODE END 4 */
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


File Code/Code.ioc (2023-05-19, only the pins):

Mcu.UserName=STM32F051C6Tx
PA13.Signal=SYS_SWDIO
PA14.Signal=SYS_SWCLK
PA15.Signal=GPIO_Input
PB0.Signal=ADC_IN8
PB1.Signal=ADC_IN9
PB10.Signal=GPIO_Input
PB11.Signal=GPIO_Output
PB12.Signal=GPIO_Output
PB13.Signal=GPIO_Output
PB14.Signal=GPIO_Input
PB15.Signal=GPIO_Input
PB2.Signal=GPIO_Output
PB3.Signal=GPIO_Input
PB4.Signal=GPIO_Output
PB5.Signal=GPIO_Output
PB6.Signal=USART1_TX
PB7.Signal=USART1_RX
PB8.Signal=I2C1_SCL
PB9.Signal=I2C1_SDA
PF0-OSC_IN.Signal=RCC_OSC_IN
PF1-OSC_OUT.Signal=RCC_OSC_OUT

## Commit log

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2023-02-24 added users and requirements excel doc
    [Users and Requirements.xlsx]
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2023-03-04 added microcontroller, power, and sensors
    [microcontroller.kicad_sch]
2023-03-05 kian added power subsistem week 3 Q1.1
    [3.1.xlsx]
2023-03-05 kian made som changes to the scmatices for power an added a libaery called power componentes
    [power.kicad_sch]
2023-03-05 kian made som changes to the scmatices
    [power.kicad_sch]
2023-03-05 finale scamatic for today
    [power.kicad_sch]
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2023-03-05 added Q3 sensors details, started sensors schematic, updated sym-lib-table to reflect renamed files from previous commit
    [sensors.kicad_sch]
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2023-03-05 Updated digital sensor in sensors schematic
    [sensors.kicad_sch]
2023-03-05 fixed up spelling errors
    [BOM final.xlsx, power components.csv]
2023-03-05 minor changes to schematic, added sensor sheet to BOM
    [BOM final.xlsx, Power BOM.xlsx, sensors.kicad_sch]
2023-03-05 not 100% sure but I probably updated some stuff
    [sensors.kicad_sch]
2023-03-05 updated BOM with microcontoller
    [EEE3088F_CKR.csv]
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2023-03-05 added thermister stuff to BOM
    [BOM.xlsx]
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2023-03-06 added pot and 2nd I2C pin to microcontroller schematic
    [microcontroller.kicad_sch]
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2023-03-06 added assign. 2 submission
    [BOM.xlsx]
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2023-03-07 changed battery to DNP
    [power.kicad_sch]
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2023-03-07 added microcontoller female header part
    [microcontroller.kicad_sch]
2023-03-07 changed such that only headers are placed on board
    [microcontroller.kicad_sch]
2023-03-07 added heirachals and connected subsheets
    [EEE3088F_CKR.kicad_sch, microcontroller.kicad_sch, power.kicad_sch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]
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2023-03-10 added USB to UART connector and made a dedicated USB sheet
    [EEE3088F_CKR.kicad_sch, USB.kicad_sch, microcontroller.kicad_sch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]
2023-03-11 Added sheet notes and initial design template, reordered microcontoller subsheet and add microntoller subsheet notes
    [EEE3088F_CKR.kicad_sch, USB.kicad_sch, microcontroller.kicad_sch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]
2023-03-11 some changes to power
    [power.kicad_sch]
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2023-03-13 started adding temperature & humidity sensor to sensors schematic, small changes to rob week 4 doc
    [EEE3088F_CKR.kicad_sch, USB.kicad_sch, microcontroller.kicad_sch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]
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2023-03-13 added failure mitigations and updated BOM
    [BOM.xlsx, EEE3088F_CKR.kicad_sch, USB.kicad_sch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]
2023-03-13 changes to sensor schematic :
    [power.kicad_sch, sensors.kicad_sch]
2023-03-13 updated sensor and microcontroller schematics
    [EEE3088F_CKR.kicad_sch, USB.kicad_sch, microcontroller.kicad_sch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]
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2023-03-14 edited circuit diagram in template design
    [microcontroller.kicad_sch, power.kicad_sch]
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2023-03-14 finalised initial template design
    [BOM.xlsx]
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2023-03-18 power Updated added test points and some 0 ohm resistors as well as trying to fix off-grid problem
    [power.kicad_sch]
2023-03-19 sensors schematic changes, net label name changes
    [power.kicad_sch, sensors.kicad_sch]
2023-03-19 added test points to sensor schem
    [sensors.kicad_sch]
2023-03-19 Added testpoint and changed headers to 0Ωs
    [USB.kicad_sch, microcontroller.kicad_sch]
2023-03-19 Added more test points
    [microcontroller.kicad_sch]
2023-03-19 updated 0Ω to be DNP
    [microcontroller.kicad_sch]
2023-03-19 changed a bunch of net labels, changed some uc schem stuff
    [EEE3088F_CKR.kicad_sch, USB.kicad_sch, microcontroller.kicad_sch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]
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2023-03-19 updated net labelling scheme on schematic, changed some port connections on microcontroller
    [EEE3088F_CKR.kicad_sch, USB.kicad_sch, microcontroller.kicad_sch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]
2023-03-20 ran ERCs and fixed the errors
    [EEE3088F_CKR.kicad_sch, USB.kicad_sch, microcontroller.kicad_sch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]
2023-03-20 bom updated and test labes renamed
    [BOM.xlsx, EEE3088F_CKR.kicad_sch, USB.kicad_sch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]
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2023-03-20 lots of suf for pcb diseng
    [microcontroller.kicad_sch, power.kicad_sch, sensors.kicad_sch]
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2023-03-20 lots of PCB stuff
    [EEE3088F_CKR.kicad_pcb, power.kicad_sch, sensors.kicad_sch]
2023-03-21 the PCB suffered - wired up the micro controller
    [EEE3088F_CKR.kicad_pcb, microcontroller.kicad_sch, power.kicad_sch]
2023-03-21 double checking my push
    [EEE3088F_CKR.kicad_pcb]
2023-03-21 a few random vias
    [EEE3088F_CKR.kicad_pcb]
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2023-03-21 power scamtic wire added
    [power.kicad_sch]
2023-03-21 week 5 writeup and a lot of changes to PCB design
    [EEE3088F_CKR-B_Cu.gbr, EEE3088F_CKR-B_Mask.gbr, EEE3088F_CKR-B_Paste.gbr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]
2023-03-24 cleaned up git order
    [3.1.xlsx, Users and Requirements.xlsx, power components.csv]
2023-03-27 power peer review done
    [3.1.xlsx, Users and Requirements.xlsx, power components.csv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]
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2023-03-31 powwer 5v line seperation
    [EEE3088F_CKR.kicad_pcb, EEE3088F_CKR.kicad_sch, USB.kicad_sch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]
2023-03-31 Removed extra 0ohms, added microcontroller male header
    [EEE3088F_CKR.kicad_sch, USB.kicad_sch, microcontroller.kicad_sch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]
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2023-04-02 any residual changes from previous commit
    [USB.kicad_sch, microcontroller.kicad_sch, power.kicad_sch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]
2023-04-02 Corrected all part numbers and small schematic changes
    [EEE3088F_CKR.kicad_sch, USB.kicad_sch, microcontroller.kicad_sch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]
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2023-04-02 Final schematic changes and start board design
    [EEE3088F_CKR.kicad_pcb, USB.kicad_sch, microcontroller.kicad_sch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]
2023-04-03 literally just added one 0ohm resistor
    [EEE3088F_CKR.kicad_pcb, USB.kicad_sch, microcontroller.kicad_sch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]
2023-04-03 Lots of PCB design
    [EEE3088F_CKR.csv, EEE3088F_CKR.kicad_pcb, EEE3088F_CKR.kicad_sch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]
2023-04-04 finally finished PCB design
    [EEE3088F_CKR.kicad_pcb, microcontroller.kicad_sch]
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

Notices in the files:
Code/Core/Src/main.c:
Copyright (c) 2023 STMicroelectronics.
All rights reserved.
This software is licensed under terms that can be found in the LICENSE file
